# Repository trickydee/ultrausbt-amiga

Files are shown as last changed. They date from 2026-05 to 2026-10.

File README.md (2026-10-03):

# Amiga USB & Bluetooth Adapter

## Overview

This project uses a Raspberry Pi Pico to connect modern USB and Bluetooth devices such as keyboards, mice, trackballs and gamepads to classic Amiga computers — without needing a USB stack on the Amiga itself.

The project was created so I could connect my modern peripherals with my Amiga 2000, the device has a Keyboard and 2 x Atari style Joystick connectors to interface with the Amiga.

The example adapter hardware for the project is focused on the Amiga 2000, although it can be adapted easily for other Amigas.

The adapter is bi-directional:

* **Device Mode** (default): modern USB/Bluetooth HID → Amiga keyboard, mouse, joystick, and CD32 pad signalling
* **Host Mode**: real Amiga keyboard + Port 1 mouse + Port 2 Atari stick → USB HID keyboard/mouse/gamepad on a modern PC

Joystick/CD32 pads are supported toward the Amiga in Device Mode. In Host Mode, Port 2 accepts an Atari-style two-button stick as a USB HID gamepad (Mega Drive pads deferred — see [`doc/host-mode-port2-joystick.md`](./doc/host-mode-port2-joystick.md)).

The device is connected to the Amiga using straight through cables, I am using 2 x 9 Pin DSub to Dsub and 1 x 5 Pin DIN (MIDI) cables.

On a **Pico 2 W** you can mix USB and Bluetooth devices. USB-only builds work on any Pico / Pico 2.

**This project is a fork of [amigahid-pico](https://github.com/borb/amigahid-pico)** by **just nine** (borb). That project is the foundation for Amiga keyboard and mouse signalling on the Pico. This fork builds on that work for the ultrausbt Amiga Adapter board: OLED UI, dual joystick ports, CD32 pad protocol, Bluetooth (Bluepad32), many modern USB controllers, and USB **device** mode (Amiga keyboard/mouse → PC).

Please visit and star the upstream project:  
**https://github.com/borb/amigahid-pico**

Current firmware: **v4.2.0** (`main`) · [Release notes](./RELEASE_NOTES.md) · Architecture: [`doc/architecture.md`](./doc/architecture.md) · License: [EPL-2.0](./LICENSE) · [NOTICE](./NOTICE)

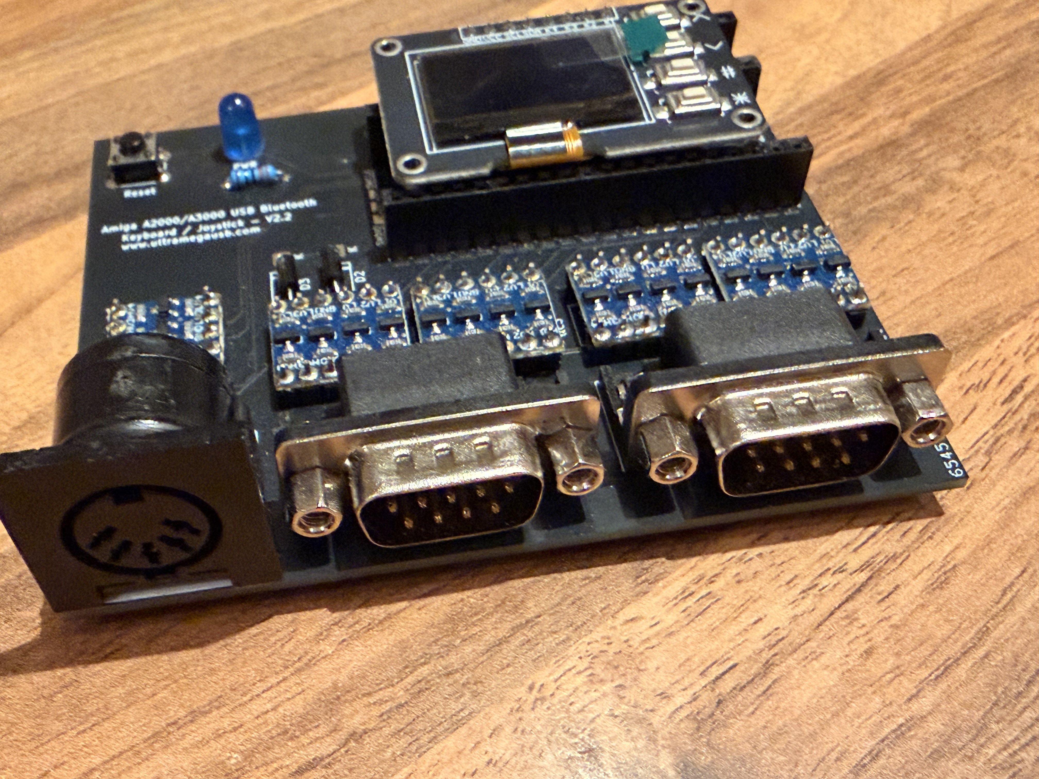
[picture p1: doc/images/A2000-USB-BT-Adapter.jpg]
A2000 USB/BT Adapter


## Contributions

This project is open source and I am happy to receive pull requests and issues to further improve capabilities.

## USB device support

* USB HID Keyboards
* USB HID Mice
* USB HID Gamepads / Joysticks (see below)

## Game controller support

The following USB HID gamepads / joysticks are supported (more to come):

* PlayStation 3 DualShock 3 (and third-party PS3-compatible pads: HORI, Mad Catz, Qanba, Nacon, Logitech F310, etc.)
* PlayStation 4 DualShock 4 (and third-party PS4-compatible pads)
* PlayStation 5 DualSense and DualSense Edge (USB)
* PlayStation Classic (PSC)
* Xbox XInput — Xbox 360 / One / OG (plus HID fallback)
* Nintendo Switch Pro Controller, Joy-Con (L/R/Pair/Grip), SNES Controller (NSO)
* HORI HORIPAD for Nintendo Switch
* Google Stadia Controller

Other USB HID gamepads may work via the generic path (directions + up to three buttons). Gamepads map to **Joystick Port 2** by default; Port 1 can be switched to joystick / Llamatron / CD32 mode from the OLED or keyboard shortcuts.

## Bluetooth support (Pico 2 W)

Bluetooth keyboards, mice, and gamepads are supported on the **Raspberry Pi Pico 2 W** (RP2350) via [Bluepad32](https://github.com/ricardoquesada/bluepad32). You can run a fully wireless Amiga setup, or mix USB and Bluetooth devices.

### Pairing

1. On the OLED splash screen, hold **Middle + Left** (# + Up) to enable pairing (or wait for the short post-boot pairing window).
2. Put your device into Bluetooth pairing mode.
3. Confirm the device on the OLED **Devices** / **Map Devices** screens.

To clear stored pairing keys, open the OLED **Settings** page on the screen carousel (`#` from Map Devices), select **Clear BT pair**, confirm with `#`.

To turn pairing back on after it has timed out or been turned off: **Settings → Pair ON** (or **Middle + Left** / # + Up on Splash).

**Note:** Bluetooth support is intended for Pico 2 W. Prefer Pico 2 W for wireless builds.

# Usage

## USB

Connect devices to the Pico USB port (use a powered USB OTG hub if you need multiple devices). Supported keyboards, mice, and gamepads should enumerate within a few seconds; confirm on the OLED. If you find a modern device that does not work, open an issue.

## Bluetooth

See **Bluetooth support** above. Pairing is controlled from the OLED splash screen. Keyboard shortcuts work the same on USB and Bluetooth keyboards.

## Keyboard shortcuts

The adapter uses a number of Keyboard shortcut key combinations to toggle features.

These combos are handled by the adapter (USB **and** Bluetooth keyboards) and are **not** passed through to the Amiga. **Left Amiga** = Left Command / Left GUI / Left Windows on PC/Mac keyboards.

| Shortcut | Function |
|---|---|
| **Ctrl + Left Amiga + Right Amiga** | Amiga hard reset (classic) |
| **Ctrl + Left Amiga + Backspace** | Amiga hard reset (alternate for keyboards without Right Amiga/GUI) |
| **Shift + Left Amiga + J** | Toggle Port 1 between Amiga mouse and joystick |
| **Shift + Left Amiga + L** | Toggle Llamatron / Robotron style twin-stick mode (Port 2 move + Port 1 aim) |
| **Shift + Left Amiga + C** | Toggle Port 2 CD32 seven-button pad mode |

Port 1 full cycle (Ami Ms → Joy → CD32 → Llama → Atr Ms) is on the OLED **Left** button. Reset is signalled by holding the Amiga keyboard **CLOCK** line low (as a real Amiga keyboard MCU does), with a minimum hold time so it still works when a keyboard drops a combo key from its HID report.

Optional: remap one HID scancode to Amiga **Help** via `KEY_REMAP_HID_TO_HELP` in `src/config.h` (default: Logitech MX `| / ~ #` key). Set to `0` to disable. This is useful for mapping the quit key in WHDload.

### Llamatron dual-stick mode

**Shift + Left Amiga + L** enables Llamatron / twin-stick style routing (one dual-stick gamepad shared across ports: left stick → Port 2 move, right stick → Port 1 aim). Works with **Port 2 CD32** on; mutually exclusive with **Port 1 CD32**. See the OLED Port 1 mode label (**Llama**).

### CD32 seven-button mode

**CD32 pad emulation is complete and working** on both ports:

* **Port 2:** **Shift + Left Amiga + C**, or OLED **Right** (Joy ↔ CD32)
* **Port 1:** OLED **Left** cycle to **CD32** (Ami Ms → Joy → CD32 → Llama → Atr Ms)

Uses the Amiga CD32 serial pad protocol (seven buttons + D-pad). Compatible with Llamatron on Port 2 CD32; exclusive with Port 1 CD32. Protocol detail: [`doc/archive/CD32_BUILD_SPEC.md`](./doc/archive/CD32_BUILD_SPEC.md).

# OLED UI

An SSD1306 OLED and three buttons are supported on the ultrausbt Amiga board (optional for a bare Pico, but recommended). On modules with **Up / Down / #** keys: **Up** = Left, **Down** = Right, **#** = Middle.

The UI is a **screen carousel**: press **#** to advance pages (wraps to Splash).

| Mode | Carousel sequence |
|---|---|
| **Device Mode** (USB/BT → Amiga) | Splash → Devices → Map Devices → Settings → Splash |
| **Host Mode** (Amiga kbd/mouse → PC) | Splash → Settings → Splash (Devices / Map Devices hidden) |

| Control | Action |
|---|---|
| **Left** (Up) | Splash/Devices: cycle Port 1 (Ami Ms → Joy → CD32 → Llama → Atr Ms). Settings: move cursor up |
| **Right** (Down) | Splash/Devices: cycle Port 2 (Joy ↔ CD32). Settings: move cursor down |
| **Middle** (#) | Advance screen carousel; on Settings: confirm selection |
| **Middle + Left** (# + Up) | Toggle Bluetooth pairing (Splash) |
| **Settings → Clear BT pair** | Clear stored Bluetooth pairing keys (`#` then confirm) |
| **Settings → Pair ON / Pair OFF** | Enable or disable Bluetooth pairing (label is the target state) |
| **Settings → Host Mode / Device Mode** | Switch to that role (`#` saves and reboots); label is the target, not current |
| **Settings → Back** | Return to Splash (default selection) |

Splash shows **Device Mode**, both ports in large type (`1:Ami Ms` / `2:Joy`), pairing status bottom-left, and firmware version bottom-right. **Ami Ms** = Amiga mouse, **Atr Ms** = Atari ST mouse pinout on Port 1.

OLED UX conventions (carousel, in-page select, confirms): [`doc/archive/oled-ui-style-guide.md`](./doc/archive/oled-ui-style-guide.md).

# USB Host Mode (Amiga keyboard / mouse / Port 2 stick on a PC)

The adapter can run in reverse: read a real Amiga keyboard (KCLK/KDAT), Port 1 mouse, and an **Atari-style two-button joystick on Port 2**, and present itself to a host PC (or MiSTer) as a composite USB HID keyboard + mouse + gamepad.

* Toggle from the OLED **Settings** carousel page (**Host Mode** / **Device Mode**); the board saves the role and reboots.
* In Host Mode the carousel is Splash ↔ Settings only.
* Port 2: straight DB-9 cable; directions + fire (pin 6) + button 2 (pin 9). No remapper needed for Atari sticks.
* Protocol and diagnostics: [`doc/archive/amiga-usb-device-mode.md`](./doc/archive/amiga-usb-device-mode.md). Research / future Mega Drive: [`doc/host-mode-port2-joystick.md`](./doc/host-mode-port2-joystick.md).

# Hardware

Note: The hardware adapter for this project is unique to this repo; the GPIOs differ from the original amigahid-pico adapters by nine/borb.

The [`kicad/`](./kicad/) directory includes an **Amiga 2000** reference board design and manufacturing gerbers (**Amiga 2000 Adapter v2.4**, `amiga-generic-dsub.*` + [`kicad/gerbers/`](./kicad/gerbers/)). More board designs will follow.

Firmware board maps:

* **Rev 5** — level-shifted Amiga I/O (`HIDPICO_REVISION=5` in root `CMakeLists.txt`)
* **Rev 6** — direct 5V-tolerant I/O on Pico 2 / Pico 2 W; Port 2 fire/B2/B3 on GPIO 16/17/18; OLED buttons on ADC 26/27/28 — see [`doc/gpio_rev6_adc_avoidance.md`](./doc/gpio_rev6_adc_avoidance.md)

Historical upstream PCB notes/errata (amigahid-pico / borb) remain in [`doc/archive/borb-amigahid-hardware.md`](./doc/archive/borb-amigahid-hardware.md) and [`doc/archive/borb-amigahid-errata.md`](./doc/archive/borb-amigahid-errata.md).

# Building the firmware

The firmware can either be downloaded pre built from the Releases section, or you can build yourself with the 'build-all.sh' script. 

```bash
# Default: Pico 2 W → dist/
./build-all.sh

# Incremental rebuild
CLEAN_BUILD_DIRS=0 ./build-all.sh

# Multiple boards
BUILD_BOARDS=pico,pico2_w ./build.sh
BUILD_BOARDS=all ./build-all.sh
```

Flash the matching `.uf2` from `dist/` (hold **BOOTSEL**, copy to the RPI-RP2 drive).

Board revision is set in the root `CMakeLists.txt` (`HIDPICO_REVISION=5` or `6`).

By default the serial console shows boot info and device connect/disconnect messages. For verbose dumps, uncomment `DEBUG_MESSAGES=1` in `CMakeLists.txt`, or set `CONTROLLER_DEBUG` / `KEYBOARD_IN_DEBUG` in `src/config.h`.

# Documentation

Index: [`doc/README.md`](./doc/README.md)

| Doc | Topic |
|-----|---|
| [`RELEASE_NOTES.md`](./RELEASE_NOTES.md) | Firmware changelog |
| [`doc/architecture.md`](./doc/architecture.md) | Architecture + developer/agent quickstart |
| [`doc/future_work.md`](./doc/future_work.md) | Known limitations / roadmap |
| [`doc/gpio_rev6_adc_avoidance.md`](./doc/gpio_rev6_adc_avoidance.md) | Rev 6 pin rationale |
| [`doc/BT_PAIRING_BEST_PRACTICES.md`](./doc/BT_PAIRING_BEST_PRACTICES.md) | Bluetooth pairing |
| [`doc/archive/`](./doc/archive/) | Detailed / historical notes |

# Acknowledgements

**Upstream — please support the original project:**

* **[amigahid-pico](https://github.com/borb/amigahid-pico)** by **just nine** \<[nine@aphlor.org](mailto:nine@aphlor.org)\> — the original Amiga HID-on-Pico work this firmware forks and extends. Without that project this adapter would not exist.

The “ultrausbt” name is tongue-in-cheek and highlights the capabilities made possible by TinyUSB, Bluepad32, and the Pico ecosystem.

This fork also relies on:

* [Raspberry Pi Pico SDK](https://github.com/raspberrypi/pico-sdk) — RP2040 / RP2350 platform
* [TinyUSB](https://github.com/hathach/tinyusb) by Ha Thach — USB host and device stacks
* [Bluepad32](https://github.com/ricardoquesada/bluepad32) by Ricardo Quesada — Bluetooth HID gamepads, keyboards, and mice
* [BTstack](https://github.com/bluekitchen/btstack) (via Pico SDK / Bluepad32) — Bluetooth controller stack
* [pico-ssd1306](https://github.com/daschr/pico-ssd1306) by David Schramm — OLED display driver
* [tusb_xinput](https://github.com/Ryzee119/tusb_xinput) by Ryzee119 — Xbox XInput host path for TinyUSB
* CD32 protocol analysis via [PSCD32 Development Diary](https://www.mrdictionary.net/PSCD32/diary/2019_08_09.htm) (Mathew Carr) and related pad schematics

**Other Projects**
I also have a number of other Retro Computer adapter projects:
[Atari Mega ST/TT IKBD - USB/BT Adapater](https://github.com/trickydee/ultrausbt-atari-st-rpikbd).
[Apple ADB - USB/BT Adapater](https://github.com/trickydee/ultrausbt-apple-adb-adapter).
[PC XT / AT / PS2 - USB/BT Adapater](https://github.com/trickydee/TBC).

**This ultrausbt Amiga fork** is maintained by [trickydee](https://github.com/trickydee) ([ultrausbt-amiga](https://github.com/trickydee/ultrausbt-amiga)). A large portion of the code and documentation was developed with [Cursor](https://cursor.com) and supporting LLMs — this project would not exist in its current form without those tools, on top of the open-source foundations above.

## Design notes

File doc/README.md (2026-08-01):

# ultrausbt-amiga documentation

Public docs for the Amiga USB/Bluetooth adapter firmware (Pico / Pico 2 / Pico 2 W).

## Start here

| Doc | Audience |
|-----|---|
| [`../README.md`](../README.md) | Features, shortcuts, build & flash |
| [`architecture.md`](./architecture.md) | Platform architecture + developer/agent quickstart |
| [`../RELEASE_NOTES.md`](../RELEASE_NOTES.md) | Firmware changelog |
| [`gpio_rev6_adc_avoidance.md`](./gpio_rev6_adc_avoidance.md) | Why Rev 6 moved Port 2 / OLED pins |

## Features

| Doc | Topic |
|-----|---|
| [`BT_PAIRING_BEST_PRACTICES.md`](./BT_PAIRING_BEST_PRACTICES.md) | Bluetooth pairing on Pico 2 W |
| [`host-mode-port2-joystick.md`](./host-mode-port2-joystick.md) | Host Mode Port 2: Atari stick → USB (done); Mega Drive research (on hold) |
| [`future_work.md`](./future_work.md) | Known limitations & roadmap |
| [`submodule-versions.md`](./submodule-versions.md) | Pinned SDK / Bluepad32 / TinyUSB versions |

## Legal

| File | Topic |
|---|---|
| [`../LICENSE`](../LICENSE) | Eclipse Public License 2.0 |
| [`../NOTICE`](../NOTICE) | Copyright & upstream credit |

## Archive

Older investigations, build specs, and detailed troubleshooting live in [`archive/`](./archive/) (not required for day-to-day use):

| Doc | Topic |
|-----|---|
| [`archive/stadia-controller-verification.md`](./archive/stadia-controller-verification.md) | Stadia / Core 1 mouse verification notes |
| [`archive/borb-amigahid-hardware.md`](./archive/borb-amigahid-hardware.md) | Upstream hardware notes (amigahid-pico / borb) |
| [`archive/amiga-code-atari-board-gpio-mappings.md`](./archive/amiga-code-atari-board-gpio-mappings.md) | Rev 5 / Rev 6 GPIO map (detail) |
| [`archive/borb-amigahid-errata.md`](./archive/borb-amigahid-errata.md) | Upstream PCB errata (amigahid-pico / borb) |
| [`archive/device_troubleshooting.md`](./archive/device_troubleshooting.md) | Device / BT troubleshooting detail |
| [`archive/amiga-usb-device-mode.md`](./archive/amiga-usb-device-mode.md) | Amiga keyboard/mouse → PC (protocol detail) |
| [`archive/CD32_BUILD_SPEC.md`](./archive/CD32_BUILD_SPEC.md) | CD32 implementation build spec |

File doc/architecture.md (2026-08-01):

# ultrausbt-amiga Architecture

This document describes the core platform architecture, how USB and Bluetooth integrate with the adapter, how to add USB controllers, how Bluepad32 is wired in, and how signaling is performed toward the Amiga.

## 1) System Overview

`ultrausbt-amiga` runs on RP2040/RP2350-based Pico hardware and supports two runtime USB roles:

- `USB_MODE_HOST` (normal adapter path): USB/Bluetooth input devices are translated into Amiga keyboard/mouse/joystick/CD32 electrical signaling.
- `USB_MODE_DEVICE` (reverse path / UI **Host Mode**): real Amiga keyboard, Port 1 mouse, and Port 2 Atari stick are read and re-exposed as USB HID keyboard + mouse + gamepad to a modern host (PC/Mac/Linux/MiSTer).

The role is persisted in flash and selected at boot.

## 2) Core Components

### Boot + orchestration

- `src/main.c`
  - Performs board and GPIO-safe initialization.
  - Loads persisted USB mode via `usb_mode_init()`.
  - Starts TinyUSB in host or device role via `usb_mode_start_usb()`.
  - In host mode initializes Amiga output subsystems and (optionally) Bluepad32.
  - Runs the main event loop dispatching USB tasks, Amiga services, Bluetooth polling, and OLED UI.

### USB role control and persistence

- `src/usb_mode.c`, `src/usb_mode.h`
  - Stores active role in `usb_mode_t`.
  - Reads persisted config from flash through port config storage.
  - Handles role toggle requests (`usb_mode_request_toggle()`), immediate flash write, verify, and reboot.
- `src/platform/amiga/mouse_config.c`
  - Persists config blob (mouse type, port modes, CD32 mode, USB role).
  - Supports deferred writes during BT critical sections and explicit immediate writes for USB-role toggles.

### USB host ingestion + routing

- `src/usb_hid.c`
  - TinyUSB host HID callbacks:
    - mount/unmount: device classification and registration
    - report receive: protocol/vendor-specific parser routing
  - Routes keyboard reports to Amiga keyboard serializer.
  - Routes mouse reports to:
    - quadrature mouse output, or
    - joystick conversion (when Port 1 is in joystick mode).
  - Routes gamepad data to joystick/CD32 submission paths.
- `src/usb_controllers/*.c`
  - Vendor-specific handlers for PS3/PS4/PS5/Stadia/Switch/Xbox/Hori/PSC.
  - Each module normalizes controller reports and submits canonical direction/button state.

### Bluetooth integration (Bluepad32 + BTstack + CYW43)

- `src/bluepad32_init.c`
  - Brings up async context, CYW43, BTstack run loop, and Bluepad32 core (`uni_init`).
- `src/bluepad32_platform.c`
  - Custom Bluepad32 platform callbacks for discovery/connect/ready/disconnect/data.
  - Tracks multiple BT keyboards/mice/gamepads and exposes accessor functions.
  - Manages pairing window and pairing on/off lifecycle.
  - Contains Core 1 pause/resume coordination for gamepad enumeration edge-cases.
- `src/usb_hid.c` (`process_bluepad32_*`)
  - Converts Bluepad32 keyboard/mouse/gamepad payloads into the same Amiga-facing handlers used by USB host input.

### Amiga signaling outputs / inputs

- Keyboard out: `src/platform/amiga/keyboard_serial_io.c`
- Mouse quadrature out: `src/platform/amiga/quad_mouse.c`
- Joystick Port 1 out: `src/platform/amiga/joystick_port1.c`
- Joystick Port 2 out: `src/platform/amiga/joystick_port2.c`
- Mode manager: `src/platform/amiga/port_mode.c`
- Reverse keyboard in (Amiga -> USB): `src/platform/amiga/keyboard_host_in.c`
- Reverse mouse in (Amiga -> USB): `src/platform/amiga/mouse_host_in.c`
- Reverse Port 2 stick in (Atari -> USB gamepad): `src/platform/amiga/joystick_port2_host_in.c`

### UI + device map

- `src/display/display.c`
  - Splash/device/settings screens, mode switches, pairing control.
- `src/usb_device_map.c`
  - Maintains USB device name slots used by OLED map/devices views.

## 3) End-to-End Data Paths

### Host mode (USB/BT -> Amiga)

1. TinyUSB host enumerates device (`tuh_task()` loop).
2. `usb_hid.c` receives reports and dispatches:
   - keyboard -> `amiga_hid_send()` path
   - mouse -> quadrature or Port1 joystick conversion
   - gamepad -> canonical submit functions (port gamepad/CD32 paths)
3. Bluepad32 device data is polled and fed into the same logical handlers.
4. Amiga GPIO lines are driven active-low with open-drain-safe behavior.

### Device mode (Amiga -> USB HID) — UI name **Host Mode**

1. TinyUSB device stack (`tud_task()`) enumerates as HID keyboard+mouse (IF0) + gamepad (IF1).
2. Amiga keyboard serial receive ISR/task reconstructs keycodes and modifiers.
3. Amiga quadrature mouse polling decodes movement/button state.
4. Port 2 Atari stick polling (`joystick_port2_host_in_task`) builds digital axes/hat/buttons.
5. `usb_hid_device_task()` publishes HID reports to the USB host.

## 4) USB + Bluetooth Integration Model

USB and Bluetooth are not separate adapters; they feed a shared internal input normalization layer:

- USB host devices arrive through TinyUSB host callbacks.
- Bluetooth devices arrive through Bluepad32 platform callbacks and accessors.
- Both are converted into common logical actions (key down/up, relative mouse delta, directional/button bitfields).
- Common Amiga output modules consume those actions and emit electrical signals.

Concurrency notes:

- Core 0 runs USB task loop, Bluepad32 polling, UI, and high-level routing.
- Core 1 runs high-frequency quadrature synthesis loop for smooth mouse output.
- Flash writes and BT discovery are coordinated with Core 1 pause/watchdog logic to avoid lockups.

## 5) How USB Controllers Are Added

### Existing pattern

Controller modules in `src/usb_controllers/` follow a standard shape:

1. `*_is_controller(vid,pid)` or equivalent matcher.
2. `*_mount_cb(dev_addr)` and `*_unmount_cb(dev_addr)` lifecycle hooks.
3. `*_process_report(dev_addr, report, len)` parser/translator.
4. Submit normalized output to shared Amiga-facing calls:
   - `port2_gamepad_submit(...)`, `port1_gamepad_submit(...)`, or
   - direct joystick set_direction/set_button where appropriate.

The dispatcher wiring happens in `src/usb_hid.c`:

- include module header
- add VID/PID detection in mount/unmount/report callbacks
- invoke module callbacks

### Recommended implementation steps

1. Add new files:
   - `src/usb_controllers/<name>_controller.h`
   - `src/usb_controllers/<name>_controller.c`
2. Define VID/PID matcher and report struct/layout parser.
3. Map source controls to adapter-neutral outputs (`dir_bits`, fire/B2/B3, optional CD32 shoulders/start).
4. Register/unregister OLED device name via `usb_map_register_gamepad()`/`usb_map_unregister_gamepad()`.
5. Wire module into `usb_hid.c` mount/unmount/report routing.
6. Validate in both normal joystick and CD32 mode behavior.

## 6) Bluepad32 Integration Details

Bluepad32 is integrated as a custom platform layer:

- Initialization:
  - build async context
  - set CYW43 async context before chip init
  - initialize CYW43 + BTstack run loop
  - set custom `uni_platform` handlers
  - call `uni_init()`
- Runtime:
  - `bluepad32_poll()` pumps BTstack.
  - `my_platform_on_controller_data()` captures latest keyboard/mouse/gamepad payloads.
  - `process_bluepad32_devices()` in `usb_hid.c` translates data into existing USB-style handlers.
- Pairing:
  - controlled by `bluepad32_pairing_start/stop/tick`
  - boot pairing window timeout logic
  - key deletion support for re-pair workflows
- Robustness:
  - Core 1 pause/watchdog/resume mechanisms for problematic BT discovery/reconnect cases.

## 7) How Signaling to the Amiga Is Performed

All primary Amiga-facing outputs are active-low GPIO semantics (line driven low = asserted), with safe initialization to input/high state to avoid back-feeding.

### Keyboard signaling (Amiga keyboard serial protocol)

- Module: `keyboard_serial_io.c`
- Uses `/DAT`, `/CLK`, `/RST` lines.
- On key transitions, HID->Amiga translation produces Amiga scan code events.
- Transmit encodes key up/down into 8-bit framed codes and bit-bangs:
  - set DAT bit
  - pulse CLK
  - timing delays per bit.
- Supports hard reset chord behavior by asserting reset-related lines.

### Mouse signaling (quadrature)

- Module: `quad_mouse.c`
- Core 0 accumulates HID motion deltas into atomic backlog.
- Core 1 consumes backlog, applies queue/direction handling, and emits phased quadrature waveforms on H/HQ and V/VQ.
- Update rates differ for Amiga vs Atari timing profiles.
- Port 1 joystick/CD32 modes gate or pause quadrature output as needed.

### Joystick/CD32 signaling

- Modules: `joystick_port1.c`, `joystick_port2.c`, `cd32_pad.c`, `port*_gamepad.c`
- Direction and button states are translated to active-low GPIO assertions.
- CD32 modes reuse canonical submissions but emit broader button sets where supported.

### Reverse signaling (Amiga -> USB mode)

- Keyboard input:
  - ISR on keyboard clock falling edge samples DAT bits.
  - Reconstructs Amiga frame -> HID key/modifier state.
  - Sends via `usb_hid_device_send_keyboard()`.
- Mouse input:
  - Poll quadrature states, decode Gray-code transitions into deltas.
  - Emit HID mouse reports via `usb_hid_device_send_mouse()`.
- Port 2 Atari stick input:
  - Poll dirs/fire/B2 as inputs with pull-ups (`joystick_port2_host_in.c`).
  - Emit HID gamepad on IF1 via `usb_hid_device_send_gamepad(x, y, hat, buttons)`.
  - Dirs on Axis 0/1 + hat; fire = B0; do **not** use buttons 12–15 (Mode clash on MiSTer).
  - Detail: [`host-mode-port2-joystick.md`](./host-mode-port2-joystick.md).

## 8) Architecture Diagrams

### 8.1 System context (hardware interfaces)

```text
                           +----------------------------------+
                           |          RP2040 / RP2350         |
                           |                                  |
                           |  Core 0                          |
 USB Host Port <---------->|  - TinyUSB host/device task      |
 (or USB Device to PC)     |  - Input routing / mode logic    |
                           |  - OLED UI / config persistence  |
                           |  - Bluepad32 polling             |
                           |                                  |
 Bluetooth (CYW43) <------>|  Bluepad32 + BTstack platform    |
                           |                                  |
                           |  Core 1                          |
                           |  - Quadrature mouse waveform gen |
                           +----------------+-----------------+
                                            |
                                            | Active-low GPIO signals
                                            v
      +---------------------+----------------------+----------------------+
      |                     |                      |                      |
  Amiga Keyboard        Amiga Port 1          Amiga Port 2          /KBRST
  /DAT /CLK /RST        Mouse/Joystick/CD32   Joystick/CD32         reset control
  bit-banged serial     quadrature + buttons  directions + buttons
```

### 8.2 Software block diagram (host mode: USB/BT → Amiga)

Shows module layers and the shared normalization path. Arrows are logical data flow.

```text
+==========================================================================+
|                              main.c                                      |
|  boot → usb_mode_init / start_usb → init Amiga outs (+ BT) → main loop   |
+==========================================================================+
          |                              |                         |
          v                              v                         v
+---------------------+    +---------------------------+   +----------------+
| TinyUSB Host        |    | Bluepad32 stack           |   | display.c      |
| tuh_task()          |    | bluepad32_init.c          |   | OLED screens / |
|                     |    | bluepad32_platform.c      |   | buttons / pair |
| usb_hid.c           |    |   slots: kb / mouse / pad |   +--------+-------+
|  mount / umount /   |    |   pairing + accessors     |            |
|  report callbacks   |    +-------------+-------------+            |
+----------+----------+                  |                          |
           |                             |                          |
           |  vendor pads                |  process_bluepad32_*     |
           v                             v                          |
+---------------------+    +---------------------------+            |
| usb_controllers/*   |    | Shared handlers in        |            |
| PS3/4/5 Stadia      |--->| usb_hid.c                 |<-----------+
| Switch Xbox Hori…   |    |  handle_event_keyboard    |  (counts /
+---------------------+    |  handle_event_mouse       |   map UI)
                           |  process_bluepad32_gamepad|
                           +-------------+-------------+
                                         |
                    normalized events    |
         (HID keycodes, mouse dx/dy,     |
          dir_bits + face/shoulder/start)|
                                         v
              +--------------------------+--------------------------+
              |              Amiga output layer                     |
              |                                                     |
              |  keyboard_serial_io.c   amiga_hid_send / bit-bang   |
              |  quad_mouse.c           Core0 feed → Core1 waves    |
              |  joystick_port1.c       Port1 dirs / buttons        |
              |  joystick_port2.c       Port2 dirs / buttons        |
              |  port1/2_gamepad.c      classic vs CD32 submit      |
              |  cd32_pad.c             CD32 shift protocol         |
              |  port_mode.c            mouse/joy/CD32/Llama state  |
              +--------------------------+--------------------------+
                                         |
                                         v
                                    Amiga GPIO
```

### 8.3 Software block diagram (device mode: Amiga → PC)

```text
+==========================================================================+
|                              main.c                                      |
|  usb_mode = DEVICE → kbd/mouse/joy2 host_in → tud_task loop              |
+==========================================================================+
     |                        |                         |              |
     v                        v                         v              v
+----------------+  +------------------+  +------------------------+ +-----------+
| keyboard_      |  | mouse_host_in.c  |  | joystick_port2_       | | display.c |
| host_in.c      |  | poll quad+btns   |  | host_in.c             | | Splash↔   |
| KCLK → HID kbd |  | → HID mouse      |  | Atari dirs/fire/B2    | | Settings  |
+-------+--------+  +--------+---------+  | → HID gamepad         | +-----------+
        |                    |            +-----------+------------+
        |                    |                        |
        |  usb_hid_device_send_*                      |
        v                    v                        v
        +--------------------+------------------------+
                             |
                             v
                  +---------------------------+
                  | usb_hid_device.c           |
                  | IF0: kbd + mouse          |
                  | IF1: gamepad (macOS/Chrome|
                  |      need separate IF)    |
                  +-------------+-------------+
                                |
                                v
                           USB to PC / MiSTer
```

Cross-cutting (both modes):

```text
+------------------+     +--------------------+     +------------------+
| usb_mode.c       |---->| mouse_config.c     |<----| port_mode.c      |
| role select /    |     | flash: mouse type, |     | apply Port1/2    |
| reboot toggle    |     | ports, USB role    |     | persisted modes  |
+------------------+     +--------------------+     +------------------+
```

## 9) Key Design Characteristics

- Single codebase supports both adapter direction modes through runtime USB role selection.
- USB and Bluetooth share normalization paths to reduce duplicate logic.
- Timing-sensitive mouse quadrature is isolated on Core 1.
- Flash persistence is coordinated with BT/Core1 constraints for runtime stability.
- Port-mode abstraction allows runtime behavior changes (mouse, joystick, Atari mapping, CD32, Llamatron).

## 10) Developer / Agent Quickstart

Use this section when onboarding a human developer or an AI agent into the codebase.

### Orientation (5 minutes)

| Question | Answer |
|---|---|
| Firmware version | `SOFTWARE_VERSION_*` in `src/config.h` (also mirrored in `README.md`, `RELEASE_NOTES.md`) |
| Board revision | `HIDPICO_REVISION` in root `CMakeLists.txt` (`5` or `6`) |
| Default USB role | Host = USB/BT → Amiga; Device = Amiga → PC HID |
| Main loop | `src/main.c` |
| USB report dispatch | `src/usb_hid.c` |
| BT platform | `src/bluepad32_platform.c` + `src/bluepad32_init.c` |
| Amiga outputs | `src/platform/amiga/` |
| OLED UI | `src/display/display.c` |
| Docs index | `doc/README.md` |

**Do not reinvent:** USB and BT inputs both normalize into the same Amiga-facing APIs (`amiga_hid_send`, `amiga_quad_mouse_*`, `port2_gamepad_submit`, etc.). Prefer extending an existing controller module pattern over inventing a parallel path.

### Build & flash

```bash
# Default Pico 2 W → dist/
./build-all.sh

# Incremental
CLEAN_BUILD_DIRS=0 ./build-all.sh
```

Flash the matching `.uf2` from `dist/` (BOOTSEL → RPI-RP2). Serial console shows boot banner and plug/unplug by default.

Debug toggles:

- `DEBUG_MESSAGES=1` via CMake compile definitions (DIAG / ahprintf)
- `CONTROLLER_DEBUG` / `KEYBOARD_IN_DEBUG` in `src/config.h`

### Agent “edit map” — where to change what

| Goal | Primary files |
|---|---|
| Add USB gamepad | `src/usb_controllers/<name>_controller.{c,h}`, `src/CMakeLists.txt`, `src/usb_hid.c` |
| Fix mouse feel / timing | `src/platform/amiga/quad_mouse.c` |
| Keyboard HID→Amiga map | `src/platform/amiga/keyboard.h` + `keyboard_serial_io.c` |
| Port modes (mouse/joy/CD32/Llama) | `src/platform/amiga/port_mode.c` |
| USB host↔device role | `src/usb_mode.c`, `mouse_config.c`, OLED Settings in `display.c` |
| Host Mode Port 2 stick → PC | `joystick_port2_host_in.c`, `usb_hid_device.c` (`CFG_TUD_HID` = 2) |
| BT pairing / device slots | `src/bluepad32_platform.c` |
| OLED screens / buttons | `src/display/display.c` |
| GPIO pin map | `src/config.h` (`HIDPICO_REVISION`) |
| Version bump | `src/config.h`, then `README.md`, `RELEASE_NOTES.md`, `doc/future_work.md` |

### Checklist: add a USB controller

Copy the shape of `stadia_controller` or `ps4_controller` — they are the clearest templates.

1. **Create module**
   - `src/usb_controllers/<name>_controller.h`
   - `src/usb_controllers/<name>_controller.c`
2. **Implement the contract**
   - `bool <name>_is_controller(uint16_t vid, uint16_t pid);`
   - `void <name>_mount_cb(uint8_t dev_addr);`
   - `void <name>_unmount_cb(uint8_t dev_addr);`
   - `void <name>_process_report(uint8_t dev_addr, const uint8_t *report, uint16_t len);`
3. **Normalize and submit**
   - Directions: `dir_bits` with bit0=up, bit1=down, bit2=left, bit3=right
   - Buttons: map to `port2_gamepad_submit(dir_bits, face_a, face_b, face_x, face_y, l, r, start)`
   - Prefer `port2_gamepad_submit` over raw GPIO — it handles classic vs CD32 Port 2
4. **OLED name**
   - Mount: `usb_map_register_gamepad(dev_addr, "ShortName");`
   - Unmount: `usb_map_unregister_gamepad(dev_addr);` + `port2_gamepad_clear();`
5. **Wire into the build**
   - Add `.c` to `src/CMakeLists.txt` under the existing `usb_controllers/` list
6. **Wire into the dispatcher** (`src/usb_hid.c`)
   - `#include "usb_controllers/<name>_controller.h"`
   - In `tuh_hid_mount_cb` / `tuh_hid_umount_cb` / `tuh_hid_report_received_cb` (and the desktop-gamepad branch in `process_report` if needed): detect VID/PID → call module
7. **Build** and flash
8. **Hardware validation** (below)

### Checklist: hardware validation (USB gamepad)

On a live Amiga (or Amiga-compatible port tester):

- [ ] Device appears on OLED **Devices** / **Map Devices** with the expected short name
- [ ] Port 2 directions: up/down/left/right + diagonals
- [ ] Fire / B2 / B3 (classic 3-button map)
- [ ] Unplug → stick recenters / buttons release (`port2_gamepad_clear` path)
- [ ] Toggle Port 2 **CD32** (Shift+Left Amiga+C or OLED Map Devices) → shoulders/start/extra face buttons behave
- [ ] Keyboard + mouse still work while pad is connected (no Core 1 stall / frozen mouse)
- [ ] Serial: mount/unmount messages; with `CONTROLLER_DEBUG=1`, confirm report length/layout once

Optional second-pad / Port 1 checks if the pad is meant to support multi-device:

- [ ] Second gamepad maps correctly when Port 1 is Joy/CD32
- [ ] Llamatron mode (if BT/USB path supports it) left stick → Port 2, right stick → Port 1

### Checklist: Bluetooth change safety

BT work often interacts with Core 1 mouse timing and flash bonding:

- [ ] After pairing / reconnect, mouse still moves (watch for Core 1 pause orphans)
- [ ] Pairing on/off from OLED Settings works; Clear BT pair then re-pair if bonds go stale
- [ ] Prefer `busy_wait_*` inside BT callbacks (not `sleep_ms` / `__wfe`) — see `bluepad32_platform.c`
- [ ] Config saves during BT pause are deferred (`port_config_flush_pending`); USB role toggle must use `port_config_save_immediate`

### Checklist: USB device mode (Amiga → PC / Host Mode UI)

- [ ] OLED Settings → switch to Host Mode UI path (persists + reboots)
- [ ] Real Amiga keyboard types into the PC
- [ ] Port 1 mouse moves cursor; buttons map L/R/M
- [ ] Caps Lock toggle aligns (synthetic pulse path)
- [ ] Port 2 Atari stick → HID gamepad (Axis 0/1 or hat + B0 fire); re-define on MiSTer after firmware changes
- [ ] Switch back to Device Mode (Amiga adapter) and verify host path still works
- [ ] Note: macOS **System Settings → Game Controllers** often ignores generic HID pads; use browser Gamepad API / `ioreg` instead

### Common pitfalls (agents especially)

1. **Skipping `src/CMakeLists.txt`** — new `.c` files are not auto-globbed.
2. **Only wiring mount, not report** — pad shows on OLED but never moves the stick.
3. **Driving joystick GPIOs directly** instead of `port*_gamepad_submit` — breaks CD32 mode.
4. **Touching Core 1 mouse loop casually** — timing regressions show up as lag, reverse, or stalls after BT pairing.
5. **Deferring USB-mode flash writes then rebooting** — role appears “stuck”; use immediate save + verify.
6. **Including Bluepad32 `uni.h` from `usb_hid.c`** — HID type conflicts with TinyUSB; keep BT types isolated behind `bluepad32_platform` accessors and local mirror structs.
7. **Version bump without docs** — update `config.h` + `README.md` + `RELEASE_NOTES.md` together.

### Suggested first tasks for a new agent session

1. Read this file + `README.md` + current `RELEASE_NOTES.md` top entry.
2. Confirm board revision and USB role from serial boot banner.
3. For a bug: identify host vs device mode, then USB vs BT source, then which Amiga output (kbd / mouse Core1 / port1 / port2 / CD32).
4. Make the smallest change in the layer that owns the bug; reuse existing submit/normalize APIs.
5. Build, flash, run the matching validation checklist above.

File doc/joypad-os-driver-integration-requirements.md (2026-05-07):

# Joypad OS Driver Integration Requirements

**Date**: 2025-01-XX  
**Branch**: `joystickos-investigation`

## Answer: Each Driver Requires Integration

**Short answer**: Each driver requires manual integration, and they all depend on Joypad OS's core architecture. You cannot just "enable all drivers" - you must either:

1. **Adopt Joypad OS's full architecture** (router, input_event, player management, feedback)
2. **Port each driver individually** to work with AmigaHID-Pico's architecture (significant work per driver)

## How Joypad OS's Driver System Works

### Driver Registration (Manual)

Each driver must be manually included and registered in `hid_registry.c`:

```c
// 1. Include the driver header
#include "devices/vendors/sony/sony_ds4.h"

// 2. Register it in the registry
void register_devices() {
    device_interfaces[CONTROLLER_DUALSHOCK4] = &sony_ds4_interface;
    // ... repeat for each driver
}
```

**You can selectively include/exclude drivers** - you don't need all of them.

### Driver Interface (Standard)

Each driver implements a `DeviceInterface` struct:

```c
typedef struct {
    const char* name;
    
    // Device identification
    bool (*is_device)(uint16_t vid, uint16_t pid);
    bool (*check_descriptor)(uint8_t dev_addr, uint8_t instance, 
                             uint8_t const* desc_report, uint16_t desc_len);
    
    // Input processing
    void (*process)(uint8_t dev_addr, uint8_t instance, 
                    const uint8_t *report, uint16_t len);
    
    // Output/feedback task (rumble, LEDs)
    void (*task)(uint8_t dev_addr, uint8_t instance, 
                 device_output_config_t* config);
    
    // Lifecycle
    bool (*init)(uint8_t dev_addr, uint8_t instance);
    void (*unmount)(uint8_t dev_addr, uint8_t instance);
    
    // Device capabilities
    uint16_t (*get_capabilities)(void);
} DeviceInterface;
```

## Critical Dependencies

### All Drivers Depend On:

1. **Router System** (`core/router/router.h`)
   - Drivers call `router_submit_input(&event)` to submit input
   - This is Joypad OS's input→output routing system
   - **AmigaHID-Pico doesn't have this** - we directly control GPIO

2. **Input Event Structure** (`core/input_event.h`)
   - Drivers create `input_event_t` structures
   - Standardized format for all input types
   - **AmigaHID-Pico uses ad-hoc structures**

3. **Player Management** (`core/services/players/manager.h`)
   - Tracks which device is assigned to which player
   - **AmigaHID-Pico has fixed mapping** (gamepad 0 → port 2, gamepad 1 → port 1)

4. **Feedback System** (`core/services/players/feedback.h`)
   - Rumble, LED, adaptive trigger management
   - **AmigaHID-Pico doesn't use rumble/LEDs** (Amiga doesn't support)

5. **Button Definitions** (`core/buttons.h`)
   - W3C Gamepad API button order
   - **AmigaHID-Pico uses different button mapping**

### Example Driver Dependencies

Looking at `sony_ds4.c`:

```c
#include "sony_ds4.h"
#include "core/buttons.h"              // Button definitions
#include "core/router/router.h"        // Router system
#include "core/input_event.h"          // Input event structure
#include "core/services/players/manager.h"  // Player management
#include "core/services/players/feedback.h" // Rumble/LED feedback
```

The driver processes input and calls:
```c
input_event_t event = { /* ... */ };
router_submit_input(&event);  // Submit to router system
```

## Integration Options

### Option 1: Full Architecture Adoption (Recommended if adopting)

**Pros:**
- All drivers work immediately
- Clean, modular architecture
- Easy to add new drivers
- Router system enables advanced features (input merging, broadcasting)

**Cons:**
- Major architectural change
- Requires porting AmigaHID-Pico's GPIO control to output interface
- Significant refactoring effort
- May be overkill for AmigaHID-Pico's simpler use case

**Effort**: High (weeks of work)

### Option 2: Port Individual Drivers (Selective)

**Pros:**
- Can pick and choose which drivers to support
- Minimal architectural changes
- Focus on high-value drivers (DS3/DS4/DualSense, Switch Pro)

**Cons:**
- Each driver requires porting work
- Must adapt from `router_submit_input()` to direct GPIO control
- Must adapt from `input_event_t` to AmigaHID-Pico's structures
- Must remove dependencies on player management, feedback system
- Duplicate work for each driver

**Effort**: Medium per driver (days of work each)

### Option 3: Hybrid Approach (Pragmatic)

**Pros:**
- Adopt `input_event_t` structure (low effort, high value)
- Port only high-value drivers (DS3/DS4/DualSense, Switch Pro)
- Keep AmigaHID-Pico's direct GPIO control
- Minimal architectural changes

**Cons:**
- Still requires porting work per driver
- Can't use drivers "as-is"

**Effort**: Medium (days to weeks, depending on how many drivers)

## Recommended Approach

### Phase 1: Adopt Input Event Structure (Low Risk, High Value)

1. **Adopt `input_event_t` structure**:
   - Replace ad-hoc gamepad structures
   - Normalize analog values (0-255, centered at 128)
   - Standard button bitmap

2. **Create adapter functions**:
   - Convert `input_event_t` → Amiga GPIO control
   - Keep existing GPIO control code

**Effort**: Low-Medium (days)

### Phase 2: Port High-Value Drivers (Selective)

Port only the most valuable drivers:
1. **DualShock 3/4/DualSense** - Better button mapping, motion, touchpad
2. **Switch Pro** - Capture/home buttons, motion
3. **Generic HID gamepad** - Already works, but could improve parsing

For each driver:
1. Copy driver code
2. Replace `router_submit_input()` with direct GPIO control
3. Remove dependencies on player management, feedback system
4. Adapt to AmigaHID-Pico's button mapping

**Effort**: Medium per driver (2-3 days each)

### Phase 3: Consider Full Architecture (If Needed)

Only if you need advanced features:
- Multiple gamepads → single port (input merging)
- One gamepad → multiple ports (broadcasting)
- Input transformations (mouse→analog, spinner accumulation)

**Effort**: High (weeks)

## What You Get "For Free"

**Nothing runs automatically** - you must:

1. ✅ **Include driver headers** (easy)
2. ✅ **Register drivers** (easy)
3. ❌ **Port to your architecture** (required for each driver)
4. ❌ **Remove dependencies** (required for each driver)

## Code Example: Porting a Driver

### Original (Joypad OS):
```c
void input_sony_ds4(uint8_t dev_addr, uint8_t instance, 
                    uint8_t const* report, uint16_t len) {
    // Parse DS4 report
    sony_ds4_report_t* ds4 = (sony_ds4_report_t*)report;
    
    // Create input event
    input_event_t event = {
        .buttons = /* map buttons */,
        .analog[ANALOG_LX] = ds4->x,
        .analog[ANALOG_LY] = ds4->y,
        // ...
    };
    
    // Submit to router
    router_submit_input(&event);
}
```

### Ported (AmigaHID-Pico):
```c
void input_sony_ds4(uint8_t dev_addr, uint8_t instance, 
                    uint8_t const* report, uint16_t len) {
    // Parse DS4 report (same)
    sony_ds4_report_t* ds4 = (sony_ds4_report_t*)report;
    
    // Convert to directions/buttons
    bool up = (ds4->dpad == 0 || ds4->dpad == 7 || ds4->dpad == 1);
    bool down = (ds4->dpad == 4 || ds4->dpad == 3 || ds4->dpad == 5);
    // ... map all directions and buttons
    
    // Direct GPIO control (instead of router)
    if (dev_addr == first_gamepad_dev_addr) {
        amiga_joystick_port2_set_direction(AJ2_UP, up);
        amiga_joystick_port2_set_direction(AJ2_DOWN, down);
        // ...
        amiga_joystick_port2_set_button(AJ2_FIRE, ds4->cross);
        // ...
    }
}
```

## Conclusion

**Each driver requires integration work**. You cannot just "enable all drivers" - they all depend on Joypad OS's core architecture (router, input_event, player management, feedback).

**Recommended approach**:
1. Adopt `input_event_t` structure (low effort, high value)
2. Port only high-value drivers (DS3/DS4/DualSense, Switch Pro)
3. Keep AmigaHID-Pico's direct GPIO control (simpler, fits use case)

**Estimated effort**:
- Adopt `input_event_t`: 2-3 days
- Port DS3/DS4/DualSense: 3-5 days
- Port Switch Pro: 2-3 days
- **Total for high-value drivers**: ~1-2 weeks

This gives you the benefits of better device compatibility without the overhead of the full router architecture.

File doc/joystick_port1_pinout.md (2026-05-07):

# Joystick Port 1: DB-9 Pin to GPIO Mapping

## DB-9 Connector Pinout to GPIO Mapping (Revision 4)

Based on the KiCad schematic netlist mapping:

| DB-9 Pin | Signal (Mouse Mode) | Signal (Joystick Mode) | GPIO Pin | GPIO Signal | Description | Active State |
|---|---|---|---|---|---|---|
| 1 | V | UP | 10 | `QM1_AMIGA_V` | Vertical / Up direction | LOW (0) |
| 2 | H | DN | 9 | `QM1_AMIGA_H` | Horizontal / Down direction | LOW (0) |
| 3 | VQ | LF | 8 | `QM1_AMIGA_VQ` | Vertical Quadrature / Left direction | LOW (0) |
| 4 | HQ | RT | 7 | `QM1_AMIGA_HQ` | Horizontal Quadrature / Right direction | LOW (0) |
| 5 | b3 | b3 | 13 | `QM1_AMIGA_B3` | Button 3 | LOW (0) |
| 6 | b1 | b1 | 11 | `QM1_AMIGA_B1` | Button 1 (Fire) | LOW (0) |
| 7 | +5V | +5V | - | - | Power (not connected to GPIO) | N/A |
| 8 | GND | GND | - | - | Ground (not connected to GPIO) | N/A |
| 9 | b2 | b2 | 12 | `QM1_AMIGA_B2` | Button 2 | LOW (0) |

## Notes

### Direction Signals (Joystick Mode)
- **DB-9 Pin 1 (UP) - GPIO 10 (`QM1_AMIGA_V`)**: Vertical signal, used for up direction
- **DB-9 Pin 2 (DN) - GPIO 9 (`QM1_AMIGA_H`)**: Horizontal signal, used for down direction
- **DB-9 Pin 3 (LF) - GPIO 8 (`QM1_AMIGA_VQ`)**: Vertical quadrature signal, used for left direction
- **DB-9 Pin 4 (RT) - GPIO 7 (`QM1_AMIGA_HQ`)**: Horizontal quadrature signal, used for right direction

**Note:** In joystick mode, the direction signals use simple digital levels (active low).

### Quadrature Signals (Mouse Mode Only)
- **Horizontal Quadrature (HQ) - GPIO 7**: Used for mouse quadrature encoding, **not used in joystick mode**
- **Vertical Quadrature (VQ) - GPIO 8**: Used for mouse quadrature encoding, **not used in joystick mode**

### Button Signals
- All buttons are **active low** (LOW = pressed, HIGH = not pressed)
- **DB-9 Pin 5** (b3) = GPIO 13 (`QM1_AMIGA_B3`) = Button 3
- **DB-9 Pin 6** (b1) = GPIO 11 (`QM1_AMIGA_B1`) = Button 1 (Fire)
- **DB-9 Pin 9** (b2) = GPIO 12 (`QM1_AMIGA_B2`) = Button 2

## Important Notes

1. **Shared GPIO Pins**: Joystick Port 1 uses the same GPIO pins as the mouse interface (GPIO 7-13). They share the same physical connector on the Amiga.

2. **Active Low Signals**: All signals are active low:
   - Direction pins: LOW = direction active, HIGH = direction inactive or opposite direction
   - Button pins: LOW = button pressed, HIGH = button not pressed

3. **Joystick vs Mouse Mode**:
   - **Mouse mode**: Uses quadrature encoding (GPIO 7, 8, 9, 10 with quadrature sequences)
   - **Joystick mode**: Uses simple digital signals (GPIO 9, 10 for directions, GPIO 11-13 for buttons)
   - Quadrature signals (GPIO 7, 8) are kept inactive in joystick mode

4. **Direction Logic**:
   - For joystick mode, the H and V pins use simple digital levels:
     - H pin LOW = Left
     - H pin HIGH = Right (or no horizontal)
     - V pin LOW = Up
     - V pin HIGH = Down (or no vertical)

## Code Reference

- GPIO definitions: `src/config.h` (QM1_AMIGA_* macros)
- Joystick implementation: `src/platform/amiga/joystick_port1.c`
- Mouse implementation: `src/platform/amiga/quad_mouse.c`

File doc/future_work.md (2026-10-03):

# Future work & known limitations

**Last updated:** August 2026  
**Firmware:** v4.2.0 (`main`)  
**Purpose:** Open bugs, roadmap, and pointers to deeper archive notes — not a build checklist.

Public doc index: [`README.md`](./README.md). Architecture / agent quickstart: [`architecture.md`](./architecture.md). Historical task lists: [`archive/todo.md`](./archive/todo.md).

---

## Current status (v4.2.0)

Shipped and working on `main`:

| Area | Status |
|---|---|
| USB/BT → Amiga (Device Mode) | Complete |
| Amiga kbd/mouse → PC (Host Mode) | Complete (keyboard + Port 1 mouse + Port 2 Atari 2-btn gamepad) |
| Dual joystick ports + OLED UI | Complete |
| **CD32 seven-button on Port 1 + Port 2** | **Complete and working** |
| Llamatron twin-stick | Complete (works with Port 2 CD32) |
| Settings carousel / USB role toggle | Complete (v4.1.0) |
| Atari/Amiga mouse feel tuning | Complete (v4.0.5–4.0.11) |
| Host Mode Port 2 Atari stick → USB | Complete (v4.2.0; Mac + MiSTer validated) |

---

## Known issues

### Bluetooth gamepad slot routing on disconnect

Pads are assigned by **connection order** (`bt_gamepads[0]` → Port 2, `[1]` → Port 1). Powering off the first-paired pad can leave the survivor unrouted until re-pair. Prefer compacting slots on disconnect, or stable bind-by-address / “bind to port” UI (see UI roadmap).

This is a general dual-BT-pad routing issue — not a CD32 protocol bug.

### UART / serial log corruption

Observed causes / contributors:

1. **GPIO 1 (UART RX) wired while unused for host RX** — On Rev 6, GPIO **0/1** are reserved as `DEBUG_UART_TX` / `DEBUG_UART_RX`. If GPIO **1** is connected to something else (or tied into a shared net) while nothing is driving a clean UART RX line, serial output can corrupt or garble even though TX (GPIO 0) looks fine. Prefer leaving GPIO 1 **unconnected** unless a real debug UART host is attached; do not share it with Amiga I/O or other signals.
2. **Heavy IRQ / multi-context logging** — Under CD32 IRQ + Bluepad32 load, lines can also garble (`printf` / `logi` from multiple contexts). Release builds already gate most spam (`DEBUG_MESSAGES` / `CONTROLLER_DEBUG` off).

Longer-term software mitigations: serialize UART (ring buffer from main loop) and rate-limit Bluepad32 “Unsupported page” mouse logs (`0xff43`). When diagnosing garbled serial, first check whether GPIO 1 is connected without a proper UART peer.

### USB device mode (Amiga → PC) polish

Host Mode keyboard + Port 1 mouse + Port 2 Atari 2-button stick work as USB HID. Remaining polish:

- Mouse axis sign / button assignment if mirrored on some mice
- Mouse quadrature is polled from the main loop — IRQ/PIO if fast motion drops
- **Mega Drive pad input** — on hold (needs pin 5↔7 remapper); see [`host-mode-port2-joystick.md`](./host-mode-port2-joystick.md)
- **CD32 as USB HID gamepad to the PC** — not implemented
- Detail / diagnostics: [`archive/amiga-usb-device-mode.md`](./archive/amiga-usb-device-mode.md)

---

## Roadmap

### Bluetooth / Core 1

Much of the Atari v22.1.0 pairing work is already on Amiga (Core 1 loop-counter consume, pause/watchdog). Remaining polish:

- Flash-layout audit: `mouse_config` sector vs BTstack TLV (`PICO_FLASH_BANK_TOTAL_SIZE`)
- `bluepad32_platform.c` settle/ready delays toward Atari (`BT_GAMEPAD_*_MS`)
- Re-run KB + mouse + Stadia/Xbox pair matrix after any SDK / Bluepad32 bump
- Compact BT gamepad slots on disconnect (see known issue above)

See [`BT_PAIRING_BEST_PRACTICES.md`](./BT_PAIRING_BEST_PRACTICES.md) and [`archive/BT_PAIRING_HANDOFF.md`](./archive/BT_PAIRING_HANDOFF.md) / [`archive/stadia-controller-verification.md`](./archive/stadia-controller-verification.md).

### UI

| Item | Notes |
|---|---|
| Cycle gamepad bindings on Map Devices | Atari UI unification Phase 2; helps dual-pad reconnect routing |
| Portable OLED spec | Local: `local/ULTRAUSBT_OLED_UI_SPEC.md` (gitignored) |

### Hardware / firmware

| Item | Notes |
|---|---|
| Rev 6 shipping | Port 2 fire/B2/B3 on GPIO **16/17/18**; OLED buttons on ADC **26/27/28**; UART on 0/1 — [`gpio_rev6_adc_avoidance.md`](./gpio_rev6_adc_avoidance.md) |
| USB gamepad → Port 1 | First USB pad still drives Port 2 by default; Port 1 CD32 is typically a second BT pad (or dual-pad setup) |
| Host Mode Mega Drive / CD32 pad **input** | On hold / not started — [`host-mode-port2-joystick.md`](./host-mode-port2-joystick.md) |
| Submodule / SDK bump | Re-test BT + mouse after pico-sdk / bluepad32 updates ([`submodule-versions.md`](./submodule-versions.md)) |

---

## Resolved (reference)

| Item | Note |
|---|---|
| **CD32 Port 1 + Port 2 seven-button protocol** | Complete — OLED + shortcuts; ghost-button fix (CLOCK-fall shift) |
| OLED Settings carousel + Host/Device Mode | v4.1.0 |
| Host Mode Port 2 Atari stick → USB HID gamepad | v4.2.0 (dedicated HID IF1; Mac + MiSTer) |
| Atari/Amiga quadrature mouse feel | v4.0.5–4.0.11 |
| OLED Up/Down/# → Left/Right/Middle remap | v4.0.12 |
| USB device mode (Amiga kbd/mouse → PC) | v3.2.0+; Caps Lock macOS hold in v3.2.1 |
| Core 1 mouse dead after Stadia bond | Fixed v2.2.18 — do not gate consume on `absolute_time` |
| Map Devices UI + `build-all.sh` | v2.1.1 |
| Dual CD32 Port 1 + Port 2 wiring/protocol | v2.2.x onward |
| Release hygiene (UART quiet + LICENSE/NOTICE) | v4.0.0 |

---

## Documentation map

| Document | Role |
|---|---|
| [`README.md`](./README.md) (this folder) | Public doc index |
| [`../README.md`](../README.md) | Product overview, shortcuts, build |
| [`architecture.md`](./architecture.md) | Software architecture + developer/agent quickstart |
| [`BT_PAIRING_BEST_PRACTICES.md`](./BT_PAIRING_BEST_PRACTICES.md) | BT pairing practices |
| [`host-mode-port2-joystick.md`](./host-mode-port2-joystick.md) | Host Mode Port 2 Atari (done) + MD research |
| [`gpio_rev6_adc_avoidance.md`](./gpio_rev6_adc_avoidance.md) | Rev 6 pin rationale |
| [`submodule-versions.md`](./submodule-versions.md) | Pinned SDK / Bluepad32 / TinyUSB |
| [`archive/`](./archive/) | Build specs, troubleshooting, upstream borb notes, WIP |

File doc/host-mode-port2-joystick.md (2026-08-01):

# Host Mode Port 2 controllers → USB (PC / MiSTer)

**Status:** Phase 1 (Atari 2-button) **shipped in v4.2.0** — validated on Mac and MiSTer  
**Date:** August 2026  
**Goal:** While the adapter is in **Host Mode** (Amiga/Atari I/O → USB), read DB-9 controllers on **Port 2** and present them as a standard USB HID gamepad for PC and [MiSTer FPGA](https://github.com/MiSTer-devel/Wiki_MiSTer/wiki/Input-devices).

**Scope:**

1. **Atari-style digital joysticks** — **done** (dirs + fire + button 2)
2. **Sega Mega Drive / Genesis** — **on hold** (needs physical remapper; research in §3.2)

Related: [`future_work.md`](./future_work.md), [`architecture.md`](./architecture.md), [`archive/amiga-usb-device-mode.md`](./archive/amiga-usb-device-mode.md).

---

## 1) What “Host Mode” means

UI name **Host Mode** = firmware `USB_MODE_DEVICE` (adapter is a USB **device** to the PC).

| Implemented | Deferred |
|---|---|
| Amiga keyboard → USB HID keyboard | Mega Drive 3-/6-btn (remapper + Select protocol) |
| Port 1 quadrature mouse → USB HID mouse | Port 1 as digital joystick → USB |
| **Port 2 Atari 2-btn stick → USB HID gamepad** | CD32 pad **read** |
| HID IF0: report IDs 1=kbd, 2=mouse; **HID IF1: gamepad** | |

Entry points:

- `src/main.c` — device-mode branch: `keyboard_host_in_*`, `mouse_host_in_*`, `joystick_port2_host_in_*`, `usb_hid_device_task()`
- `src/usb_hid_device.c` — TinyUSB descriptors + report drain (kbd + mouse + gamepad)
- `src/platform/amiga/joystick_port2_host_in.c` — Atari Port 2 input (Host Mode)

---

## 2) Target user scenarios

1. **PC / Mac / Linux** — Competition Pro / Atari CX40 / similar into Port 2; OS sees a HID gamepad.
2. **MiSTer FPGA** — same USB HID gamepad; assign as P1/P2 in the Menu core OSD.
3. MiSTer accepts any standard USB HID gamepad; no XInput required.

**macOS note:** System Settings → Game Controllers usually ignores generic HID pads. Use [hardwaretester.com/gamepad](https://hardwaretester.com/gamepad) or `ioreg -p IOUSB -w0 | grep -i Amiga`. After firmware mapping changes, **re-define** the joystick in MiSTer’s Menu.

---

## 3) Port 2 electrical / pin maps

### 3.1 Amiga / Atari digital joystick (native Port 2 pinout)

| DB-9 pin | Signal | Active | Typical stick |
|---|---|---|---|
| 1 | Up | Low to GND | Yes |
| 2 | Down | Low to GND | Yes |
| 3 | Left | Low to GND | Yes |
| 4 | Right | Low to GND | Yes |
| 5 | Button 3 / PotX / CD32 Latch | Low (Amiga 3-btn) | Often unused on 1-btn Atari sticks |
| 6 | Fire 1 | Low to GND | Yes |
| 7 | +5V | Supply | Stick usually passive switches |
| 8 | GND | Common | Yes |
| 9 | Fire 2 / PotY / CD32 Data | Low (Amiga 2-btn) | Some 2-btn sticks |

Firmware Port 2 map (`config.h`):

| Signal | Rev 5 GPIO | Rev 6 GPIO | Define |
|---|---|---|---|
| Up | 19 | 19 | `QM2_AMIGA_V` |
| Down | 20 | 20 | `QM2_AMIGA_H` |
| Left | 21 | 21 | `QM2_AMIGA_VQ` |
| Right | 22 | 22 | `QM2_AMIGA_HQ` |
| Fire | 26 | 16 | `QM2_AMIGA_B1` |
| Button 2 | 27 | 17 | `QM2_AMIGA_B2` |
| Button 3 | 28 | 18 | `QM2_AMIGA_B3` |

### How reading works (classic digital stick)

1. Configure direction/button lines as **GPIO_IN** with **pull-up**.
2. Pressed = `gpio_get(pin) == 0` (active low).
3. Poll in the Host Mode main loop (~8 ms).
4. Straight DB-9 cable into Port 2 — no remapper for Atari/Amiga sticks.

### 3.2 Sega Mega Drive / Genesis (ON HOLD)

**Deferred.** MD pads need a **physical pin 5↔7 remapper** because board pin 7 is hardwired +5V while MD Select must be host-driven. Full protocol notes remain below for a later phase.

<details>
<summary>MD research notes (deferred)</summary>

#### Why a straight cable will not work

Mega Drive DE-9 pinout **differs** from Amiga Port 2 on the critical control pins ([iComp DE-9 table](https://wiki.icomp.de/wiki/DB9-Joystick), Sega docs):

| DB-9 pin | Amiga Port 2 (this board) | Mega Drive pad |
|---|---|---|
| 1–4 | Up / Down / Left / Right | Up / Down / Left / Right (same idea) |
| 5 | Button 3 / PotX | **+5V** |
| 6 | Fire | **TL** (A when Sel low, B when Sel high) |
| 7 | **+5V (fixed)** | **TH / Select (host must drive)** |
| 8 | GND | GND |
| 9 | Button 2 | **TR** (Start when Sel low, C when Sel high) |

#### Required Host Mode MD adapter cable

| MD pad pin | MD signal | Wire to Amiga Port 2 pin | Board GPIO / rail | Host Mode role |
|---|---|---|---|---|
| 1–4 | dirs | 1–4 | Port 2 dir GPIOs | Input |
| 5 | +5V | **7** | +5V rail | Power to pad |
| 6 | TL (A/B) | 6 | `QM2_AMIGA_B1` | Input |
| 7 | Select | **5** | `QM2_AMIGA_B3` | **Output (Select)** |
| 8 | GND | 8 | GND | Ground |
| 9 | TR (Start/C) | 9 | `QM2_AMIGA_B2` | Input |

3-button / 6-button protocols: Select HIGH/LOW samples; 6-btn needs extra fast pulses for X/Y/Z/Mode. References in §10.

</details>

---

## 4) USB HID presentation (as shipped)

### Two HID interfaces (required for macOS / Chrome)

A single composite report-ID device (kbd+mouse+gamepad on one interface) enumerates on Mac, but the **Gamepad API ignores** the gamepad collection when Keyboard is the primary usage. Shipped layout:

```text
HID interface 0 — Keyboard (report ID 1) + Mouse (report ID 2)
HID interface 1 — Gamepad only (no report ID)   ← Port 2 stick
```

`CFG_TUD_HID = 2` in `tusb_config.h`. Product string: **Amiga HID Bridge** (VID `0x2E8A`, PID `0xAB1A`).

TinyUSB gamepad layout: 6× int8 axes, 1× hat, 32 button bits via `tud_hid_n_gamepad_report(1, ...)`.

### Mapping — Atari (Phase 1, frozen)

| Physical | HID field |
|---|---|
| Up / Down / Left / Right | Axis X/Y (±127) + `hat` |
| Fire (pin 6) | Button bit 0 (`GAMEPAD_BUTTON_A` / B0) |
| Button 2 (pin 9) | Button bit 1 (`GAMEPAD_BUTTON_B`) |
| Button 3 (pin 5) | unused (2-btn profile) |
| Unused axes | 0 (centered) |

**Do not** mirror dirs onto buttons 12–15: bit 12 is **Mode**, which MiSTer often uses as OSD/menu — holding a direction then looks like Menu+D-pad (autofire period / OSD).

On MiSTer / many UIs, B0 is labelled **Button 1** (1-based).

### Mapping suggestion — Mega Drive (when resumed)

| MD button | HID suggestion | TinyUSB bit (typical) |
|---|---|---|
| A | South / A | `GAMEPAD_BUTTON_A` |
| B | East / B | `GAMEPAD_BUTTON_B` |
| C | West / X *or* R1 | Freeze one layout and document; MiSTer remaps |
| Start | Start | `GAMEPAD_BUTTON_START` |
| X | North / Y | `GAMEPAD_BUTTON_Y` |
| Y | L1 | `GAMEPAD_BUTTON_TL` |
| Z | R1 | `GAMEPAD_BUTTON_TR` |
| Mode | Select | `GAMEPAD_BUTTON_SELECT` |
| D-pad | Hat (+ X/Y) | `hat` / axes |

### Poll interval

HID endpoint interval 10 ms; Port 2 poll ~8 ms. Periodic reports (not change-only) keep browsers listing the pad.

---

## 5) Software architecture (implemented)

```text
Host Mode main loop
  tud_task()
  usb_hid_device_task()
  keyboard_host_in_task()
  mouse_host_in_task()
  joystick_port2_host_in_task()
        |
        | Atari: inputs + pull-ups; build x/y + hat + buttons
        v
  usb_hid_device_send_gamepad(x, y, hat, buttons)
        |
        v
  usb_hid_device.c  IF1 → tud_hid_n_gamepad_report(...)
```

| Piece | Role |
|---|---|
| `joystick_port2_host_in.c/.h` | Atari digital read (**done**) |
| `megadrive_port2_host_in` *(future)* | Select protocol; 3-/6-btn decode |
| `usb_hid_device.c/.h` | IF0 kbd/mouse + IF1 gamepad (**done**) |
| `main.c` | Host Mode init + task (**done**) |

Do **not** reuse `joystick_port2.c` / `cd32_pad.c` Amiga **output** drivers in Host Mode.

### Conflict rules in Host Mode

- Atari mode: Port 2 direction/button GPIOs stay **inputs**.
- MD mode (future): `QM2_AMIGA_B3` becomes **Select output** via remapper; never treat board pin 7 as Select.
- Do not run Amiga-facing Port 2 / CD32 output drivers.
- Port 1 remains mouse-in unless a later dual-pad feature is added.

---

## 6) Phased delivery

### Phase 1 — Atari 2-button — **DONE** (v4.2.0)

- `joystick_port2_host_in.c` reads dirs + fire + button 2
- USB HID gamepad on **its own interface** (IF1); kbd/mouse on IF0
- Straight DB-9 cable; validated on Mac (browser Gamepad API) and MiSTer (Minimig)

### Phase 1b / 2 — Mega Drive — **ON HOLD**

- Physical pin 5↔7 remapper + Select protocol (3-btn then 6-btn)

### Phase 3 — Optional CD32 pad **input**

- Different protocol (Latch/Clock/Data as Amiga). Separate from MD Select.

### Phase 4 — Optional Port 1 Host Mode joystick / second pad

- Second gamepad HID interface for two DB-9 devices.

---

## 7) MiSTer-specific notes

From MiSTer’s [Input devices](https://github.com/MiSTer-devel/Wiki_MiSTer/wiki/Input-devices) wiki:

- Any USB HID device is recognized.
- Press a button after a core starts to assign P1, then P2, etc.
- Define the controller once in the **Main** menu joystick mapping.
- Plain HID Gamepad is fine (no XInput required).
- After firmware changes that alter button bits, **re-define all joysticks**.

**Atari stick test:** Menu → map axes/hat + Button 1 (fire) → arcade/Amiga core.

**MD pad test (future):** Menu → map D-pad + A/B/C/Start (+ X/Y/Z/Mode for 6-btn) → Genesis core.

---

## 8) Lessons learned / risks for MD

| Item | Note |
|---|---|
| Composite kbd+mouse+gamepad on one IF | macOS/Chrome Gamepad API blind — use separate IF |
| Buttons 12–15 as “d-pad” | Bit 12 = Mode → MiSTer OSD/autofire clash |
| Rev 5 level shifter vs Select output | Bench-test; Rev 6 preferred for MD |
| Straight MD cable | Will not work; needs remapper |
| `CFG_TUD_HID_EP_BUFSIZE` | Must fit gamepad report (+ report ID on IF0) |

Open for MD phase: remapper + Select-on-B3 with real 3-/6-btn pads; OLED Atari/MD profile; frozen MD button map.

---

## 9) Implementation checklist (Atari — done)

1. ~~Hardware smoke test: Atari stick on Port 2 as inputs~~
2. ~~Raise `CFG_TUD_HID_EP_BUFSIZE` if needed~~
3. ~~Separate HID IF for gamepad~~
4. ~~`joystick_port2_host_in` → gamepad report~~
5. ~~Validate Mac + MiSTer; document Mode/button pitfalls~~

Remaining: MD remapper + Select protocol when resumed.

---

## 10) References

- Existing Host Mode: `src/usb_hid_device.c`, `mouse_host_in.c`, `keyboard_host_in.c`, `joystick_port2_host_in.c`
- Port 2 Amiga output (do not reuse as Host Mode driver): `joystick_port2.c`
- TinyUSB: `TUD_HID_REPORT_DESC_GAMEPAD` / `tud_hid_n_gamepad_report`
- Architecture: [`architecture.md`](./architecture.md) § device-mode diagram
- MD protocol: [msarnoff gen2usb](http://www.msarnoff.org/gen2usb/), [Interface Protocol of SEGA MegaDrive 6-Button Controller](https://applause.elfmimi.jp/md6bpad-e.html), [AllPinouts SMS/MD](https://allpinouts.org/pinouts/connectors/videogame/segamaster-system-sms-and-megadrive-joystick/)

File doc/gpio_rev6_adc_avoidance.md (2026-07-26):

# GPIO Rev 6 — Avoid ADC Pins (Direct 5V / No Level Shifters)

# Board revision (pin map in `src/config.h`)

| Revision | Hardware | Port 2 fire/B2/B3 | OLED buttons L/M/R | Level shifters |
|---|---|---|---|---|
| **5** (default build) | Current shipping PCB | GPIO **26 / 27 / 28** | GPIO **18 / 17 / 16** | Yes (`ENABLE_LEVEL_SHIFTER=1`) |
| **6** | Pico 2 direct-5V PCB | GPIO **16 / 17 / 18** | GPIO **26 / 27 / 28** (ADC) | No (`ENABLE_LEVEL_SHIFTER=0`) |

Firmware support for both maps is complete. Build Rev 6 with:

```cmake
add_compile_definitions(HIDPICO_REVISION=6)
```

Rev 6 swaps the Port 2 joystick lines onto the freed 5V-tolerant header GPIOs (16–18) and moves the OLED UI buttons onto the ADC pins (26–28), which only ever see 3.3V tactile switches. **GPIO 0/1 are reserved for the debug UART** (`DEBUG_UART_TX`/`DEBUG_UART_RX`) and carry no Amiga lines.

Do **not** flash Rev 6 firmware onto a Rev 5 board (wrong pins). Full PCB notes below.

**Branch:** developed on `feature/gpio-no-ttl-keyboard-in` (adopting the `feature/gpio-avoid-adc` Rev 6 layout); maps live in `config.h` for all builds.

## Problem (Rev 5)

On RP2350, only **GPIO 0–25** are 5V-tolerant. Rev 5 used **GPIO 26–28** (ADC0–ADC2) for Port 2 fire and buttons 2/3. Those pins are **not** safe for direct Amiga 5V without level shifters.

| DB-9 pin | Signal | Rev 5 GPIO | ADC? | RP2350 5V OK? |
|---|---|---|---|---|
| 6 | Fire | **26** | ADC0 | No |
| 9 | Button 2 | **27** | ADC1 | No |
| 5 | Button 3 | **28** | ADC2 | No |

CD32 mode on Port 2 uses the same three lines (JOYMODE / CLOCK / DATA).

## Locked Rev 6 mapping

All Port 2 button/fire lines move to **5V-tolerant** header GPIOs (16–18, freed by relocating the OLED buttons). Directions (19–22) and Port 1 (unchanged) were already safe. The OLED UI buttons move onto the ADC pins (26–28) — they only ever carry 3.3V tactile switches, never Amiga 5V.

| DB-9 pin | Signal | Rev 5 GPIO | **Rev 6 GPIO** | Firmware define |
|---|---|---|---|---|
| 6 | Fire | 26 | **16** | `QM2_AMIGA_B1` / `JOY0_ATARI_FIRE` |
| 9 | Button 2 | 27 | **17** | `QM2_AMIGA_B2` (CD32 DATA) |
| 5 | Button 3 | 28 | **18** | `QM2_AMIGA_B3` (CD32 JOYMODE) |

Port 1 buttons remain on GPIO **2** and **3** (already non-ADC).

### OLED UI buttons (moved to ADC pins)

| Button | Rev 5 GPIO | **Rev 6 GPIO** | Firmware define |
|---|---|---|---|
| Left | 18 | **26** | `GPIO_BUTTON_LEFT` (Up) |
| Middle | 16 | **28** | `GPIO_BUTTON_MIDDLE` (#) |
| Right | 17 | **27** | `GPIO_BUTTON_RIGHT` (Down) |

ADC pins are fine here: they are inputs with pull-ups tied to 3.3V tactile switches, never exposed to Amiga 5V.

### Debug UART

GPIO **0** (`DEBUG_UART_TX`) and **1** (`DEBUG_UART_RX`) are reserved for the stdio debug UART on Rev 6 and carry no Amiga signals.

### CD32 (Port 2)

| CD32 role | DB-9 pin | Rev 6 GPIO |
|---|---|---|
| JOYMODE | 5 | **18** (`QM2_AMIGA_B3`) |
| CLOCK | 6 | **16** (`QM2_AMIGA_B1`) |
| DATA | 9 | **17** (`QM2_AMIGA_B2`) |

Directions stay on GPIO 19–22 (unchanged).

## Software defaults

| Setting | Rev 5 | Rev 6 |
|---|---|---|
| `HIDPICO_REVISION` | **5** (CMakeLists default) | **6** (`-DHIDPICO_REVISION=6`) |
| `ENABLE_LEVEL_SHIFTER` | 1 (default) | **0** (default) |
| `HIDPICO_REV_ATARI_BOARD` | defined | defined |

Build Rev 6 firmware (new PCB only):

```bash
# In CMakeLists.txt:
add_compile_definitions(HIDPICO_REVISION=6)
```

Or keep Rev 5 as the default and pass an override if your build scripts support it.

## Free GPIO after Rev 6

| GPIO | Status |
|---|---|
| 7 | Free |
| 15 | Free |
| 24 | Free |
| 26–28 | OLED UI buttons (ADC, 3.3V tactile switches) — **do not use for 5V Amiga lines** |
| 29 | ADC3 — avoid for 5V |

## PCB requirements

1. Reroute **Port 2 DB-9 pin 6** (fire) from Pico GP26 → **GP16**
2. Reroute **Port 2 DB-9 pin 9** (B2) from Pico GP27 → **GP17**
3. Reroute **Port 2 DB-9 pin 5** (B3) from Pico GP28 → **GP18**
4. Move the **OLED UI buttons** from GP16/17/18 → **GP26/27/28** (ADC pins; 3.3V tactile switches only)
5. Keep **GP0/GP1** for the debug UART (no Amiga lines)
6. Remove TXB0108 (or equivalent) level shifters on the Port 2 fire/button lines if present
7. **IOVDD must be powered** whenever Amiga 5V is on the joyport (RP2350 requirement)

Rev 5 boards **must not** flash Rev 6 firmware without the PCB changes — fire/buttons will drive the wrong pins.

## RP2040 (original Pico / Pico W)

RP2040 has **no** 5V-tolerant GPIOs. Rev 6 direct-wiring target is **Pico 2 / Pico 2 W** only. RP2040 builds should stay on Rev 5 with level shifters.

## References

- `src/config.h` — `HIDPICO_REVISION == 6` block
- `doc/archive/amiga-code-atari-board-gpio-mappings.md` — Rev 5 baseline
- `doc/archive/CD32_BUILD_SPEC.md` — CD32 pin roles (archived build spec)
- `doc/archive/gpio_allocation_plan.md` — Option 2 (GPIO 0/1 for Port 2 B2/B3)
- Raspberry Pi RP2350 A4: GPIO 0–25 5V-tolerant; 26–29 ADC only

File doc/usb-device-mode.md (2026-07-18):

# USB Device Mode — use an Amiga keyboard/mouse on a PC

This mode reverses the adapter: instead of reading USB/Bluetooth devices and driving
the Amiga, it **reads a real Amiga keyboard (and Port 1 mouse) and presents the adapter
to a host PC as a USB HID keyboard + mouse**. It lets you use an Amiga 2000 (or other
Amiga) keyboard on a modern computer.

It is modelled on the "ADB host mode" feature of the sibling
`ultramegausb-apple-adb` firmware.

## Modes

| Mode | USB role | Data flow | Use |
|---|---|---|-----|
| **Host** (default) | USB host | USB/BT devices → Amiga | Normal adapter operation |
| **Device** (this feature) | USB device | Amiga keyboard/mouse → PC | Use an Amiga keyboard on a PC |

The RP2040/RP2350 has a single USB PHY, so only one role is active at a time. The mode
is stored in flash and selected at boot.

## Switching modes

Hold the **Middle + Right OLED buttons together for 2 seconds**. The screen shows the
mode you are about to switch to (`PC KBD` or `AMIGA`); after the hold, the setting is
saved to flash and the adapter **reboots into the new mode**.

> A reboot is used (rather than live USB re-init) so the host PC always gets a clean
> USB enumeration and neither I/O subsystem is left half-initialised. The UX is still a
> single OLED gesture. Live re-init could be added later if desired.

## Wiring (reading the keyboard)

Device mode reuses the existing keyboard GPIOs, but as **inputs**:

| Signal | GPIO | Direction in device mode |
|---|---|---|
| `KBD_AMIGA_CLK` | 6 | Input (keyboard is the clock master); IRQ on falling edge |
| `KBD_AMIGA_DAT` | 5 | Input; briefly driven low (~85 µs) as the handshake ACK |

The Port 1 mouse (quadrature + buttons) is read on the usual Port 1 GPIOs
(`QM1_AMIGA_H/HQ/V/VQ` and fire/B2/B3).

> **Electrical note:** `KDAT` must be **bidirectional** — the keyboard drives it while
> transmitting data, and the adapter must drive it low for the handshake/ACK. `KCLK` is
> read-only (keyboard is always the clock master). On the ultramegausb Atari board
> (Rev 5) both directions work as wired; the RP2350 is 5V-tolerant on these pins. If a
> board used a fixed-direction (output-only toward the Amiga) buffer on `KDAT`, the
> handshake could not reach the keyboard and it would sit in its resync loop forever
> (see below).

## Protocol (receive side)

The Amiga keyboard is the clock master. For each bit it places the (active-low,
inverted) data on `KDAT`, then pulses `KCLK` low. The firmware:

1. Samples `KDAT` on each `KCLK` **falling** edge, MSB first, 8 bits per frame
   (a `1` bit = `KDAT` driven low).
2. Un-rotates the byte: the keyboard sends `rotate_left(keycode | (up << 7))`, so
   `keycode | (up<<7) = rotate_right(raw)`. Keycodes `0x00–0x67` are real keys; higher
   values are telemetry (init/term power, lost sync, reset warning) and are ignored.
3. Translates the Amiga keycode to a USB HID usage using a reverse map built by
   inverting the existing `mapHidToAmiga[]` table; the modifier block (`0x60–0x67`) is
   mapped to HID modifier bits; caps lock is emitted as a press/release pulse to keep
   the host's locking state aligned.
4. Assembles a 6-key rollover + modifier report and hands it to the USB device layer.

### Handshake and resync (critical)

After **every** frame the keyboard waits (up to ~143 ms) for the computer to pull
`KDAT` low for ≥85 µs as an acknowledge. If it does not get that ACK it decides it is
"out of sync" and enters a **resync loop**: it clocks out a **single bit**, waits again
for the handshake, and repeats. On the wire this looks like a steady **~7 `KCLK`
edges/second** (1000 ms ÷ 143 ms ≈ 7) that never stops — and no key ever registers.

The firmware handles this on two paths:

- **Per-frame ACK (ISR):** the moment the 8th bit of a frame arrives, the KCLK ISR
  immediately drives the `KDAT` handshake. Doing it in the ISR (not the main loop)
  keeps it well inside the keyboard's timeout even while USB / OLED work is running.
- **Resync recovery (task):** during resync only a *single* bit is clocked, so a full
  frame never assembles and the per-frame ACK never fires. `keyboard_host_in_task()`
  detects a partial frame that has stalled mid-byte (bits clocked, then quiet for
  >3 ms — the resync signature) and issues the handshake anyway. This walks the
  keyboard back into sync; it then emits `0xF9` ("last keycode bad / lost sync") and
  resumes normal transmission. Healthy frames clock all 8 bits in well under 3 ms, so
  this path never triggers during normal typing.

Without the resync recovery a keyboard that ever slips out of sync (e.g. missed the
very first power-up ACK) can never be recovered, even though reads look fine.

## Implementation

| File | Role |
|---|---|
| `src/usb_mode.c` / `.h` | HOST/DEVICE selection, flash persistence, reboot-to-switch, `tusb_init` role |
| `src/usb_hid_device.c` / `.h` | TinyUSB *device* stack: composite keyboard+mouse HID descriptor, `tud_*` callbacks, report drainer |
| `src/platform/amiga/keyboard_host_in.c` / `.h` | KCLK IRQ capture, decode, ISR handshake + resync recovery, reverse keycode map |
| `src/platform/amiga/mouse_host_in.c` / `.h` | Port 1 quadrature + button read → relative USB mouse reports |
| `src/tusb_config.h` | Enables `CFG_TUD_*` alongside `CFG_TUH_*` |
| `src/config.h` | `ENABLE_USB_DEVICE_MODE`, `USB_DEVICE_VID/PID`, `KEYBOARD_IN_DEBUG` |

The mode is persisted in the existing `port_config` flash sector
(`usb_device_mode` byte).

## Build flags

| Macro | Default | Meaning |
|---|---|---|
| `ENABLE_USB_DEVICE_MODE` | 1 | Compile the device-mode feature in. Set 0 to build host-only. |
| `USB_DEVICE_VID` / `USB_DEVICE_PID` | `0x2E8A` / `0xAB1A` | HID identity presented to the PC |
| `KEYBOARD_IN_DEBUG` | 0 | Log received frames, decoded keycodes, a 1 Hz KCLK edge/line heartbeat, named telemetry codes, and resync handshakes on UART. Useful for diagnosing handshake/wiring issues. |

### Diagnosing with `KEYBOARD_IN_DEBUG`

Default is **off (`0`)** in `src/config.h`. Set it to `1`, rebuild, and watch UART
(115200) when debugging device-mode keyboard receive. With the flag on, the
once-per-second heartbeat is the fastest way to read the state of the link:

```
[kbd-in] KCLK edges=136 (+7/s) CLK=1 DAT=1
```

- **`+0/s` at idle** — healthy; the keyboard is silent when no key is pressed.
- **steady `+7/s` at idle** — the keyboard is stuck in resync (not being ACKed). If you
  *also* see `resync handshake` lines the firmware is driving the ACK but the keyboard
  can't see it → suspect the `KDAT` drive path (wiring / fixed-direction buffer).
- **edges climb only while typing**, with `raw=`/`amiga=` values that match the keys →
  working normally.

Also logged when enabled: per-frame `raw=` / `amiga=` decode, named telemetry codes
(`0xFD` initiate / `0xFE` terminate power-up, etc.), and periodic resync-handshake
notices.

## Status / testing notes

- **Verified working on real hardware** (Amiga 2000 keyboard → ultramegausb Rev 5 board
  → macOS host). The resync recovery above was the fix that made typing reliable.
- If mouse axes are mirrored, flip the sign in `mouse_host_in_task()`.
- Mouse quadrature is currently polled from the main loop; if fast motion is dropped,
  move the decode to a GPIO IRQ or PIO state machine.
- Joystick-to-PC (gamepad HID) is not implemented; it would add a third
  `TUD_HID_REPORT_DESC_GAMEPAD` interface + `tud_hid_gamepad_report()`.

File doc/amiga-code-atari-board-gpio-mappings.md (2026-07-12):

# Amiga Code GPIO Mappings for Atari Board (Revision 5 / 6)

This document details GPIO pin mappings for the Amiga firmware on Atari-board hardware.

- **Revision 5** (`HIDPICO_REVISION=5`): level shifters; Port 2 fire/B2/B3 on GPIO 26/27/28 (ADC).
- **Revision 6** (`HIDPICO_REVISION=6`): direct 5V on Pico 2; Port 2 fire/B2/B3 on GPIO **16/17/18**, OLED UI buttons on ADC **26/27/28**, GPIO **0/1** reserved for debug UART. See [`gpio_rev6_adc_avoidance.md`](./gpio_rev6_adc_avoidance.md).

**IMPORTANT:** All pin designations are GPIO PIN NUMBERS, NOT PHYSICAL PIN NUMBERS.

## GPIO Usage Summary

### Keyboard Interface (GPIO 4-6)
All keyboard GPIOs are configured as **OUTPUT** (active low).

| GPIO | Function | Signal Name | Direction | Notes |
|---|---|---|---|---|
| 4 | Keyboard Reset | `KBD_AMIGA_RST` | OUTPUT | Active low |
| 5 | Keyboard Data | `KBD_AMIGA_DAT` | OUTPUT | Active low, serial data |
| 6 | Keyboard Clock | `KBD_AMIGA_CLK` | OUTPUT | Active low, serial clock |

**Status:** ✅ No conflicts

---

### I2C Display Interface (GPIO 8-9)
I2C pins use special function mode (not standard GPIO_IN/GPIO_OUT).

| GPIO | Function | Signal Name | Direction | Notes |
|---|---|---|---|---|
| 8 | I2C SDA | `I2C_PIN_SDA` / `SSD1306_SDA` | I2C Function | Pull-up enabled |
| 9 | I2C SCL | `I2C_PIN_SCL` / `SSD1306_SCL` | I2C Function | Pull-up enabled |

**Status:** ✅ No conflicts (shared I2C bus for display)

---

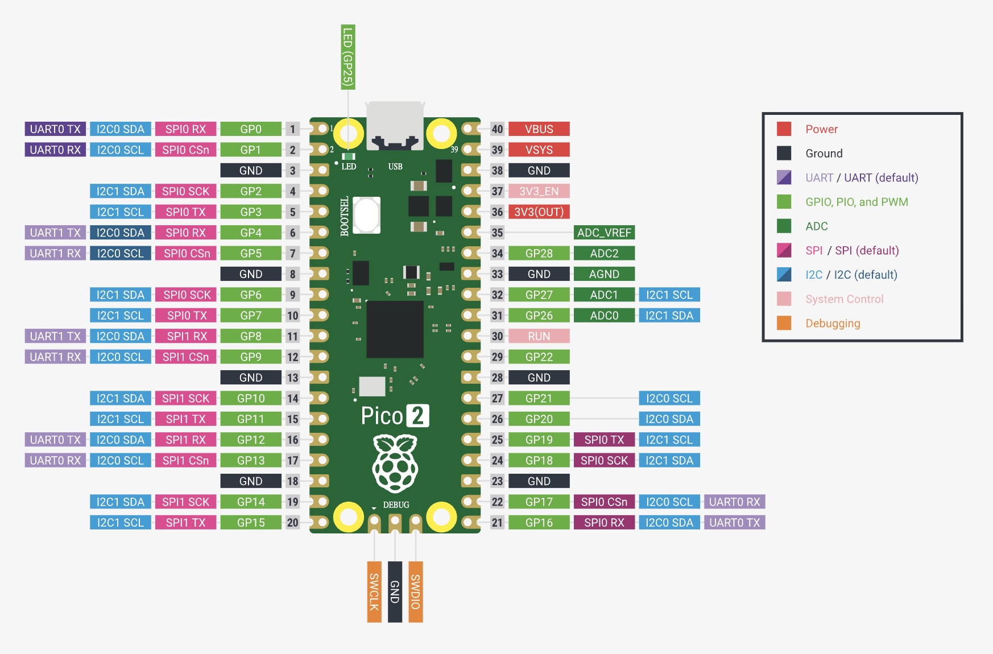
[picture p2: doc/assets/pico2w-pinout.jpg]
pico2w-pinout


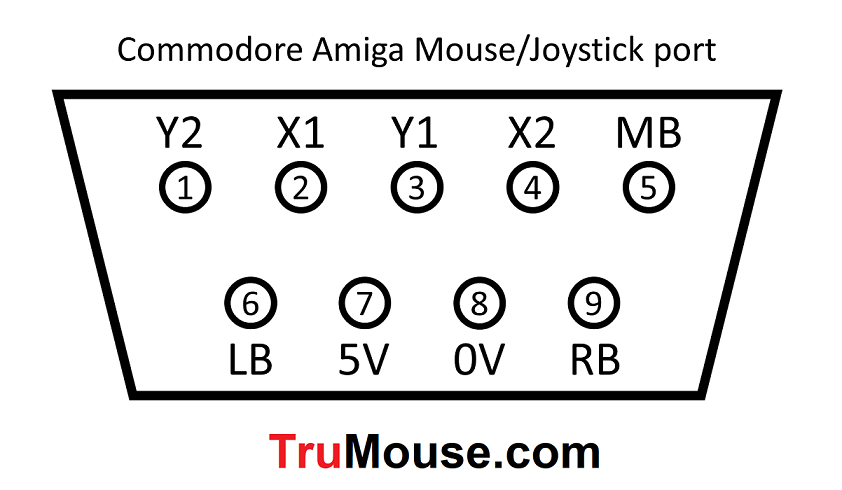
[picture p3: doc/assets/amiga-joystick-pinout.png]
amiga-joystick-pinout
### Joystick Port 1 / Mouse Interface (GPIO 10-14, 2-3)

Port 1 shares GPIOs with the mouse interface. All signals are **OUTPUT** (active low).

| GPIO | DB-9 Pin | Cable Color | Function | Signal Name | Direction | Notes |
|---|---|---|---|---|---|---|
| 10 | 1 | Blue | Port 1 UP / Mouse V | `QM1_AMIGA_V` | OUTPUT | Active low |
| 11 | 2 | Yellow | Port 1 DOWN / Mouse H | `QM1_AMIGA_H` | OUTPUT | Active low |
| 12 | 3 | Red | Port 1 LEFT / Mouse VQ | `QM1_AMIGA_VQ` | OUTPUT | Active low |
| 13 | 4 | Orange | Port 1 RIGHT / Mouse HQ | `QM1_AMIGA_HQ` | OUTPUT | Active low |
| 3 | 5 | Purple | Port 1 Button 3 | `QM1_AMIGA_B3` | OUTPUT | Active low, remapped from GPIO 13 |
| 14 | 6 | Green | Port 1 FIRE / Mouse B1 | `QM1_AMIGA_B1` | OUTPUT | Active low |
| - | 7 | - | +5V | - | - | Power supply |
| - | 8 | White | GND | - | - | Ground |
| 2 | 9 | Grey | Port 1 Button 2 | `QM1_AMIGA_B2` | OUTPUT | Active low, remapped from GPIO 12 |

**Status:** ✅ No conflicts (buttons remapped to GPIO 2 and 3)

---

### Display UI Buttons (GPIO 16-18)
All display buttons are configured as **INPUT** with pull-up resistors.

| GPIO | Function | Signal Name | Direction | Notes |
|---|---|---|---|---|
| 16 | Right Button | `GPIO_BUTTON_RIGHT` | INPUT | Pull-up, active low |
| 17 | Middle Button | `GPIO_BUTTON_MIDDLE` | INPUT | Pull-up, active low |
| 18 | Left Button | `GPIO_BUTTON_LEFT` | INPUT | Pull-up, active low |

**Status:** ✅ No conflicts

---

### Joystick Port 2 (GPIO 19-22, 26-28)
All Port 2 signals are configured as **OUTPUT** (active low).

| GPIO | DB-9 Pin | Cable Color | Function | Signal Name | Direction | Notes |
|---|---|---|---|---|---|---|
| 19 | 1 | Blue | Port 2 UP | `QM2_AMIGA_V` | OUTPUT | Active low |
| 20 | 2 | Yellow | Port 2 DOWN | `QM2_AMIGA_H` | OUTPUT | Active low |
| 21 | 3 | Red | Port 2 LEFT | `QM2_AMIGA_VQ` | OUTPUT | Active low |
| 22 | 4 | Orange | Port 2 RIGHT | `QM2_AMIGA_HQ` | OUTPUT | Active low |
| 28 | 5 | Purple | Port 2 Button 3 | `QM2_AMIGA_B3` | OUTPUT | Active low, remapped from GPIO 18 |
| 26 | 6 | Green | Port 2 FIRE | `QM2_AMIGA_B1` | OUTPUT | Active low |
| - | 7 | - | +5V | - | - | Power supply |
| - | 8 | White | GND | - | - | Ground |
| 27 | 9 | Grey | Port 2 Button 2 | `QM2_AMIGA_B2` | OUTPUT | Active low, GPIO 27 (ADC1) |

**Status:** ✅ No conflicts (buttons remapped to GPIO 27 and 28)

---

## Complete GPIO Usage Matrix

| GPIO | DB-9 Pin | Cable Color | Function | Signal Name | Direction | Status |
|---|---|---|---|---|---|---|
| 0 | - | - | Unused | - | - | ✅ Free |
| 1 | - | - | Unused | - | - | ✅ Free |
| 2 | P1:9 | Grey | Port 1 Button 2 | `QM1_AMIGA_B2` | OUTPUT | ✅ OK |
| 3 | P1:5 | Purple | Port 1 Button 3 | `QM1_AMIGA_B3` | OUTPUT | ✅ OK |
| 4 | - | - | Keyboard RST | `KBD_AMIGA_RST` | OUTPUT | ✅ OK |
| 5 | - | - | Keyboard DAT | `KBD_AMIGA_DAT` | OUTPUT | ✅ OK |
| 6 | - | - | Keyboard CLK | `KBD_AMIGA_CLK` | OUTPUT | ✅ OK |
| 7 | - | - | Unused | - | - | ✅ Free |
| 8 | - | - | I2C SDA | `I2C_PIN_SDA` / `SSD1306_SDA` | I2C Function | ✅ OK |
| 9 | - | - | I2C SCL | `I2C_PIN_SCL` / `SSD1306_SCL` | I2C Function | ✅ OK |
| 10 | P1:1 | Blue | Port 1 UP | `QM1_AMIGA_V` | OUTPUT | ✅ OK |
| 11 | P1:2 | Yellow | Port 1 DOWN | `QM1_AMIGA_H` | OUTPUT | ✅ OK |
| 12 | P1:3 | Red | Port 1 LEFT | `QM1_AMIGA_VQ` | OUTPUT | ✅ OK |
| 13 | P1:4 | Orange | Port 1 RIGHT | `QM1_AMIGA_HQ` | OUTPUT | ✅ OK |
| 14 | P1:6 | Green | Port 1 FIRE | `QM1_AMIGA_B1` | OUTPUT | ✅ OK |
| 15 | - | - | Unused | - | - | ✅ Free |
| 16 | - | - | Display Right Button | `GPIO_BUTTON_RIGHT` | INPUT | ✅ OK |
| 17 | - | - | Display Middle Button | `GPIO_BUTTON_MIDDLE` | INPUT | ✅ OK |
| 18 | - | - | Display Left Button | `GPIO_BUTTON_LEFT` | INPUT | ✅ OK |
| 19 | P2:1 | Blue | Port 2 UP | `QM2_AMIGA_V` | OUTPUT | ✅ OK |
| 20 | P2:2 | Yellow | Port 2 DOWN | `QM2_AMIGA_H` | OUTPUT | ✅ OK |
| 21 | P2:3 | Red | Port 2 LEFT | `QM2_AMIGA_VQ` | OUTPUT | ✅ OK |
| 22 | P2:4 | Orange | Port 2 RIGHT | `QM2_AMIGA_HQ` | OUTPUT | ✅ OK |
| 23 | - | - | Unused | - | - | ✅ Free |
| 24 | - | - | Unused | - | - | ✅ Free |
| 25 | - | - | Onboard LED | `PICO_DEFAULT_LED_PIN` | OUTPUT | ✅ OK |
| 26 | P2:6 | Green | Port 2 FIRE | `QM2_AMIGA_B1` | OUTPUT | ✅ OK |
| 27 | P2:9 | Grey | Port 2 Button 2 | `QM2_AMIGA_B2` | OUTPUT | ✅ OK |
| 28 | P2:5 | Purple | Port 2 Button 3 | `QM2_AMIGA_B3` | OUTPUT | ✅ OK |
| 29 | - | - | Unused | - | - | ✅ Free (ADC3) |

**Summary:** ✅ **All GPIO conflicts resolved** - No conflicts detected

---

## Button Remapping Summary

The following buttons have been remapped in hardware to resolve GPIO conflicts:

### Port 1 Buttons
- **Button 2** (`QM1_AMIGA_B2`): **GPIO 12 → GPIO 2** ✅
  - **Reason:** GPIO 12 conflicted with LEFT direction (`QM1_AMIGA_VQ`)
  - **Status:** Remapped and working

- **Button 3** (`QM1_AMIGA_B3`): **GPIO 13 → GPIO 3** ✅
  - **Reason:** GPIO 13 conflicted with RIGHT direction (`QM1_AMIGA_HQ`)
  - **Status:** Remapped and working

### Port 2 Buttons
- **Button 2** (`QM2_AMIGA_B2`): **GPIO 27** (ADC1) ✅
  - Note: Was temporarily moved to GPIO 7 during debugging but reverted back to GPIO 27
  - **Reason:** GPIO 19 conflicted with UP direction (`QM2_AMIGA_V`)
  - **Status:** Remapped and working

- **Button 3** (`QM2_AMIGA_B3`): **GPIO 18 → GPIO 28** ✅
  - **Reason:** GPIO 18 conflicted with Display Left Button (`GPIO_BUTTON_LEFT`) - INPUT vs OUTPUT conflict
  - **Status:** Remapped and working

---

## Software Changes

### Removed Workarounds
The following software workarounds have been **removed** as they are no longer needed:

1. **Port 1 Button 2/3 Conditional Logic** (removed from `joystick_port1.c`)
   - Previously: Buttons only worked in mouse mode
   - Now: Buttons work in both mouse and joystick modes

2. **Port 2 Button 3 Disabled** (removed from `joystick_port2.c` and `usb_hid.c`)
   - Previously: Button 3 was commented out/disabled
   - Now: Button 3 is fully functional

### Code Updates
- `src/config.h`: Updated GPIO definitions for all remapped buttons
- `src/platform/amiga/joystick_port1.c`: Removed conditional button logic
- `src/platform/amiga/joystick_port2.c`: Re-enabled Button 3 handling
- `src/usb_hid.c`: Re-enabled Button 3 mapping for USB and Bluetooth gamepads

---

## Atari Board Compatibility Notes

This GPIO mapping is designed for the Atari board hardware, which uses:
- **I2C Display:** GPIO 8/9 on `i2c0` (matches Atari)
- **Joystick Port 1:** GPIO 10-14 (matches Atari JOY1)
- **Joystick Port 2:** GPIO 19-22, 26 (matches Atari JOY0)
- **Display Buttons:** GPIO 16-18 (matches Atari)
- **Additional Buttons:** GPIO 2, 3, 27, 28 (Amiga-specific, no Atari conflicts)

The firmware is designed to be compatible with both Amiga and Atari firmware on the same hardware board.

---

## Free GPIOs Available

The following GPIOs are currently unused and available for future expansion:

| GPIO | Status | Notes |
|---|---|---|
| 0 | Free | Available |
| 1 | Free | Available |
| 7 | Free | Available |
| 15 | Free | Available |
| 23 | Free | Available |
| 24 | Free | Available |
| 29 | Free | Available (ADC3) |

---

## Version History

- **v1.0.5**: Remapped all joystick buttons to resolve GPIO conflicts
  - Port 1 Button 2: GPIO 12 → GPIO 2
  - Port 1 Button 3: GPIO 13 → GPIO 3
  - Port 2 Button 2: GPIO 27 (ADC1) - Note: Was temporarily moved to GPIO 7 during debugging but reverted
  - Port 2 Button 3: GPIO 18 → GPIO 28
- **v1.0.4**: Fixed GPIO 18 conflict (Port 2 Button 3 vs Display Left Button) by disabling Button 3
- **v1.0.3**: Fixed Port 1 LEFT/RIGHT movement issues (GPIO direction conflicts)
- **Initial**: Identified GPIO conflicts during Atari board port

---

## References

- `src/config.h`: GPIO pin definitions
- `src/platform/amiga/joystick_port1.c`: Port 1 implementation
- `src/platform/amiga/joystick_port2.c`: Port 2 implementation
- `src/display/display.c`: Display button GPIO configuration
- `doc/gpio-fixes-todo.md`: Previous conflict documentation

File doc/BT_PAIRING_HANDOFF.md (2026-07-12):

# Bluetooth pairing hangs — handoff notes (Pico / Bluepad32 / dual-core)

**Audience:** LLM or developer working on another **ultramegausb** Pico 2 W HID adapter that sees **random Bluetooth pairing hangs** while keyboards/mice work until a gamepad pairs.

**Standalone family best practices (share this with Atari / Apple / future adapters):**  
[`doc/BT_PAIRING_BEST_PRACTICES.md`](./BT_PAIRING_BEST_PRACTICES.md)

**Applies to:** Any sibling project with the same architecture — e.g. **Atari ST IKBD**, **Amiga** keyboard/joystick USB/BT bridge, **Apple ADB** mouse/keyboard adapter — not one host protocol only.

**Reference implementation (fixes shipped):** `ultramegausb-atari-st-rpikbd` — **v22.1.0** (`RELEASE_NOTES.md` §22.1.0).

**This repo:** `ultramegausb-amiga` — see **[Amiga project status](#amiga-project-status-this-repo)** below for what is already done vs what still needs porting from Atari v22.1.0.

**Start here for implementation work:** [`doc/future_work.md`](./future_work.md) § Bluetooth pairing alignment (Atari v22.1.0).

---

## Ultramegausb family — what is usually the same

| Layer | Typical across adapters | Varies per product |
|---|---|---|
| **MCU / radio** | Raspberry Pi Pico 2 W, CYW43 BLE | Pico W (tighter RAM) |
| **Core 0** | TinyUSB host, Bluepad32, OLED UI, main loop | Input routing, shortcuts |
| **Core 1** | Tight timing loop from **XIP flash** | Atari: HD6301 emulator; **Amiga: quadrature mouse + GPIO bit-bang**; ADB: ADB bus timing |
| **BT stack** | pico-sdk BTstack + Bluepad32 platform callbacks | Device-type storage layout |
| **Flash** | BTstack TLV pairing keys + user **NVSettings** | Sector addresses per board |
| **Symptoms** | KB/mouse OK until BLE gamepad pairs; intermittent hang | Which gamepads trigger long pair |

If your adapter uses **dual-core + Core 1 in XIP + Bluepad32 on Core 0**, treat this document as directly applicable even when Core 1 is not an HD6301.

---

## Symptom pattern (what users reported)

- BLE **keyboard + mouse** work reliably.
- Pairing a **BLE HID gamepad** (Google Stadia, Xbox Wireless — CoD **0x0508**, HID-over-GATT) while KB/mouse are connected can:
  - **Hang the whole adapter** (OLED/UI frozen too → Core 0 blocked, not just Core 1).
  - Stop keyboard/mouse reaching the **host** (Atari serial, Amiga clock/data lines, ADB bus) even though the UI still updates.
- **Intermittent / “random”** — classic race with flash and multicore timing.
- **PS5 DualSense (BLE)** often unaffected; problem clustered on **longer pairing paths** (Xbox/Stadia bonding + TLV flash writes).
- Bug **vanished or moved** when verbose `printf` / `logi` was added (Heisenbug).

### Amiga-specific symptoms to watch

After pairing a BLE gamepad with BT keyboard + mouse already connected, verify on real hardware:

| Check | Pass criteria |
|---|---|
| **Keyboard serial** | Amiga still receives key events (clock/data on Port 0) |
| **Quadrature mouse** | Port 1 mouse motion and buttons still work |
| **Joystick ports** | Port 1 (shared with mouse) and Port 2 still respond |
| **OLED** | UI not frozen; Map Devices shows gamepad name after pair |
| **Reboot** | Bonded devices reconnect without hang |
| **Clear keys** | Left+Right 5 s on splash (or equivalent) → fresh pair works |

---

## Architecture that makes this possible

| Piece | Role |
|---|---|
| **Core 0** | TinyUSB, Bluepad32/BTstack, OLED, main loop (`src/main.c`) |
| **Core 1** | Timing-critical work from **XIP flash** — on Amiga: `amiga_quad_mouse_motion()` in `src/platform/amiga/quad_mouse.c` |
| **BTstack TLV** | Pairing keys / persistence written via **`flash_safe_execute()`** |
| **CYW43** | WiFi/BT chip; flash access must coordinate with **both cores** |

If Core 1 keeps executing from flash while Core 0/BTstack erases/writes flash, you get **stalls, corruption, or permanent freeze**. `flash_safe_execute()` tries to pause the other core — but only if that core cooperates.

**Amiga note:** Core 1 is a **quadrature mouse emulator** (not an HD6301), launched via `multicore_launch_core1(amiga_quad_mouse_motion)` from `quad_mouse.c`. It still runs from XIP and toggles Amiga GPIO for mouse/joystick Port 1. The same flash race applies.

---

## Root causes we confirmed (Atari v22.1.0)

### 1. Core 1 not enrolled in flash-safe multicore

**Fix:** Call `flash_safe_execute_core_init()` at the **start of Core 1** before any XIP work.

**Atari reference:** `src/main.cpp` → `core1_entry()`.  
**Amiga today:** ✅ Done — first call inside `amiga_quad_mouse_motion()` in `quad_mouse.c`.

### 2. Core 1 still in XIP during pairing flash writes

**Fix:** **Pause Core 1** before BTstack writes pairing data, resume only after enumeration completes.

- Pause on **gamepad discovery** (CoD `0x0508` or name match `Stadia` / `Xbox`), not on every BLE device.
- **BLE keyboards/mice** use a shorter path — do **not** pause Core 1 for them.
- Core 1 pause loop must **`__wfe()`** (not busy-spin forever) so multicore lockout / `flash_safe_execute` can preempt.

**Atari reference:** `main.cpp` + `bluepad32_platform.c` → `my_platform_on_device_discovered()`.  
**Amiga today:** ⚠️ Partial — pause on discovery exists (`amiga_quad_mouse_pause_core1()`), but pause loop uses `busy_wait_us(5000)` spin, **not `__wfe()`**. Core 1 also runs `sleep_us(50)` each loop iteration when not paused.

### 3. Single bool pause flag → refcount bugs

**Fix:** **Refcounted** `g_core1_pause_depth` — pause once on discovery; **do not pause again** in `on_device_connected`; resume once in `on_device_ready` (or on disconnect if pairing aborted).

**Amiga today:** ❌ Still a single `volatile bool g_core1_paused`. **Double-pause on connect** for Xbox/Stadia still present in `bluepad32_platform.c` → `my_platform_on_device_connected()`. Disconnect always calls `resume_core1()` with no depth check.

### 4. `sleep_ms()` / `__wfe()` inside Bluepad32 callbacks froze Core 0

**Fix:** In BT platform callbacks use **`busy_wait_us()` only** via `bt_callback_busy_wait_ms()`.

**Amiga today:** ❌ `sleep_ms(2000)` in `on_init_complete`; `sleep_ms(50)` / `sleep_ms(10)` in `on_device_ready` for gamepads. No `bt_callback_busy_wait_ms()` helper yet.

### 5. Resume too early (race masked by debug logging)

**Fix:** Explicit delays in `config.h`:
- `BT_GAMEPAD_DISCOVERY_SETTLE_MS` = **30**
- `BT_GAMEPAD_CORE1_RESUME_DELAY_MS` = **100**

Plus `core1_wait_for_pause_active()` after pausing.

**Amiga today:** ❌ No config constants. Ad-hoc 50 ms / 10 ms `sleep_ms` in `on_device_ready`. No settle delay after discovery pause. No `core1_wait_for_pause_active()`.

### 6. NVSettings / custom flash overlapping BTstack TLV bank

**Fix:** User flash sector must sit **below** the BTstack pairing TLV region; board-aware layout.

**Atari reference:** `NVSettings.cpp` — sector computed as `bt_bank - FLASH_SECTOR_SIZE`.  
**Amiga today:** ⚠️ **Needs audit** — `mouse_config.c` stores at `PICO_FLASH_SIZE_BYTES - FLASH_SECTOR_SIZE` (last 4 KiB). BTstack `pico_flash_bank` also uses the **end of flash** (typically last 8 KiB). These may **overlap** — same class of bug Atari fixed. Validate against `PICO_FLASH_BANK_TOTAL_SIZE` for each board before next BT hardening pass.

### 7. Main-loop timing experiments broke pairing

Cherry-picking faster USB/HID polling caused Stadia/Xbox pairing hangs. Do not speed up Core 0 without retesting **KB + mouse + gamepad** pairing.

**Amiga today:** Main loop has no fixed 10 ms HID block (runs `tuh_task()` + `amiga_service()` as fast as possible). Document baseline before tuning. `bluepad32_poll()` called every iteration when BT enabled.

### 8. BTstack version pin

Stay on **pico-sdk–pinned BTstack** (v1.6.2 era) unless you port `hids_host` + Bluepad32 HID client changes.

**Amiga today:** Same submodule pin as siblings — see `doc/submodule-versions.md`.

### 9. Core 1 work gated on `absolute_time` after BT flash (Amiga, July 2026)

**Symptom:** After Stadia (or similar long BLE bond) pairs, Core 1 heartbeat still climbs, Core 0 still feeds mouse deltas, but **host motion dies**. Amiga DIAG: `motion_feeds↑`, `consumed=0`, `quad_gpio=0`, `flag=1`.

**Cause:** Quadrature consume/GPIO updates were inside `if (absolute_time_diff_us(...) >= period)`. After bond/`flash_safe_execute` lockout that gate stopped opening while the loop kept spinning.

**Fix:** Drive Core 1 periods with a **loop counter**; consume pending motion immediately; prefer `busy_wait_us` over `sleep_us` on Core 1. Shipped Amiga **v2.2.18**. Full write-up: [`stadia-controller-verification.md`](./stadia-controller-verification.md).

**Sibling note:** Atari Core 1 already avoids `absolute_time` for its heartbeat (“Use loop counter instead of absolute_time to avoid Bluetooth blocking” in `main.cpp`). Apple ADB should audit any Core 1 path that gates **output generation** on `get_absolute_time()` across BT flash. Pause/refcount alone does not cover this failure mode.

---

## What did *not* cause the hang (ruled out)

- Map Devices OLED / `usb_device_map` / device name strings (Amiga v2.1.1+).
- Stadia vs Xbox being “classic BR/EDR only” on Pico 2 W — captures showed **BLE HID gamepads**.
- Deferring OLED updates during Xbox/Stadia enumerate (Amiga lesson) — reduces interference but is **not** the root multicore flash race.
- **Rev 6 GPIO pin remap** — orthogonal to the Amiga `consumed=0` mouse-dead mode (failed the same on forced Rev 5).

---

## Checklist for this project (Amiga)

### Boot / multicore

- [x] `flash_safe_execute_core_init()` on Core 1 entry (`quad_mouse.c`)
- [x] Core 1 motion period **not** gated solely on `absolute_time` (v2.2.18 loop counter + immediate `motion_flag` consume)
- [ ] Pause branch policy: prefer `__wfe()` *or* documented busy-wait that cannot miss SEV after flash lockout (Amiga currently uses `busy_wait_us` in pause — intentional after WFE misses)
- [ ] Confirm wireless build XIP vs `copy_to_ram` in `CMakeLists.txt` (if applicable)

### Bluetooth platform callbacks (`src/bluepad32_platform.c`)

- [ ] Replace remaining `sleep_ms` in callbacks with `bt_callback_busy_wait_ms()` / `busy_wait_us`
- [x] Refcounted / anti-stack pause API + force-release / watchdog (bisect line; fold cleanly to main)
- [x] Heartbeat stall detection + SEV / relaunch (recovers brief park during Stadia bond)
- [ ] Align discovery settle / ready delays with Atari `BT_GAMEPAD_*_MS` where still ad-hoc
- [ ] Disconnect resume only when pause depth warrants it (review force-release vs Atari)

### Flash layout

- [ ] Audit `mouse_config.c` offset vs BTstack TLV bank (see §6 above)
- [ ] Align layout with Atari `NVSettings.cpp` pattern if overlap confirmed

### Clock / RF

- [ ] Amiga runs **200 MHz** (`src/CMakeLists.txt` `SYS_CLK_MHZ=200`) — Atari BT builds use **225 MHz**. Soak-test pairing at 200 MHz; consider 225 MHz trial if CYW43 stalls appear.

### Core 0 main loop (`src/main.c`)

- [ ] Document current loop timing before changes
- [ ] Retest pairing after any `tuh_task` / HID frequency change

### Diagnostics

- [x] `motion_feeds` / `consumed` / `quad_gpio` / `period` DIAG (prove consume path)
- [ ] Gate `[DIAG]` logs behind compile flag for release — they change timing

---

## Amiga file map (where to edit)

| File | Current role | Target (Atari v22.1.0 + Amiga lessons) |
|---|---|---|
| `src/platform/amiga/quad_mouse.c` | Core 1 loop, pause API, motion consume | Keep loop-counter period (v2.2.18); finish pause API polish |
| `src/bluepad32_platform.c` | BT callbacks, discovery pause | busy_wait only; settle/ready constants |
| `src/config.h` | GPIO, version, features | `BT_GAMEPAD_*_MS` where still missing |
| `src/platform/amiga/mouse_config.c` | Mouse type flash persistence | Re-validate sector vs BTstack TLV |
| `src/main.c` | Core 0 main loop | Heartbeat watchdog tick |
| `src/CMakeLists.txt` | 200 MHz overclock | Document; optional 225 MHz BT trial |

**Diff against Atari (canonical):**

```
ultramegausb-atari-st-rpikbd/src/main.cpp          → Core 1 pause/refcount/diagnostics
ultramegausb-atari-st-rpikbd/src/bluepad32_platform.c → callback timing + discovery/ready/disconnect
ultramegausb-atari-st-rpikbd/include/config.h      → BT_GAMEPAD_*_MS constants
ultramegausb-atari-st-rpikbd/src/NVSettings.cpp    → flash sector layout pattern
```

**Amiga Stadia/mouse consume lesson (port knowledge, not pin maps):**
[`doc/stadia-controller-verification.md`](./stadia-controller-verification.md)

---

## Amiga project status (this repo)

| Item | Status | Notes |
|---|---|---|
| `flash_safe_execute_core_init()` on Core 1 | ✅ | `quad_mouse.c` |
| Gamepad discovery pause | ⚠️ | Evolving; anti-stack + optional skip paths on bisect |
| Refcounted / force-release pause | ✅/⚠️ | Present on bisect line; land cleanly on main |
| Core 1 motion not `absolute_time`-gated | ✅ | **v2.2.18** — fixes Stadia→mouse `consumed=0` |
| Heartbeat stall SEV / relaunch | ✅ | Brief park during Stadia bond still possible |
| `busy_wait_us` only in BT callbacks | ⚠️ | Partial |
| Config delay constants | ⚠️ | Partial |
| Flash sector vs BTstack TLV | ⚠️ | `mouse_config.c` — audit required |
| Map Devices / UI during pair | ✅ | Ruled out as hang cause; defer OLED on Stadia/Xbox |
| Historical “Stadia fix” (pause-only) | ⚠️ | Necessary but **not** sufficient; see v2.2.18 |

**Conclusion:** Amiga now has the **consume-path** fix for post-Stadia dead mouse motion (v2.2.18) plus earlier flash-safe / pause work. Remaining work is polishing pause/callback timing and flash layout toward full Atari v22.1.0 alignment — not re-deriving the GPIO pin table as the mouse bug.

---

## Suggested porting order (this repo)

1. Read [`doc/future_work.md`](./future_work.md) § Bluetooth pairing alignment.
2. Land v2.2.18-class Core 1 consume fix on `main` if still on a bisect/feature branch.
3. **Audit flash map** — `mouse_config.c` vs BTstack TLV (`PICO_FLASH_BANK_TOTAL_SIZE`).
4. Finish **pause/callback polish** toward Atari (`BT_GAMEPAD_*_MS`, busy_wait-only callbacks).
5. Hardware matrix on **Pico 2 W**: BT KB + BT mouse connected → pair Stadia or Xbox → keyboard/mouse/joystick still work (`consumed` tracks feeds).
6. Only then tune main-loop timing or clock speed.
7. Propagate §9 knowledge to Atari/Apple docs if their Core 1 still gates host output on `absolute_time`.

---

## `__wfe()` — why Core 1 pause uses it

**Wait For Event** — ARM instruction that sleeps the CPU until an interrupt or `__sev()` wakes it.

Pico SDK `flash_safe_execute()` sends a **multicore lockout** FIFO IRQ to Core 1. The lockout handler internally uses `__wfe()` while flash erase/program runs on Core 0.

If Core 1’s **application pause loop** busy-spins instead of `__wfe()`:

- Core 1 keeps executing pause-loop code from XIP
- IRQ latency and flash bus contention can remain higher
- Lockout may not quiesce Core 1 as reliably during BTstack TLV writes

**Rule of thumb for this family:**

| Context | Use |
|---|-----|
| Core 1 while `paused` | `__wfe()` (Atari default) — **or** short `busy_wait_us` if WFE has been observed to miss SEV after flash lockout (Amiga lesson) |
| Core 1 host-output period | **Loop counter**, not `get_absolute_time()` after BT flash (Amiga v2.2.18 / Atari heartbeat comment) |
| Core 0 inside BT callbacks (delays) | `busy_wait_us()` only |
| Core 0 inside BT callbacks (waiting for Core 1 paused) | `busy_wait_us()` poll (`core1_wait_for_pause_active`) |

Do **not** use `__wfe()` on Core 0 inside BT callbacks — it may never wake if no event is sent.

---

## References

### Atari repo (canonical fixes)

| Document | Content |
|---|---|
| `docs/BT_PAIRING_HANDOFF.md` | Generic family handoff (upstream of this file) |
| `RELEASE_NOTES.md` §22.1.0 | User-facing fix summary |
| `docs/FUTURE_WORK.md` | Regression lessons, BTstack pin |
| `docs/UI_UNIFICATION.md` | Shared OLED UI (Amiga design source) |

### This repo

| Document | Content |
|---|---|
| [`doc/future_work.md`](./future_work.md) | **Start here** — pairing alignment task list |
| [`doc/stadia-controller-verification.md`](./stadia-controller-verification.md) | Stadia USB formats + BLE/`consumed=0` mouse fix |
| [`doc/device_troubleshooting.md`](./device_troubleshooting.md) | User-facing BT/device issues |
| [`doc/todo.md`](./todo.md) | General project TODO |
| [`doc/submodule-versions.md`](./submodule-versions.md) | pico-sdk / bluepad32 pins |

---

## One-paragraph summary for paste into another LLM session

> **Context:** ultramegausb-amiga (Pico 2 W, Bluepad32, dual-core). Core 1 = quadrature mouse from XIP (`quad_mouse.c`). **Problems:** (1) BLE gamepad pairing hangs — multicore flash race during BTstack TLV; (2) after Stadia bond, mouse motion dead while Core 1 heartbeat alive — `motion_feeds↑` / `consumed=0` because consume was gated on `absolute_time` (fixed v2.2.18 with loop-counter period). **GPIO Rev 6 remap was not the mouse-dead cause.** **Port knowledge to siblings:** do not gate Core 1 host-output on `absolute_time` across BT flash; Atari already uses loop counters for Core 1 heartbeat; Apple ADB has pause/refcount — audit any absolute_time-gated output. **Read:** `doc/BT_PAIRING_HANDOFF.md` §9, `doc/stadia-controller-verification.md`, `doc/future_work.md`.

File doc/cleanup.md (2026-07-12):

# Code cleanup and optimization candidates

Advisory review of the original borb/amigahid-pico codebase versus ultramegausb additions. **No changes implemented** — use this as a checklist when hardening release builds or reducing maintenance burden.

**Branch context:** `feature/cd32` (firmware v2.2.10 at time of review).

---

## Executive summary

The **borb core** (keyboard serial bit-bang, `amiga_service()`, TinyUSB callbacks) is still the spine and should stay. A fair amount around it is either **legacy from the original tree**, **debug left on after bring-up**, or **parallel implementations** added during the ultramegausb expansion.

The biggest wins are:

1. **Gate or remove unconditional `printf` / `ahprintf`**
2. **Retire dead debug infrastructure**
3. **Trim stub/dead files**
4. **Consolidate controller → port routing** (maintenance + CD32 correctness, not just size)

`doc/performance_optimizations.md` is **partially outdated** — several items (BT early return, keyboard→display path) are already fixed or commented out.

---

## 1. Modifier / toggle key debug spam (high priority)

### Problem

Holding modifier keys (Shift, Left Amiga / GUI) floods UART on **every keyboard report**, not only when a toggle fires. Example from a BT keyboard session:

```
[TOGGLE-BT] Shift:0 LAmiga:1 J:0 Combo:0 Modifier:0x08 Keys:
[TOGGLE-BT] Shift:0 LAmiga:1 J:0 Combo:0 Modifier:0x08 Keys:
... (repeats while Left Amiga held)
[TOGGLE-BT] Shift:1 LAmiga:0 J:0 Combo:0 Modifier:0x02 Keys:
... (repeats while Shift held)
[TOGGLE-BT] Shift:1 LAmiga:1 J:1 Combo:1 Modifier:0x0a Keys: 0x0d
[CONFIG] Saving: mouse=Amiga port1=1 port2_cd32=1
[TOGGLE-BT] *** Port 1 mode: JOY ***
[TOGGLE-BT] Blocking J key from being sent to Amiga
```

This is noisy during normal use, competes with USB/BT timing on the serial link, and makes real errors harder to spot.

### Source locations

| Tag | File | Lines (approx.) | Behaviour |
|-----|---|---|---|
| `[TOGGLE-BT]` modifier trace | `src/usb_hid.c` | ~907–917 | Prints whenever **any** of Shift, LAmiga, J is pressed, or combo is active — **every BT keyboard report** while modifiers held |
| `[TOGGLE-BT] *** Port 1 mode` | `src/usb_hid.c` | ~922 | On successful Port 1 mouse/joy toggle (acceptable as one-shot; keep or gate) |
| `[TOGGLE-BT] Blocking J key` | `src/usb_hid.c` | ~959 | Every report while J blocked during combo |
| `[LLAMATRON-BT]` / `[CD32-BT]` | `src/usb_hid.c` | ~927–968 | Same pattern for L and C chords |
| `[TOGGLE]` (USB path) | `src/usb_hid.c` | ~643–746 | **Identical** modifier spam for USB keyboards (`[TOGGLE]` prefix) |
| `[CONFIG] Saving:` | `src/platform/amiga/mouse_config.c` | ~102 | Unconditional `printf` on every flash save (triggered by each mode toggle) |

All `[TOGGLE*]` / `[LLAMATRON*]` / `[CD32*]` lines use **`ahprintf`**, which is enabled whenever root `CMakeLists.txt` sets `DEBUG_MESSAGES=1` (currently always on).

### Recommendation

- **Remove** the per-report modifier trace blocks (USB ~685–695, BT ~907–917) from release builds entirely.
- **Keep one-shot** messages on actual toggle (`*** Port 1 mode`, CD32 on/off) only behind a debug flag, or drop them if OLED already reflects mode.
- **Remove** “Blocking J/L key” per-report lines; log once on combo edge if still needed for bring-up.
- Gate `[CONFIG] Saving:` behind `DEBUG_MESSAGES` or a dedicated `CONFIG_DEBUG` — flash save on every toggle is expected behaviour, not something users need in serial output.
- Consider a single compile flag, e.g. `KEYBOARD_TOGGLE_DEBUG`, shared by USB and BT paths (mirrors existing `KEYBOARD_HID_DEBUG` pattern in `config.h`).

---

## 2. Safe to remove or simplify (low risk)

### Dead / hollow code from borb era

| Item | Location | Notes |
|---|---|---|
| **`keyboard.pio`** | `src/platform/amiga/keyboard.pio` + CMake `pico_generate_pio_header` | Stub only (`amiga_send_pio_init` does nothing). `keyboard_serial_io.c` includes `keyboard.pio.h` but never uses PIO. Remove PIO build + include. |
| **`hid_app_task()`** | `usb_hid.c` (empty stub); `extern` in `main.c` but **never called** | Leftover from original `main` loop; main uses `tuh_task()` only. |
| **`dbgcons_*` counter machinery** | `debug_cons.c` / `debug_cons.h` | Counters increment on plug/unplug but **nothing reads them**; `dbgcons_print_counters()` is empty; `dbgcons_amiga_key` / `dbgcons_amiga_mod` are no-ops. Only `dbgcons_init()` VT100 clear + `dbgcons_plug/unplug` from `usb_hid.c` still run. **Candidate to delete entire module** and drop plug/unplug calls. |
| **`cd32_service()`** | `cd32_pad.c` | Empty function; still called every main-loop iteration. Remove call + symbol, or repurpose if deferred JOYMODE work returns. |
| **`*_connected_count()`** | PS3/4/5, Xbox, Stadia, Switch, PSC, HORI headers + `.c` | Exported but **never called** anywhere in the tree. |
| **`joystick_port2_get_*()`** | `joystick_port2.c` | Marked “for debugging”; no callers found. |
| **`main.c` `extern hid_app_task`** | Dead reference | Remove with `hid_app_task`. |

### Stale documentation (misleading, not runtime cost)

- `doc/oled_display_analysis.md` — still describes **µgui**; display is **ssd1306** now.
- `doc/performance_optimizations.md` — §1 (keystroke→display) largely fixed; §2 (BT every loop) **already implemented** via `process_bluepad32_devices()`.
- `doc/debug_logging_removed.md` — title says “removed” but body documents **added** logging; confusing.
- Root README still has old “pin mappings not in source” note while Rev 5 is in `config.h`.

---

## 3. Debug / logging — high value cleanup

### Two logging systems, inconsistent gating

| Path | Gating | Issue |
|---|---|---|
| **`ahprintf` / `DEBUG_MESSAGES`** | Root `CMakeLists.txt`: **`DEBUG_MESSAGES=1` always on** | All `ahprintf` in `usb_hid.c` (CD32 toggles, modifier spam, etc.) goes to UART in “release” builds. |
| **`printf` in vendor drivers** | **Always on** — not behind `DEBUG_MESSAGES` | PS3/PS4 especially noisy. |
| **`logi` in Bluepad32 platform** | Bluepad32 compile config | Very chatty on connect/discover; `[DIAG]` paths still present; contributes to UART corruption under CD32+BT (`doc/future_work.md`). |
| **`printf` in `main.c`** | Always on | Startup banner + `[GPIO]` — fine for dev; optional compile flag for production. |
| **`printf` in `mouse_config.c`, `port_mode.c`, `cd32_pad.c`** | Always on | Config save/load and mode changes on every toggle. |
| **`KEYBOARD_HID_DEBUG`** | **Off** in `config.h` ✓ | Good pattern — extend to toggle/modifier debug and vendor drivers. |

### Worst offenders (gate or remove)

1. **`ps4_controller.c`** — mount banner (~15 lines), first-report hex dump, **every 100th report** `printf` in the hot path.
2. **`ps3_controller.c`** — similar mount banner + init `printf` spam.
3. **`bluepad32_platform.c`** — discovery/ready/disconnect `logi` on every device; `sleep_ms` in callbacks (separate from logging, but pairs with debug-era code).
4. **`display_show_controller_detected()`** — **`sleep_ms(3000)`** blocks Core 0 on every USB controller mount (all vendor drivers call it). Bad for BT pairing timing; consider non-blocking splash or skip when BT busy.
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

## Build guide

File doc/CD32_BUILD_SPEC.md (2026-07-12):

# CD32 controller support — build specification

**Branch:** `feature/cd32`  
**Status:** Implemented (v2.2.2) — dual Port 1 + Port 2 CD32; **known instability** (see §9 risks + `doc/future_work.md`)  
**Hardware target:** Rev 5 (`HIDPICO_REVISION == 5`) — Pico 2 W + ultramegausb board  
**Prior research:** [`doc/cd32_pad_implementation_plan.md`](./cd32_pad_implementation_plan.md) (2024 draft — superseded; kept for protocol background)  
**Protocol reference:** [PSCD32 Development Diary, 9 Aug 2019](https://www.mrdictionary.net/PSCD32/diary/2019_08_09.htm) (Mathew Carr) — analysis of Gerd Kautzmann’s CD32 pad schematic; **authoritative DB-9 pin roles** below.

---

## 1. Goal

Enable **Amiga CD32 gamepad protocol** emulation so USB and Bluetooth gamepads expose the **seven face/trigger/start buttons** (plus D-pad) that CD32 software expects — not only the three buttons of a standard Amiga joystick.

**User-visible outcome:**

- Toggle a port into **CD32 mode** when playing CD32-enhanced Amiga titles.
- Map modern gamepad inputs → CD32 **Blue / Red / Yellow / Green / R / L / Start**.
- Keep existing **mouse**, **standard joystick**, and **Llamatron** modes unchanged when CD32 is off.

**Non-goals (v1):**

- Emulating a real CD32 console (audio, CD, etc.).
- Auto-detecting CD32 vs standard joystick from the Amiga side (optional later).
- Per-game mapping profiles or remapping UI.
- CD32 on Rev 2/4 boards (Rev 5 only for v1).

---

## 2. Protocol summary (from PSCD32 diary + pad schematic)

The CD32 pad is **not** “Clock/Latch/Data on direction pins 2–4”. That model (seen in some adapter projects) does **not** match the real Commodore CD32 controller hardware.

### How the real CD32 pad works

The Amiga joyport has **three bidirectional lines** (pins 5, 6, 9 — POT0X, FIRE0, POT0Y) that Paula/Akiko can drive or read. The CD32 pad uses a **74LS165** shift register plus **74LS125** tri-state buffers. Two modes, selected by **JOYMODE** on **pin 5**:

| JOYMODE (pin 5) | Mode | Behaviour |
|---|---|---|
| **High** | Dumb 2-button joystick | **Red** grounds pin 6 (Fire1); **Blue** grounds pin 9 (Fire2). Like SMS / 2-button joy. |
| **Low** | 7-button shift mode | On **falling edge** of JOYMODE, latch Blue/Red/Yellow/Green/FF/Rew/Pause into shift register. **Blue** appears on pin 9 (DATA). Each **rising edge** on pin 6 (CLOCK) shifts next bit. |

**Shift order** (on pin 9 DATAOUT, active low when pressed):  
**Blue → Red → Yellow → Green → FF (right shoulder) → Rew (left shoulder) → Pause → 1 → 0 → 0 → …**

**D-pad** pins 1–4 (Up/Down/Left/Right) are **always** simple switches to ground — unchanged in both modes.

**Pin 6 (FIRE0 / CLOCKIN)** is **bidirectional**: output (Red fire) when JOYMODE high; **input** (clock) when JOYMODE low. Firmware must **release/tri-state** pin 6 in shift mode to avoid bus contention with the Amiga.

**Bus contention:** Games can flip JOYMODE at any time. The pad (our firmware) must never fight the Amiga driving the same line — use open-drain / high-Z where appropriate (PSCD32 uses current-limiting resistors on adapter hardware).

### Authoritative DB-9 pin table (PSCD32 / Gerd Kautzmann)

| DB-9 pin | Amiga signal | CD32 pad role | Direction (pad view) |
|---|---|---|---|
| 1 | UP | Up | Pad → Amiga (switch) |
| 2 | DOWN | Down | Pad → Amiga (switch) |
| 3 | LEFT | Left | Pad → Amiga (switch) |
| 4 | RIGHT | Right | Pad → Amiga (switch) |
| 5 | POT0X | **JOYMODE / FRAME** | Amiga → Pad |
| 6 | FIRE0 | **FIRE1OUT / CLOCKIN** | Bidirectional |
| 7 | +5V | +5V | Power |
| 8 | GND | GND | Ground |
| 9 | POT0Y | **FIRE2OUT / DATAOUT** | Pad → Amiga (serial data) |

### Rev 5 GPIO mapping (Port 2 — v1 target)

| DB-9 | CD32 role | Port 2 GPIO | Firmware role in CD32 mode |
|---|---|---|---|
| 1 | Up | 19 `QM2_AMIGA_V` | Output (switch to GND) |
| 2 | Down | 20 `QM2_AMIGA_H` | Output (switch to GND) |
| 3 | Left | 21 `QM2_AMIGA_VQ` | Output (switch to GND) |
| 4 | Right | 22 `QM2_AMIGA_HQ` | Output (switch to GND) |
| 5 | JOYMODE | 28 `QM2_AMIGA_B3` | **Input** — watch HIGH/LOW + falling edge |
| 6 | CLOCKIN | 26 `QM2_AMIGA_B1` | **Input** (shift mode) or open-drain out (dumb mode / Red) |
| 9 | DATAOUT | 27 `QM2_AMIGA_B2` | **Output** — serial button bits |

### Rev 6 GPIO mapping (Port 2 — direct 5V, no level shifters)

Same DB-9 roles; fire/B2/B3 moved off ADC pins. See [`doc/gpio_rev6_adc_avoidance.md`](./gpio_rev6_adc_avoidance.md).

| DB-9 | CD32 role | Port 2 GPIO | Firmware role in CD32 mode |
|---|---|---|---|
| 5 | JOYMODE | **18** `QM2_AMIGA_B3` | **Input** |
| 6 | CLOCKIN | **16** `QM2_AMIGA_B1` | **Input** / open-drain out |
| 9 | DATAOUT | **17** `QM2_AMIGA_B2` | **Output** |

Port 1 equivalent: pins 5/6/9 → GPIO **3** (B3), **14** (Fire), **2** (B2); directions → GPIO 10–13.

> **Correction history:** Early drafts assumed Clock/Latch/Data on pins 2–4 (direction lines). The PSCD32 diary shows serial signalling on **pins 5, 6, 9** — which on Rev 5 are exactly our **B3 / Fire / B2** GPIOs, not the quadrature/direction pins.

### Recommended v1 target: **Port 2**

| Factor | Port 1 | Port 2 |
|---|---|---|
| USB gamepad routing today | ❌ All USB pads → Port 2 only | ✅ Primary gamepad port |
| BT gamepad #1 | Port 2 | ✅ |
| Mouse quadrature (Core 1) | ⚠️ Shares GPIO 10–13 | ✅ No conflict |
| Port 1 mode complexity | MOUSE / JOY / LLAMA | N/A |
| CD32 games (typical) | Some titles use Port 1 | Many use Port 2 / either port |

**Decision:** Implement **CD32 on Port 2 first**. Port 1 CD32 is **Phase 2** (requires pausing Core 1 quadrature and extending Port 1 mode machine).

### Mode selection: user toggle (not auto-detect)

Same recommendation as the 2024 plan:

- **User-selectable** CD32 mode via OLED + button (consistent with Port 1 MOUSE/JOY/LLAMA cycle).
- **Persist** preference in flash (extend `mouse_config` or new `port_config` sector — audit vs BTstack TLV per [`doc/BT_PAIRING_HANDOFF.md`](./BT_PAIRING_HANDOFF.md)).
- **No auto-detect** in v1 (JOYMODE can toggle anytime; optional monitor later).

### ISR design (updated for real protocol)

| Event | Action |
|---|---|
| JOYMODE (pin 5) **falling edge** | Latch gamepad state into shift register; present **Blue** on DATA (pin 9); reset bit index |
| CLOCK (pin 6) **rising edge** (JOYMODE low) | Advance shift; drive next bit on DATA (v2.1.2 timing, always-on IRQ) |
| JOYMODE **high** | Dumb mode: optionally drive Red on pin 6, Blue on pin 9 as switches; no clock ISR |

No separate “Latch pin” — latch is **JOYMODE falling edge**.

---

## 3. Current firmware baseline

### What exists today

| Capability | Status |
|---|---|
| Standard joystick (3 buttons + 4-way) | ✅ Port 1 & 2 |
| USB gamepads → Port 2 | ✅ Generic HID + vendor drivers (`usb_controllers/`, `xbox_controller.c`) |
| BT gamepad #1 → Port 2 | ✅ `process_bluepad32_gamepad()` |
| BT gamepad #2 → Port 1 (joy mode) or mouse buttons | ✅ |
| Llamatron (1× BT pad, 2 ports) | ✅ BT only |
| CD32 serial protocol | ❌ |
| 7-button gamepad mapping | ❌ (only Fire + B2 + B3) |

### Default gamepad → joystick mapping (to replace in CD32 mode)

| Gamepad (Bluepad32) | Standard Port 2 |
|---|---|
| `BUTTON_A` | Fire |
| `BUTTON_B` | Button 2 |
| `BUTTON_X` / `BUTTON_Y` | Button 3 |
| `throttle` / `brake` | *(ignored)* |
| `misc_buttons` (Start/Select) | *(ignored)* |
| Left stick / D-pad | Directions |

Vendor USB drivers (PS4, Xbox, Switch, etc.) follow the same **3-button** ceiling via `amiga_joystick_port2_set_button()`.

---

## 4. CD32 gamepad mapping (target)

Single default layout for v1 (Xbox-style / Bluepad32 names):

| CD32 button | Shift index | Gamepad source (default) |
|---|---|---|
| Blue | 0 | `BUTTON_B` |
| Red | 1 | `BUTTON_A` |
| Yellow | 2 | `BUTTON_Y` |
| Green | 3 | `BUTTON_X` |
| R-trigger | 4 | `brake` > threshold **or** `BUTTON_TR` if available |
| L-trigger | 5 | `throttle` > threshold **or** `BUTTON_TL` |
| Start | 6 | `misc_buttons` Start / Pause — PSCD32 calls this **Pause** |
| *(pad)* | 7 | always `1` |
| *(pad)* | 8 | always `0` |

**D-pad / left stick:** Drive GPIO **19–22** (pins 1–4) as parallel switches in both modes — always independent of the shift register.

**Dumb mode (JOYMODE high):** Some titles only read Red/Blue as Fire1/Fire2 on pins 6/9 before entering shift mode. Optionally mirror **Red** → pin 6, **Blue** → pin 9 when JOYMODE is high (verify in Phase 0).

### Input sources when CD32 mode active (Port 2)

| Source | v1 behaviour |
|---|---|
| USB gamepad (first connected) | ✅ Map through CD32 layer |
| BT gamepad #1 | ✅ Map through CD32 layer |
| BT gamepad #2 | Standard Port 1 only (unchanged) |
| Llamatron | **Disabled** while either port CD32 active (mutually exclusive) |

---

## 5. Software architecture

### New module: `cd32_pad.c` / `cd32_pad.h`

Responsibilities:

1. **GPIO mode setup** — directions OUT; pin 5 IN (JOYMODE); pin 6 IN or open-drain OUT; pin 9 OUT (DATA).
2. **GPIO IRQ handlers** — JOYMODE ↓ (latch + first bit); CLOCK ↑ on pin 6 when JOYMODE low (shift). Reference: PSCD32 diary + [KTRL_CD32](https://github.com/MickGyver/KTRL-CD32) (verify KTRL’s wire labels vs DB-9 pin numbers).
3. **Shift register state** — 9 bits, active-low button storage updated from gamepad mapper.
4. **API** for gamepad layer:

```c
void cd32_pad_init(uint8_t port);           // port 2 first
void cd32_pad_enable(bool on);
bool cd32_pad_is_enabled(void);
void cd32_pad_set_buttons(const cd32_buttons_t* b);  // logical CD32 buttons
void cd32_pad_set_dpad_up(bool pressed);    // parallel pin 1
```

```c
typedef struct {
    bool blue, red, yellow, green;
    bool r_trigger, l_trigger, start;
    bool fire;   // parallel pin 6
} cd32_buttons_t;
```

### Integration points

| File | Change |
|---|---|
| `src/platform/amiga/cd32_pad.c` | **New** — protocol + ISRs |
| `src/platform/amiga/cd32_pad.h` | **New** |
| `src/platform/amiga/joystick_port2.c` | When CD32 off: existing path. When on: delegate directions/fire to `cd32_pad` |
| `src/usb_hid.c` | `cd32_map_from_gamepad()`; branch in `handle_event_gamepad`, `process_bluepad32_gamepad` |
| `src/usb_controllers/*.c` | Each `*_update_amiga_joystick()` → call shared CD32 mapper when enabled |
| `src/config.h` | `CD32_*` GPIO aliases (port 2); `ENABLE_CD32` |
| `src/display/display.c` | Splash/Devices: show `CD32` mode; extend left-button cycle or add Port 2 mode |
| `src/platform/amiga/mouse_config.c` or new `port_config.c` | Persist CD32 enable flag |
| `src/CMakeLists.txt` | Add `cd32_pad.c` |

### Core 0 vs Core 1

| Core | Workload |
|---|---|
| **Core 0** | CD32 ISRs, gamepad mapping, USB/BT poll |
| **Core 1** | Quadrature mouse on Port 1 GPIO 10–13 only |

**Port 2 CD32 does not require Core 1 changes** for v1.

**Port 1 CD32 (Phase 2):** Must **pause Core 1** (`g_core1_paused` / `amiga_quad_mouse_pause_core1`) while CD32 ISRs own GPIO 10–13.

### Timing

- Latch/Clock pulses: ~10–20 µs (Amiga-driven).
- ISRs must be short: load next bit onto DATA, no `printf`, no flash access.
- Mark ISR paths `__not_in_flash_func` if placed in RAM.
- Consider `gpio_set_irq_callback` with both pins sharing one handler (KTRL pattern).

---

## 6. UI / UX

### Mode indication

Extend **Devices** screen footer (Port 2 line) or splash title when CD32 active:

```
Port2:  CD32
```

### Toggle mechanism (proposal)

**Option A (recommended):** Extend **left button** on Splash/Devices to cycle Port 2:

```
STD → CD32 → STD
```

Keep Port 1 cycle separate: `MOUSE → JOY → LLAMA → MOUSE`.

**Option B (implemented):** Keyboard chord: **Shift + Left Amiga + C** — USB and Bluetooth keyboards (Left GUI = Left Command / Left Windows).

### Map Devices screen

When CD32 active, Map Devices row **J2** could show `CD32` suffix — optional v1.1.

---

## 7. Implementation phases

### Phase 0 — Validation (2–4 h)

- [x] Read PSCD32 diary § “The CD32 stuff” + Gerd Kautzmann schematic mirror.
- [x] Read KTRL_CD32 — **map Arduino pin labels to DB-9 pins 5/6/9**, not direction pins.
- [x] Confirm Rev 5 PCB: pin 5 = GPIO 28, pin 6 = GPIO 26, pin 9 = GPIO 27 on Port 2.
- [ ] Logic analyser on Amiga: capture JOYMODE + CLOCK + DATA during a CD32 game boot (optional).
- [x] Test titles: amiga-test-kit CD32 pad test; *Rainbow Islands* (in-game).

### Phase 1 — Port 2 CD32 core (8–12 h)

- [x] Add `cd32_pad.c/h` with state machine + ISRs (Port 2 GPIOs).
- [x] `cd32_port2_set_enabled()` — directions on GPIO 19–22; JOYMODE GPIO 28 IN; CLOCK GPIO 26 IN/OD; DATA GPIO 27 always OUTPUT.
- [x] `port2_gamepad_submit()` unified mapper from gamepad struct.
- [x] Wire `usb_hid.c` + PS4/Xbox/Stadia + BT `process_bluepad32_gamepad()` through CD32 path.
- [x] **Protocol fixes (v2.1.2):** release CLOCK before JOYMODE latch (avoid bus contention); DATA driven as OUTPUT HIGH/LOW in ISR (KTRL-CD32 style, not INPUT tri-state per bit).

### Phase 2 — Full gamepad routing + UI (4–6 h)

- [x] Route PS4, Xbox, Stadia, generic HID, and BT gamepad #0 through `port2_gamepad_submit()`.
- [x] OLED Devices footer: `Port2: CD32` / `Port2: STD`.
- [x] Toggle: **Shift + Left Amiga + C** (USB + BT keyboards).
- [x] Flash persistence for CD32 flag and Port 1 mode (`port_config` in flash).
- [x] Disable Llamatron when CD32 on (and vice versa).
- [ ] Remaining USB drivers (PS3, PS5, Switch, PSC, HORI) — still on legacy 3-button path when CD32 off; need `port2_gamepad_submit()` when CD32 on.

### Phase 3 — Hardware soak (4–8 h)

- [x] amiga-test-kit CD32 pad detection + per-button mapping (BT Stadia, BT PS5).
- [x] In-game: *Rainbow Islands*.
- [ ] Full matrix in §8.
- [ ] Regression: standard joystick mode, mouse, keyboard, BT pairing unchanged.

### Phase 4 — Port 1 CD32

- [x] `cd32_pad.c` — **independent per-port shift state** (Port 1 + Port 2 can run CD32 simultaneously).
- [x] Core 1 paused when Port 1 CD32 active; mouse buttons blocked on serial GPIOs.
- [x] BT gamepad #2 → `port1_gamepad_submit()` when Port 1 CD32; BT gamepad #1 → Port 2 when Port 2 CD32 (dual-pad setup).
- [x] OLED left button: **MOUSE → JOY → LLAMA → CD32 → MOUSE** (splash + Devices screen).
- [ ] USB gamepad routing to Port 1 CD32 (USB pads still Port 2 only).

---

## 8. Test matrix

| # | Setup | Action | Pass |
|---|---|---|---|
| 1 | CD32 off, USB pad | Play standard 1-button game | Fire + directions OK |
| 2 | CD32 on, USB pad | CD32 title | All 7 buttons + D-pad |
| 3 | CD32 on, BT pad #1 | Same | **Pass** (Stadia, PS5) |
| 4 | CD32 on | Toggle off mid-game | Returns to 3-button joy |
| 5 | CD32 on | Reboot | Mode restored from flash — **Pass** (Port 1 mode + Port 2 CD32) |
| 6 | CD32 on + Llamatron attempt | Toggle Llamatron | Llamatron blocked or CD32 disabled with message — **Pass** |
| 7 | CD32 on | USB keyboard + mouse still work | No regression |
| 8 | CD32 on | Pair new BT gamepad | Pairing OK (after BT v22.1.0 port if needed) |
| 9 | Standard joy Port 1 | Mouse + Port 1 unchanged while Port 2 CD32 | No cross-talk |
| 10 | Port 1 CD32 + Port 2 CD32 | Two BT pads (#1 → P2, #2 → P1) | Both shift registers independent; mouse unavailable on P1 |

---

## 9. Risks

| Risk | Mitigation |
|---|---|
| ISR timing too slow | RAM functions; minimal ISR work; test on real Amiga early |
| Wrong pin assignment (pins 2–4 vs 5/6/9) | Follow PSCD32 / pad schematic; Phase 0 LA capture |
| Bus contention on pin 6 | Open-drain + release when JOYMODE low; never drive CLOCK while Amiga clocks |
| D-pad vs serial | Pins 1–4 always parallel — no conflict |
| Flash persist overlaps BT TLV | Use Atari `NVSettings` sector math before adding flags |
| USB driver duplication | Single `cd32_apply_gamepad(port, buttons, axes)` called from all drivers |
| Games expecting Port 1 CD32 | Document Port 2 default; Phase 4 for Port 1 |
| Shift-register timing (v2.2.2) | Ghost adjacent buttons; fix DATA/CLOCK edge timing — see `doc/future_work.md` |
| BT slot routing on disconnect | First-free-slot assignment; survivor pad unrouted — see `doc/future_work.md` |
| UART log corruption (v2.2.2) | Concurrent printf/logi under CD32+BT load; Bluepad32 mouse 0xff43 spam — see `doc/future_work.md` |

---

## 10. Versioning & docs

- Bump `SOFTWARE_VERSION_MINOR` when CD32 ships (e.g. v2.2.0).
- Update README feature list.
- Archive note at top of `cd32_pad_implementation_plan.md` pointing here.

---

## 11. References

| Resource | URL |
|---|-----|
| **PSCD32 diary (protocol deep-dive)** | https://www.mrdictionary.net/PSCD32/diary/2019_08_09.htm |
| Gerd Kautzmann CD32 pad schematic | http://gerdkautzmann.de/cd32gamepad/cd32gamepad.html |
| KTRL_CD32 (firmware reference) | https://github.com/MickGyver/KTRL-CD32 |
| 9pin2supergun | https://github.com/turmoni/9pin2supergun |
| Amiga Hardware Manual — controller | https://amigadev.elowar.com/read/ADCD_2.1/Hardware_Manual_guide/node017E.html |
| Prior internal plan | [`doc/cd32_pad_implementation_plan.md`](./cd32_pad_implementation_plan.md) |
| joypad-os button layouts (future) | [`doc/joypad-os-investigation.md`](./joypad-os-investigation.md) |
| Rev 5 GPIO | [`src/config.h`](../src/config.h) |

---

## 12. Quick start for implementers

1. Check out `feature/cd32`.
2. Read this spec + KTRL_CD32 `loop()` / ISR sections.
3. Implement **Phase 0** pin verification on bench.
4. Implement **Phase 1** `cd32_pad.c` for **Port 2 only**.
5. Branch `usb_hid.c` gamepad path through `cd32_pad_set_buttons()`.
6. Run test matrix §8 before merging.

**Start task list:** [`doc/future_work.md`](./future_work.md) § CD32 controller support.

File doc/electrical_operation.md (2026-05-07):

# Electrical Operation of the Amiga Joystick Adapter

This document explains how the amigahid-pico adapter interfaces with the Amiga joystick port at an electrical level.

## 1. Amiga Joystick Port Electrical Characteristics

The Amiga joystick port uses **active-low logic** with pull-up resistors:

- **Voltage levels**: 5V logic (Amiga) vs 3.3V logic (RP2040)
- **Signal logic**: **Active low** (LOW = pressed/active, HIGH = released/inactive)
- **Pull-up resistors**: The Amiga has internal pull-up resistors (typically ~10kΩ) that pull signals HIGH when nothing is connected
- **Input impedance**: The Amiga reads these as digital inputs

## 2. How the RP2040 Interfaces Electrically

The adapter uses a clever technique to drive 5V signals from 3.3V GPIO:

```
When INACTIVE (button/direction released):
  - RP2040 GPIO configured as INPUT (high impedance)
  - Amiga's internal pull-up resistor pulls the line HIGH (5V)
  - Amiga sees: HIGH = inactive/released ✓

When ACTIVE (button/direction pressed):
  - RP2040 GPIO configured as OUTPUT
  - RP2040 drives the line LOW (0V / GND)
  - Amiga sees: LOW = active/pressed ✓
```

## 3. Electrical Implementation Details

From `gpio_util.c`:

```c
void amiga_gpio_set_active_low(uint32_t gpio, bool active)
{
    if (active) {
        // ACTIVE: Drive LOW (0V) by setting as OUTPUT and writing 0
        gpio_put(gpio, 0);           // Drive to 0V
        gpio_set_dir(gpio, GPIO_OUT); // Enable output driver
    } else {
        // INACTIVE: Let Amiga pull-up do the work
        gpio_set_dir(gpio, GPIO_IN);  // High impedance (tristate)
        // Amiga's pull-up resistor pulls line to 5V
    }
}
```

## 4. Electrical Circuit Diagram (Simplified)

```
Amiga Joystick Port          RP2040 GPIO Pin
     (5V logic)              (3.3V logic)
         |                         |
    [10kΩ]                    [GPIO]
    Pull-up                      |
         |                       |
    ┌────┴────┐              ┌───┴───┐
    │  Amiga  │              │ RP2040│
    │  Input  │◄─────────────┤ GPIO  │
    │  Pin    │              │       │
    └─────────┘              └───────┘
         |                         |
        GND                       GND
```

## 5. Voltage Level Compatibility

- **RP2040 GPIO**: 3.3V tolerant, can sink current to GND
- **Amiga input**: 5V TTL logic, reads LOW as < 0.8V, HIGH as > 2.0V
- **Compatibility**: When RP2040 drives LOW (0V), Amiga reads it as LOW. When RP2040 is high-Z, Amiga's pull-up pulls to 5V, which the RP2040 can tolerate (it's 5V-tolerant as input).

## 6. Example: Pressing UP Direction

**Electrical sequence:**

1. **Initial state (UP not pressed):**
   - RP2040: GPIO 19 (UP) = INPUT (high-Z)
   - Amiga: Line pulled HIGH (5V) by pull-up
   - Amiga reads: HIGH = UP not pressed

2. **User presses UP:**
   - Software: `amiga_joystick_port2_set_direction(AJ2_UP, true)`
   - RP2040: GPIO 19 = OUTPUT, drives LOW (0V)
   - Amiga: Line pulled LOW (0V)
   - Amiga reads: LOW = UP pressed

3. **User releases UP:**
   - Software: `amiga_joystick_port2_set_direction(AJ2_UP, false)`
   - RP2040: GPIO 19 = INPUT (high-Z)
   - Amiga: Line pulled HIGH (5V) by pull-up
   - Amiga reads: HIGH = UP not pressed

## 7. Current Flow

**When active (driving LOW):**
- Current flows: Amiga 5V → Pull-up resistor (10kΩ) → RP2040 GPIO (sinking to GND)
- Current: ~0.5mA per pin (5V / 10kΩ)
- RP2040 GPIO can sink up to ~12mA, so this is safe

## 8. Why This Works

1. **No level shifter needed**: The RP2040 doesn't need to drive HIGH; it only drives LOW or floats
2. **Pull-up does the work**: The Amiga's pull-up provides the HIGH state
3. **Low power**: Only draws current when active (driving LOW)
4. **Fast switching**: GPIO can switch between input/output quickly

## 9. Safety Considerations

- **No 5V on RP2040**: The RP2040 never drives 5V; it only sinks to GND or floats
- **Input protection**: RP2040 GPIOs are 5V-tolerant as inputs, so the 5V pull-up is safe
- **Current limiting**: The 10kΩ pull-up limits current to safe levels

---

## Risks to the Amiga

### Low Risk Scenarios

1. **Normal Operation**
   - **Risk Level**: Very Low
   - **Description**: During normal operation, the adapter only sinks current to GND when active, which is exactly what a physical joystick would do
   - **Mitigation**: The design mimics standard joystick behavior

2. **GPIO Configuration Errors**
   - **Risk Level**: Low
   - **Description**: If a GPIO is accidentally configured as OUTPUT and driven HIGH (3.3V), the Amiga would see this as a valid HIGH signal (3.3V > 2.0V threshold)
   - **Mitigation**: The code never drives HIGH; it only drives LOW or floats

3. **Software Bugs**
   - **Risk Level**: Low
   - **Description**: A bug could cause multiple directions to be active simultaneously (e.g., UP and DOWN at the same time)
   - **Impact**: This would be equivalent to a faulty joystick - the Amiga would read conflicting inputs, but no electrical damage would occur
   - **Mitigation**: The code tracks state and prevents conflicts

### Potential Risks (Theoretical)

1. **Short Circuit Protection**
   - **Risk Level**: Very Low (theoretical)
   - **Description**: If the RP2040 GPIO output driver fails short to GND permanently, it would continuously sink current
   - **Impact**: Would draw ~0.5mA continuously (negligible)
   - **Mitigation**: RP2040 GPIOs have built-in protection diodes and current limiting

2. **Overcurrent Protection**
   - **Risk Level**: Very Low
   - **Description**: The 10kΩ pull-up resistor limits current to ~0.5mA per pin, well below the RP2040's 12mA sink capability
   - **Mitigation**: Built-in current limiting in RP2040 GPIO drivers

3. **Voltage Spikes**
   - **Risk Level**: Very Low
   - **Description**: The Amiga's 5V supply could have voltage spikes during power-on or power-off
   - **Impact**: RP2040 GPIOs are 5V-tolerant as inputs (can handle up to 3.3V + 0.3V = 3.6V, but datasheet shows they can tolerate 5V as inputs)
   - **Mitigation**: When configured as INPUT, the GPIO is high-impedance and protected

4. **Ground Potential Differences**
   - **Risk Level**: Very Low
   - **Description**: If the Amiga and RP2040 have different ground potentials, current could flow through signal lines
   - **Impact**: Minimal - both devices share the same ground through the connector
   - **Mitigation**: Proper grounding through the connector

### Real-World Safety Assessment

**Overall Risk to Amiga: VERY LOW**

**Reasons:**
1. **Current limiting**: The 10kΩ pull-up resistors limit current to ~0.5mA per pin, which is negligible
2. **Standard behavior**: The adapter behaves exactly like a physical joystick (sinks to GND when active)
3. **No high voltage**: The adapter never drives voltages higher than 3.3V
4. **Input protection**: RP2040 GPIOs have built-in protection
5. **Isolation**: When inactive, the GPIO is high-impedance, providing electrical isolation

**Comparison to Physical Joystick:**
- A physical joystick shorts the signal line to GND when pressed (same as adapter)
- A physical joystick leaves the line floating when released (same as adapter when GPIO is INPUT)
- The adapter behaves identically to a physical joystick from the Amiga's perspective

### Recommendations

1. **Power sequencing**: Ensure the Amiga is powered on before the adapter (or vice versa) - no specific order required, but avoid hot-plugging during operation
2. **Ground connection**: Ensure proper ground connection between Amiga and adapter
3. **Firmware updates**: Keep firmware updated to avoid software bugs that could cause unexpected behavior
4. **Testing**: Test with a non-critical Amiga first if concerned

### Conclusion

The electrical design is **very safe for the Amiga**. The adapter:
- Never drives high voltages
- Limits current through pull-up resistors
- Behaves identically to a physical joystick
- Uses standard digital I/O techniques

The risk of damage to the Amiga is **extremely low** and comparable to using a standard physical joystick.

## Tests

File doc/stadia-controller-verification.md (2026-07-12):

# Stadia Controller – Verification Notes

## Summary

Covers two separate topics:

1. **USB HID report formats** — Amiga vs Atari IKBD parsing (unchanged).
2. **BLE pairing + Amiga quadrature mouse** — July 2026 findings (v2.2.13–v2.2.18). This is the important operational knowledge for Stadia on Pico 2 W.

Related: [`device_troubleshooting.md`](./device_troubleshooting.md) (Stadia section), [`BT_PAIRING_HANDOFF.md`](./BT_PAIRING_HANDOFF.md).

---

## BLE pairing + mouse motion (July 2026)

### Symptom

After a Google Stadia controller pairs (or re-bonds) over BLE, **mouse buttons still work** but **cursor motion dies**. Stadia directions/buttons on Port 2 remain OK. Order often looks like: Stadia first → mouse connects → no movement; or mouse worked alone until Stadia paired.

Core 0 keeps receiving HID motion. The Amiga never sees quadrature edges.

### What DIAG proved (v2.2.16–v2.2.17)

Periodic `[DIAG] Core1 …` lines (Core 0 watchdog) showed:

| Field | Broken | Healthy (v2.2.18+) |
|---|---|---|
| `hb` | Climbing | Climbing |
| `paused` / `bt_depth` | `0` | `0` |
| `port1` | `MOUSE` | `MOUSE` |
| `motion_feeds` | Rising with movement | Rising |
| `consumed` | **Stuck at 0** | Tracks `motion_feeds` |
| `quad_gpio` | **Stuck at 0** | Rising |
| `flag` | Stuck `1` | Clears to `0` between moves |
| `period` | (added in v2.2.18) | Climbing even at idle |

So Core 1 was **alive** and Core 0 was **feeding** motion, but Core 1 never entered the path that clears `motion_flag` and drives Port 1 quadrature GPIOs.

### Root cause (Amiga-specific)

Motion consume + quad GPIO updates were gated on:

```c
if (absolute_time_diff_us(last_update, current_time) >= update_period_us) {
    // consume motion_flag, update quadrature GPIOs
}
```

After Stadia bond/flash activity (`flash_safe_execute` lockout on Core 1), that **time gate stopped opening** while the loop itself kept running (`busy_wait_us` / heartbeat). Result: `feeds↑`, `consumed=0`, dead cursor.

**Not** the primary cause:

- Rev 6 GPIO pin remap (Port 2 fire/B2/B3) — does not sit on the mouse quadrature path; Rev 5 forced builds still failed the same way.
- Missing `__dmb()` alone — barriers are good hygiene for the Core0↔Core1 handoff, but DIAG showed the timed update block never ran.
- “Stadia report format” — BT path uses Bluepad32; USB report layout is unrelated.

Stadia is a strong **trigger** because its BLE bond/re-encrypt path does more TLV flash work than a typical mouse pair. Mouse-only sessions often never hit the failure.

### Fix (v2.2.18)

In `src/platform/amiga/quad_mouse.c` (`amiga_quad_mouse_motion`):

1. Drive the update period with a **loop counter** (~170 µs via `busy_wait_us(50)` × N), not `get_absolute_time()`.
2. **Consume `motion_flag` immediately** when set (still tick accumulators on the period).
3. Keep `__dmb()` around the `x` / `y` / `motion_flag` handoff.
4. Prefer `busy_wait_us` over `sleep_us` on Core 1 after BT flash activity.

Healthy check: `consumed` ≈ `motion_feeds`, `quad_gpio` rising, `period` climbing, `flag=0` at idle.

### Residual behaviour

During Stadia setup you may still see:

```text
[BT] Core 1 heartbeat stalled … — SEV wake
[BT] Core 1 still stalled — relaunching amiga_quad_mouse_motion
```

Flash lockout can briefly park Core 1; the heartbeat watchdog relaunches it. After v2.2.18, mouse motion recovers. Cleaning that stall is separate from the `consumed=0` bug.

### Correlation with the GPIO branch

The failure was found while bringing up Rev 6 GPIO maps, which made it easy to blame the pin table. The GPIO commit only retargeted `#if HIDPICO_REVISION == 5` → `HIDPICO_REV_ATARI_BOARD` in `quad_mouse.c`. The latent bug was the **absolute_time-gated consume path** under Stadia/flash stress (already fragile after earlier BLE hardening). See also discussion in session notes: pin remap ≠ timer gate failure.

### Quick regression matrix

| Step | Expect |
|---|---|
| Banner `v2.2.18+ (PCB rev 5)` | Correct build |
| Pair Stadia → move sticks/buttons | Port 2 OK |
| Pair BT mouse → move | Cursor moves; DIAG `consumed` rises |
| Pair KB after | Keys OK; mouse still moves |
| Reboot with bonds | Reconnect; mouse still moves |

---

## USB report formats (Amiga vs Atari)

The Amiga Stadia USB implementation was checked against the Atari IKBD build (`ultramegausb-atari-st-rpikbd`). The Amiga code supports **both** report formats used or documented there.

### Atari build behaviour

1. **`stadia_controller.c` (C)**  
   - Uses a 9-byte payload: bytes 0–1 = buttons (16-bit), 2 = d-pad, 3–6 = sticks (Lx, Ly, Rx, Ry), 7–8 = triggers.  
   - **`stadia_process_report()` is never called** anywhere in the Atari tree. This layout is effectively unused for live input.

2. **`HidInput.cpp` (C++)**  
   - Stadia is read in `get_usb_joystick()` from the raw HID buffer using the **stadia-vigem** layout (from the stadia-vigem project).  
   - This is the format actually used for Stadia on Atari.

### Format 1: stadia-vigem (matches Atari `HidInput.cpp`)

- **Report ID:** `0x03` (first byte).
- **Length:** ≥ 11 bytes (1 byte ID + 10 payload).
- **Layout:**
  - Byte 0: `0x03` (header)
  - Byte 1: D-Pad hat (0–7; 8/15 = centre)
  - Byte 2: System buttons (Options, Menu, Stadia, etc.)
  - Byte 3: Face/shoulder (bit 6=A, 5=B, 4=X, 3=Y, 2=LB, 1=RB, 0=LS)
  - Bytes 4–5: Left stick X, Y (0–255, 128 centre)
  - Bytes 6–7: Right stick X, Y
  - Bytes 8–9: Left trigger, Right trigger

### Format 2: 9-byte payload (optional report ID)

- **Report ID:** Optional; if present, first byte is 1–15 (e.g. `0x01`).
- **Length:** ≥ 10 bytes with ID, or ≥ 9 without.
- **Payload (after optional ID):**
  - Bytes 0–1: Buttons (16-bit)
  - Byte 2: D-Pad (0–8; 15 = neutral)
  - Bytes 3–6: Left X, Left Y, Right X, Right Y
  - Bytes 7–8: Left trigger, Right trigger

### Implementation details

- **VID/PID:** `0x18D1` / `0x9400` (same as Atari; Atari uses `STADIA_CONTROLLER` = `0x9400`).
- **Direction:** Same bit layout as Atari: UP=0x01, DOWN=0x02, LEFT=0x04, RIGHT=0x08; d-pad takes priority over left stick.
- **Fire:** A/B/X/Y, R1, R2, or right trigger > 128 (Amiga also uses trigger; Atari uses face + triggers).
- **Deadzone:** 20 (same as Atari).
- **Unmount:** Amiga resets Joystick Port 2; Atari does not have an equivalent unmount handler in the Stadia C code.

### Files compared

| Item | Atari | Amiga |
|---|---|---|
| VID/PID | 0x18D1, 0x9400 | Same |
| Report parsing | vigem in `HidInput.cpp` only  | vigem (0x03) + 9-byte with optional ID |
| `stadia_process_report` | Present but never called | Called from `usb_hid.c`; supports both formats |
| Output | Atari joystick axes/buttons | Amiga Joystick Port 2 (direction + 3 buttons) |
| OLED on mount | Raw hex dump in C; vigem in C++ | `display_show_controller_detected()` |

### USB conclusion

The Amiga USB implementation is aligned with the Atari build by supporting the **stadia-vigem** report format (report ID `0x03`) plus the 9-byte layout, with the same VID/PID, direction encoding, and deadzone.

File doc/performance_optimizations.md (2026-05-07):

# Performance Optimization Recommendations

This document outlines performance issues identified in the codebase and recommended optimizations to improve overall system performance and reduce unnecessary processing.

## Summary of Issues

The main performance bottlenecks are:
1. **Excessive display updates** - Display refreshes triggered on every keystroke
2. **Unnecessary Bluetooth processing** - Bluetooth functions called even when no devices are connected
3. **Always-on mouse-to-joystick conversion** - Joystick conversion runs on every mouse event
4. **No display update throttling** - Immediate display updates without debouncing

---

## 1. Display Update Optimizations

### Issue: Display Updates on Every Keystroke

**Location:** `src/platform/amiga/keyboard_serial_io.c` (lines 116, 127)

**Problem:**
- `dbgcons_amiga_key()` is called on **every** key press and release
- Each call triggers `disp_write()` → `disp_ssd_update()` → full I2C display refresh
- This can happen 100+ times per second during active typing
- I2C display updates are relatively slow (milliseconds) and block processing

**Current Code:**
```c
void amiga_hid_send(uint8_t hidcode, bool up)
{
    // ...
    dbgcons_amiga_key(hidcode, mapHidToAmiga[hidcode], up ? "u" : "d");  // ← Triggers display update
    amiga_send(mapHidToAmiga[hidcode], up);
}
```

**Impact:** High - This is the biggest performance bottleneck during keyboard use.

**Recommendations:**

#### Option A: Throttle Display Updates (Recommended)
- Add a timestamp-based throttling mechanism to limit display updates
- Update display at most once every 50-100ms
- Batch multiple key events into a single display update

#### Option B: Make Display Updates Conditional
- Add a compile-time or runtime flag to disable keyboard display updates
- Keep display updates for device plug/unplug events (less frequent)
- Optionally update display only on modifier key changes or special keys

#### Option C: Lazy Display Updates
- Mark display as "dirty" instead of immediately updating
- Update display in a low-priority background task or when main loop is idle
- Use a flag to indicate display needs refresh

**Implementation Priority:** HIGH - This will have the biggest performance impact.

---

## 2. Bluetooth Processing Optimizations

### Issue: Unnecessary Bluetooth Processing in Main Loop

**Location:** `src/main.c` (lines 76-79)

**Problem:**
- `process_bluepad32_keyboard()` and `process_bluepad32_mouse()` are called **every** iteration of the main loop
- Even when no Bluetooth devices are connected, these functions still execute
- `bluepad32_get_keyboard_count()` and `bluepad32_get_mouse_count()` iterate through arrays on every call

**Current Code:**
```c
while (1) {
    tuh_task();
    amiga_service();
    
#if ENABLE_BLUEPAD32
    bluepad32_poll();
    process_bluepad32_keyboard();  // ← Called every iteration
    process_bluepad32_mouse();     // ← Called every iteration
#endif
}
```

**Impact:** Medium - Wastes CPU cycles when no Bluetooth devices are connected.

**Recommendations:**

#### Option A: Early Return on No Devices (Recommended)
- Check device count before processing
- Skip processing functions if no devices are connected
- Cache device count state to avoid repeated array iterations

**Example:**
```c
#if ENABLE_BLUEPAD32
    bluepad32_poll();
    
    if (bluepad32_get_keyboard_count() > 0) {
        process_bluepad32_keyboard();
    }
    if (bluepad32_get_mouse_count() > 0) {
        process_bluepad32_mouse();
    }
#endif
```

#### Option B: Optimize Count Functions
- Cache device counts and update only on connect/disconnect events
- Return cached value instead of iterating arrays every time

**Implementation Priority:** MEDIUM - Good performance improvement with minimal code changes.

---

## 3. Mouse-to-Joystick Conversion

### Issue: Always-Active Joystick Conversion

**Location:** `src/usb_hid.c` (line 267)

**Problem:**
- `amiga_joystick_port1_set_from_mouse()` is called on **every** mouse event
- This conversion may not always be needed (only when joystick emulation is desired)
- Adds processing overhead to every mouse movement

**Current Code:**
```c
static void handle_event_mouse(...)
{
    // ... mouse button processing ...
    if (report->x || report->y)
        amiga_quad_mouse_set_motion(report->x, report->y);
    
    // Also send mouse input to joystick port 1  ← Always executed
    amiga_joystick_port1_set_from_mouse(report->x, report->y, report->buttons);
}
```

**Impact:** Low-Medium - Processing overhead on every mouse event.

**Recommendations:**

#### Option A: Make Joystick Conversion Optional (Recommended)
- Add a compile-time flag or runtime configuration to enable/disable joystick conversion
- Allow users to disable if joystick emulation is not needed
- Keep default behavior but allow optimization

#### Option B: Optimize Joystick Conversion Logic
- Only process joystick conversion if mouse movement exceeds a threshold
- Skip conversion if no actual mouse movement occurred (only button changes)

**Implementation Priority:** LOW - Useful optimization but less critical than display updates.

---

## 4. Display Update on Plug/Unplug Events

### Issue: Display Updates on Device Events

**Location:** `src/util/debug_cons.c` (lines 82, 102)

**Problem:**
- `dbgcons_print_counters()` is called on every device plug/unplug
- Each call triggers a full display refresh
- Less frequent than keyboard events, but still could be optimized

**Impact:** Low - Device plug/unplug events are infrequent.

**Recommendations:**

#### Option A: Batch Display Updates
- Mark display as dirty and update once per main loop iteration
- Defer display updates until after all processing is complete

#### Option B: Throttle Device Event Display Updates
- Similar to keyboard event throttling, limit updates to once per second

**Implementation Priority:** LOW - Device events are infrequent, optimization impact is minimal.

---

## 5. Additional Optimizations

### A. Main Loop Optimization

**Current:** Tight loop with no delays - CPU runs at 100% even when idle.

**Recommendation:**
- Consider adding a small delay (1-10ms) when no active processing is needed
- Use sleep_us() or sleep_ms() to reduce CPU usage during idle periods
- However, ensure USB and keyboard timing requirements are still met

**Implementation Priority:** LOW - Current approach ensures low-latency input processing.

### B. GPIO Pin State Optimization

**Location:** `src/platform/amiga/joystick_port1.c`

**Issue:** `_aj1_gpio_set()` toggles GPIO direction on every call.

**Recommendation:**
- Only change GPIO direction when switching between input/output modes
- Cache current direction state to avoid unnecessary GPIO configuration calls

**Implementation Priority:** LOW - GPIO operations are fast, optimization impact is minimal.

### C. Memory Allocation in Display Code

**Location:** `src/display/disp_ssd.c`

**Issue:** Display transactions use dynamic memory allocation (malloc/free).

**Recommendation:**
- Consider using a fixed-size transaction buffer pool
- Pre-allocate buffers to avoid malloc/free overhead
- Current implementation already uses a queue, which is good

**Implementation Priority:** LOW - Current implementation is already well-optimized with DMA.

---

## Recommended Implementation Order

1. **HIGH PRIORITY:** Throttle or conditionally disable keyboard display updates (#1)
   - Biggest performance impact
   - Easy to implement
   - No functional changes to input processing

2. **MEDIUM PRIORITY:** Optimize Bluetooth processing (#2)
   - Skip processing when no devices connected
   - Simple early-return checks
   - Good performance improvement

3. **LOW PRIORITY:** Mouse-to-joystick conversion optimization (#3)
   - Make it optional/conditional
   - Useful but less critical

4. **LOW PRIORITY:** Other optimizations (#4, #5)
   - Nice to have but minimal impact

---

## Testing Recommendations

After implementing optimizations:

1. **Measure Keyboard Latency:**
   - Ensure display update throttling doesn't affect keyboard response time
   - Keyboard input processing should remain unaffected

2. **Test Bluetooth Functionality:**
   - Verify Bluetooth devices still connect and function correctly
   - Ensure early-return optimizations don't break device detection

3. **Monitor CPU Usage:**
   - Compare CPU usage before and after optimizations
   - Verify main loop doesn't become too slow with delays

4. **Display Update Frequency:**
   - Verify display still updates appropriately (not too slow)
   - Ensure user feedback is still responsive

---

## Notes

- **Debug vs Release Builds:** Consider making some optimizations conditional based on `DEBUG_MESSAGES` flag
- **Display Updates:** The display is primarily for debugging. If display updates are causing performance issues, consider making them optional in release builds
- **Backward Compatibility:** Ensure optimizations don't break existing functionality
- **Code Readability:** Maintain code clarity while optimizing - avoid premature optimizations that harm maintainability

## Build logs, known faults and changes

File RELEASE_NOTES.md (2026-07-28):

# Release notes

Firmware version source of truth: `SOFTWARE_VERSION_*` in [`src/config.h`](./src/config.h).

## v4.2.0

* Host Mode Port 2 Atari two-button stick → USB HID gamepad (dedicated HID interface; dirs on Axis 0/1 + hat; fire = B0 / button 2 = B1) — validated on Mac and MiSTer

## v4.1.4

* Host Mode Port 2: do not map directions to buttons 12–15 (bit 12 is Mode; was colliding with MiSTer menu/autofire shortcuts)

## v4.1.3

* Host Mode Port 2: directions as digital **Axis 0/1** + hat switch; fire = B0, button 2 = B1

## v4.1.2

* Host Mode: expose Port 2 gamepad on a **second HID interface** (kbd/mouse stay on IF0) so macOS/Chrome Gamepad API can see it

## v4.1.1

* Host Mode: Port 2 Atari-style two-button joystick → USB HID gamepad (dirs + fire + button 2)

## v4.1.0

* Minor bump for release candidate: OLED Settings screen carousel (Clear BT pair, Pair ON/OFF, Host/Device Mode), Device/Host Mode naming, USB role persistence hardened

## v4.0.13

* OLED **Settings** screen carousel page: Clear BT pair (with confirm) and Host/Device Mode toggle; remove Left+Right / Middle+Right hold chords
* PC KBD / Host Mode carousel is Splash ↔ Settings only (Devices / Map Devices hidden)
* Splash titles: **Device Mode** (Amiga adapter) / **Host Mode** (Amiga kbd → PC); Settings defaults to **Back**
* Document screen-carousel UX in `doc/archive/oled-ui-style-guide.md`

## v4.0.12

* OLED: swap Middle/Right GPIOs so Up/Down/# modules map Up=Left, Down=Right, #=Middle (functions unchanged)

## v4.0.11

* Mouse: revert emit-on-pending (v4.0.10); back to period-gated quadrature emit with separate HID consume — preferred after A/B on Ami/Atr Ms

## v4.0.10

* Mouse: restore emit-on-pending (as well as on Amiga/Atari period) so HID bursts can drain faster — A/B for Amiga travel vs Atari edge rate

## v4.0.9

* Atari mouse: raise pulse queue max from 96 → 255 (match jjmz sat-255) so fast flicks drop less travel

## v4.0.8

* Mouse quadrature: fix direction-cancel on partial opposite HID — keep remaining pulses in the original direction (jjmz adapter semantics). Stops fast flicks from tracking then reversing, especially visible in slower Atari emit mode.

## v4.0.7

* Atari mouse: separate HID consume from quadrature emit; drop leftover recirculation (was forcing ~50 µs edges and a long coasting tail → lag/overrun); modest pending clamp (±255) and shorter Atari pulse queue (96)

## v4.0.6

* Atari/Amiga mouse: Core 0 pending X/Y widened to int16 (±1023) so fast HID bursts are not discarded at ±127; excess beyond Core 1’s pulse queue is kept in the backlog

## v4.0.5

* Atari mouse mode: Core 1 quadrature tick uses `ATARI_UPDATE_PERIOD_US` (~450 µs) instead of Amiga ~170 µs — should fix fast-flick “held back” cursor

## v4.0.4

* Splash heading **Controller Mode**; Port 1 above Port 2; labels `1:Ami Ms` / `2:Joy`
* Mouse mode names **Ami Ms** / **Atr Ms**

## v4.0.3

* Port 1 OLED cycle: **Ami Ms → Joy → CD32 → Llama → Atr Ms** (Amiga / Atari mouse in the mode list)
* Port 2 OLED cycle: **Joy ↔ CD32** (label was STD)

## v4.0.2

* Splash home screen shows both ports (`2: CD32` / `1: Mouse`) in large type
* OLED **Right** toggles Port 2 STD ↔ CD32; **Middle + Left** toggles Bluetooth pairing
* Version string moved to splash bottom-right (PAIR hint removed)

## v4.0.1

* Llamatron twin-stick works with Port 2 CD32 enabled (still exclusive with Port 1 CD32)
* In Llamatron + Port 2 CD32, Port 2 gets the full seven-button CD32 map

## v4.0.0

* Public release packaging for [ultrausbt-amiga](https://github.com/trickydee/ultrausbt-amiga)
* EPL-2.0 `LICENSE` + `NOTICE`; ultrausbt copyright; Cursor/LLM credit in Acknowledgements
* Quieter UART by default (boot + device connect kept; controller dump spam gated)
* Docs: public index, `doc/archive/` for historical notes, rewritten README

## v3.2.1

* Caps Lock pulse held ~120 ms so macOS accepts the toggle
* `KEYBOARD_IN_DEBUG` default off

## v3.2.0

* USB device mode: Amiga keyboard + Port 1 mouse → PC as HID
* OLED Middle + Right (2 s) toggles host ↔ device; persisted + reboot → **superseded in v4.0.13** by Settings carousel

## v3.1.0

* Alternate reset: Ctrl + Left Amiga + Backspace
* Core 1 mouse consume safe across Bluetooth flash lockout (Stadia)

## v2.2.x

* Dual Port 1 + Port 2 CD32; Map Devices UI; pairing UX

Earlier history: see git log.

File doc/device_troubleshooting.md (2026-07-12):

# Device Troubleshooting Guide

This document covers troubleshooting fixes for various device compatibility issues encountered during development.

## Table of Contents

1. [DS5 DualSense Pairing Fix for Pico 2 W](#ds5-dualsense-pairing-fix-for-pico-2-w)
2. [Stadia Controller Bluetooth Pairing Issues](#stadia-controller-bluetooth-pairing-issues)
3. [Joystick Port 1 LEFT/RIGHT Movement Fix](#joystick-port-1-leftright-movement-fix)
4. [Keyboard HID debug and custom key remaps](#keyboard-hid-debug-and-custom-key-remaps)
5. [Keyboard reset combos (classic and alternate)](#keyboard-reset-combos-classic-and-alternate)

---

## DS5 DualSense Pairing Fix for Pico 2 W

### Problem Summary

The DualSense 5 (DS5) controller was failing to pair on Pico 2 W (RP2350) but worked correctly on Pico W (RP2040). The failure occurred during Bluetooth authentication, specifically during the SSP (Secure Simple Pairing) process.

### Symptoms
- DS5 discovered and connection initiated
- `HCI_EVENT_LINK_KEY_REQUEST` received
- `L2CAP Connection failed: 0x66` error
- `HCI_EVENT_AUTHENTICATION_COMPLETE_EVENT: status=6` (failure)
- Never received `SSP User Confirmation Request`
- Authentication always failed, causing disconnection

### Working vs Failing Behavior

**Pico W (Working):**
- Received `SSP User Confirmation Request with numeric value '798941'`
- Auto-accepted confirmation
- `HCI_EVENT_AUTHENTICATION_COMPLETE_EVENT: status=0` (success)
- L2CAP channels opened successfully
- Device connected and ready

**Pico 2 W (Failing):**
- Never received SSP confirmation request
- Authentication always failed with status=6
- Connection repeatedly attempted and failed

### Root Cause

The issue was **missing flash-safe execution coordination** between Core 0 (Bluetooth) and Core 1 (mouse processing).

#### Why Flash Coordination Matters

1. **DS5 uses SSP (Secure Simple Pairing)** which requires writing link keys to flash memory during pairing
2. **Bluetooth TLV storage** uses flash to persist pairing keys across power cycles
3. **Core 1 (mouse processing)** runs independently and can access flash simultaneously
4. **Without coordination**, Core 1 can freeze or interfere when Core 0 tries to write to flash during pairing
5. This interference causes the SSP authentication process to fail

#### Why It Worked on Pico W But Not Pico 2 W

The issue likely existed on both platforms, but Pico 2 W (RP2350) may have:
- Different flash access timing
- More strict flash access requirements
- Different CYW43 driver behavior
- Timing differences that made the conflict more likely

### Solution

Added `flash_safe_execute_core_init()` to Core 1's entry function to coordinate flash access between cores.

#### Implementation

**File**: `src/platform/amiga/quad_mouse.c`

1. **Added include** (line 23):
   ```c
   #include "pico/flash.h"  // For flash_safe_execute_core_init() - required for Bluetooth flash coordination
   ```

2. **Added flash-safe initialization** at the start of `amiga_quad_mouse_motion()`:
   ```c
   void amiga_quad_mouse_motion()
   {
       // CRITICAL: Initialize flash-safe execution FIRST
       // This allows Core 0 to coordinate with Core 1 when Bluetooth writes to flash (TLV storage)
       // Without this, Core 1 can freeze when Bluetooth tries to access flash during pairing
       // This is required for proper flash coordination, especially for devices requiring SSP (Secure Simple Pairing)
       // Reference: Atari keyboard interface implementation
       flash_safe_execute_core_init();
       
       // ... rest of mouse processing code
   }
   ```

### What This Does

- **Initializes flash-safe execution** on Core 1
- **Allows Core 0 to coordinate** with Core 1 when writing to flash
- **Prevents Core 1 from freezing** during flash writes
- **Enables proper SSP pairing** for devices like DS5 that require flash writes during authentication

### Reference Implementation

This fix was based on the Atari keyboard adapter implementation:
- **Location**: `/Users/rich/Documents/Code/Pico/Atari-Keyboard/ultramegausb-atari-st-rpikbd/src/main.cpp`
- **Line 179**: `flash_safe_execute_core_init();` in `core1_entry()`
- **Comment**: "CRITICAL: Initialize flash-safe execution FIRST. This allows Core 0 to coordinate with Core 1 when Bluetooth writes to flash (TLV storage). Without this, Core 1 can freeze when Bluetooth tries to access flash."

### Testing

After implementing this fix:
- DS5 successfully pairs on Pico 2 W
- SSP authentication completes successfully
- Link keys are properly stored in flash
- Device remains connected and functional

### Important Notes for Future Adapter Builds

#### When to Include This Fix

**Always include `flash_safe_execute_core_init()` if:**
- Using Core 1 for any processing (mouse, keyboard, etc.)
- Bluetooth is enabled and uses TLV storage for pairing persistence
- Supporting devices that use SSP (Secure Simple Pairing)
- Building for Pico 2 W (RP2350) or Pico W (RP2040)

#### Where to Add It

- **Must be called in Core 1's entry function** (the function launched with `multicore_launch_core1()`)
- **Must be called FIRST**, before any other Core 1 initialization
- **Only needs to be called once** at Core 1 startup

#### Related Code

The fix works in conjunction with:
- **Core 1 pause/resume functions** (`amiga_quad_mouse_pause_core1()` / `amiga_quad_mouse_resume_core1()`) - these pause Core 1 during Bluetooth enumeration
- **Bluetooth TLV storage** - uses flash to store pairing keys
- **BTstack configuration** - configured for flash-based TLV storage

### Additional Context

#### Devices Affected

This fix is particularly important for:
- **DualSense 5 (DS5)** - Uses SSP with numeric confirmation
- **Other PlayStation controllers** - May use similar pairing mechanisms
- **Any device requiring SSP** - Secure Simple Pairing requires flash writes

#### Devices Not Affected (by the DS5 SSP flash-init issue alone)

- **Simple keyboards/mice** - Often work without extra SSP coordination (less strict timing)
- **Stadia** - Still needs Core 1 / flash cooperation; see the Stadia section below (different failure mode than DS5 SSP)

---

## Stadia Controller Bluetooth Pairing Issues

**Canonical write-up:** [`stadia-controller-verification.md`](./stadia-controller-verification.md) § *BLE pairing + mouse motion*.  
**Family handoff:** [`BT_PAIRING_HANDOFF.md`](./BT_PAIRING_HANDOFF.md).

### Problem Summary

Stadia BLE pairing has gone through several failure modes on this dual-core Pico 2 W adapter:

1. **Early:** full hangs during GATT / bond (flash vs Core 1 XIP).
2. **Mid:** pause/refcount mistakes (Core 1 stuck paused after failed reconnect).
3. **July 2026 (v2.2.13–v2.2.17):** Stadia pairs and Port 2 works; **mouse buttons work**; **cursor motion dead**. Core 1 heartbeat still climbing.

### Latest smoking gun (v2.2.16–v2.2.17 DIAG)

```text
motion_feeds↑  consumed=0  quad_gpio=0  flag=1  hb↑  paused=0  port1=MOUSE
```

Core 0 was posting motion; Core 1 never consumed it or drove quadrature GPIOs.

### Root Cause (confirmed)

Motion consume + quad GPIO updates in `amiga_quad_mouse_motion()` were gated on `absolute_time_diff_us(...) >= update_period_us`. After Stadia bond / `flash_safe_execute` lockout, that **time gate stopped opening** while the Core 1 loop kept running. Stadia is a strong trigger because its bond/re-encrypt path does more TLV flash work than a typical mouse pair.

**Not** the cause of the `consumed=0` failure:

- Rev 6 GPIO pin remap (orthogonal; Rev 5 builds failed the same way).
- USB Stadia report-format parsing (BLE path is Bluepad32).
- Memory barriers alone (hygiene; DIAG showed the timed block never ran).

Earlier pause/resume / `flash_safe_execute_core_init()` work remains necessary for hang avoidance, but was **not sufficient** for this motion-dead mode.

### Fix (v2.2.18)

**File:** `src/platform/amiga/quad_mouse.c`

- Period from a **loop counter**, not `get_absolute_time()`.
- Consume `motion_flag` as soon as it is set; keep period ticks for the quadrature state machine.
- `__dmb()` on the Core0↔Core1 motion handoff.
- Prefer `busy_wait_us` over `sleep_us` on Core 1 after BT flash activity.

Healthy DIAG: `consumed` tracks `motion_feeds`, `quad_gpio` rises, `period` climbs, `flag=0` at idle.

### Supporting mitigations (still relevant)

These reduce hangs / pause stacking; they do not replace the v2.2.18 consume-path fix:

| Mitigation | Role |
|---|---|
| `flash_safe_execute_core_init()` on Core 1 entry | Required for TLV/bond flash |
| Refcounted BT pause + force-release / watchdog | Avoid stuck `paused` after failed reconnect |
| Optional skip of discovery pause for some gamepads | A/B; not the `consumed=0` fix |
| Heartbeat stall → SEV / relaunch | Recovers brief Core 1 park during bond |
| Defer heavy OLED work during enumerate | Reduces interference; not root cause |

### Devices / notes

- **Stadia** (`0x18D1` / `0x9400`) — strongest trigger seen for motion-dead after pair.
- **Xbox Wireless** — same general BT/flash class; retest after Core 1 changes.
- Brief `[BT] Core 1 heartbeat stalled … relaunching` during Stadia setup can still appear; mouse should recover after v2.2.18.

---

## Joystick Port 1 LEFT/RIGHT Movement Fix

### Problem Summary

Joystick Port 1 LEFT and RIGHT directions were not working when in joystick mode. UP, DOWN, and FIRE worked correctly, but LEFT/RIGHT had no effect. Additionally, pressing Button 2 (Circle) and Button 3 (Square) on gamepads was triggering LEFT/RIGHT movements instead of button presses.

### Symptoms

1. **LEFT/RIGHT not working**: Joystick stick LEFT/RIGHT had no effect on Amiga
2. **Button confusion**: Circle button (Button 2) triggered LEFT movement
3. **Button confusion**: Square button (Button 3) triggered RIGHT movement
4. **Intermittent behavior**: Sometimes LEFT/RIGHT would work briefly, then stop

### Root Cause

Multiple issues were causing the problem:

#### Issue 1: GPIO Direction Cache Problem

The GPIO direction cache was preventing correct direction setting:
- `amiga_gpio_set_active_low()` only set GPIO direction if cache indicated it needed changing
- Mouse code on Core 1 could change GPIO direction
- Cache would be out of sync with actual hardware state
- Joystick code would skip setting direction, leaving GPIO in wrong state

#### Issue 2: Cross-Core Race Condition

Mouse quadrature code (Core 1) was overwriting joystick GPIOs (Core 0):
- Core 0 sets LEFT/RIGHT GPIO to OUTPUT and LOW
- Core 1 checks joystick mode (may read stale value due to cache)
- Core 1 updates GPIO, overwriting Core 0's setting
- Result: LEFT/RIGHT direction lost

#### Issue 3: Button GPIO Conflicts

Button 2 and Button 3 shared GPIOs with LEFT/RIGHT directions:
- `QM1_AMIGA_B2 = GPIO 12` (same as LEFT direction `QM1_AMIGA_VQ`)
- `QM1_AMIGA_B3 = GPIO 13` (same as RIGHT direction `QM1_AMIGA_HQ`)
- Pressing Button 2 set GPIO 12 LOW = LEFT direction active
- Pressing Button 3 set GPIO 13 LOW = RIGHT direction active

### Solution

Implemented a multi-part fix addressing all three issues.

#### Fix 1: Always Set GPIO Direction

**File**: `src/platform/common/gpio_util.c`

```c
void amiga_gpio_set_active_low(uint32_t gpio, bool active)
{
    if (active) {
        // Always set direction to OUTPUT FIRST, then set level
        // This ensures the GPIO is in the correct state even if mouse code changed it
        gpio_set_dir(gpio, GPIO_OUT);
        __sync_synchronize();  // Memory barrier for cross-core visibility
        gpio_put(gpio, 0);
        gpio_dir_cache |= (1U << gpio);
    } else {
        // Always set direction to INPUT FIRST
        gpio_set_dir(gpio, GPIO_IN);
        __sync_synchronize();  // Memory barrier for cross-core visibility
        gpio_dir_cache &= ~(1U << gpio);
    }
}
```

**Key Change**: Always set GPIO direction regardless of cache state.

#### Fix 2: Memory Barriers for Cross-Core Synchronization

**File**: `src/platform/amiga/joystick_port1.c`

```c
if (dir_left != prev_dir_left) {
    // Use memory barrier before setting GPIO to ensure Core 1 sees joystick mode change
    __sync_synchronize();
    amiga_gpio_set_active_low(QM1_AMIGA_VQ, dir_left);  // VQ pin = LEFT (GPIO 12)
    __sync_synchronize();
    prev_dir_left = dir_left;
}
```

**File**: `src/platform/amiga/quad_mouse.c`

```c
// Use memory barrier to ensure we see the latest joystick mode state
__sync_synchronize();
bool joy_mode = amiga_joystick_port1_is_joystick_mode();
__sync_synchronize();
if (!joy_mode) {
    // Only update GPIOs if not in joystick mode
    // ...
}
```

**Key Change**: Added memory barriers to ensure Core 1 sees joystick mode changes before GPIO updates.

#### Fix 3: Disable Button 2/3 in Joystick Mode

**File**: `src/platform/amiga/joystick_port1.c`

```c
void amiga_joystick_port1_set_button(enum amiga_joystick_port1_buttons button, bool pressed)
{
    switch (button) {
        case AJ1_FIRE:
            amiga_gpio_set_active_low(QM1_AMIGA_B1, pressed);
            break;
        case AJ1_BUTTON2:
            // Button 2 uses GPIO 12, which is the same as LEFT direction (QM1_AMIGA_VQ)
            // In joystick mode, we can't use Button 2 because it conflicts with LEFT direction
            // Only set Button 2 if NOT in joystick mode (when port 1 is in mouse mode)
            if (!port1_joystick_mode) {
                amiga_gpio_set_active_low(QM1_AMIGA_B2, pressed);
            }
            // Otherwise, ignore Button 2 to prevent conflict with LEFT direction
            break;
        case AJ1_BUTTON3:
            // Button 3 uses GPIO 13, which is the same as RIGHT direction (QM1_AMIGA_HQ)
            // In joystick mode, we can't use Button 3 because it conflicts with RIGHT direction
            // Only set Button 3 if NOT in joystick mode (when port 1 is in mouse mode)
            if (!port1_joystick_mode) {
                amiga_gpio_set_active_low(QM1_AMIGA_B3, pressed);
            }
            // Otherwise, ignore Button 3 to prevent conflict with RIGHT direction
            break;
    }
}
```

**Key Change**: Disable Button 2/3 when joystick mode is active to prevent GPIO conflicts.

### GPIO Pin Mapping (Revision 5)

For reference, the GPIO pin assignments are:
- **UP**: GPIO 10 (`QM1_AMIGA_V`)
- **DOWN**: GPIO 11 (`QM1_AMIGA_H`)
- **LEFT**: GPIO 12 (`QM1_AMIGA_VQ`) - **CONFLICTS with Button 2**
- **RIGHT**: GPIO 13 (`QM1_AMIGA_HQ`) - **CONFLICTS with Button 3**
- **FIRE**: GPIO 14 (`QM1_AMIGA_B1`)
- **Button 2**: GPIO 12 - **SAME as LEFT** (disabled in joystick mode)
- **Button 3**: GPIO 13 - **SAME as RIGHT** (disabled in joystick mode)

### Testing

After implementing these fixes:
- LEFT/RIGHT joystick movement works correctly
- Button 2/3 no longer trigger LEFT/RIGHT movements
- No more intermittent behavior
- All directions (UP, DOWN, LEFT, RIGHT) work consistently

### Important Notes

#### Hardware Limitation

Button 2 and Button 3 are currently disabled in joystick mode due to GPIO conflicts. The config comments note: "will be remapped in hardware" - this is a known limitation that requires hardware changes to fully resolve.

#### Memory Barrier Importance

The `__sync_synchronize()` calls are critical for cross-core synchronization:
- Without them, Core 1 may not see joystick mode changes
- This causes mouse code to overwrite joystick GPIOs
- Results in LEFT/RIGHT not working

#### GPIO Direction Setting

Always setting GPIO direction (regardless of cache) ensures:
- GPIO is in correct state even if mouse code changed it
- No dependency on cache state
- Reliable operation across core boundaries

### Future Improvements

1. **Hardware Remapping**: Remap Button 2/3 to different GPIOs to eliminate conflicts
2. **GPIO Arbitration**: Implement proper GPIO ownership tracking between cores
3. **Cache Invalidation**: Clear GPIO cache when switching between mouse/joystick modes

---

## Button 2/3 Voltage Levels - Amiga Model Compatibility

### Problem Summary

Buttons 2 and 3 on both joystick ports show higher voltage levels (400-500mV) when pressed compared to other buttons (50-80mV). This causes buttons 2 and 3 to not work on some Amiga models, while working correctly on others.

### Symptoms

1. **Voltage Measurements**:
   - Normal buttons (UP/DOWN/LEFT/RIGHT/FIRE): 5V → 50-80mV when pressed
   - Buttons 2 and 3: 5V → 400-500mV when pressed
   
2. **Amiga Model Differences**:
   - **A2000**: Buttons 2 and 3 work correctly with 500mV
   - **Other Amiga models** (A500, A600, A1200, etc.): Buttons 2 and 3 don't work with 500mV

3. **Consistent Across Hardware**:
   - Same voltage levels on different Pico boards (RP2040, RP2350)
   - Voltage levels tested on both GPIO 27 (current) and GPIO 7 (temporarily used during debugging)
   - LED test shows GPIOs are working correctly

### Root Cause

This is **NOT a firmware or Pico issue** - it's an **Amiga model compatibility difference**:

1. **Different Pull-up Resistor Values**: Different Amiga models use different pull-up resistor values on joystick port pins
2. **Different Input Buffer Thresholds**: Different Amiga models have different voltage thresholds for recognizing LOW signals
3. **Different Input Impedance**: Different loading characteristics on different Amiga models

The firmware is working correctly - it's driving the GPIOs LOW properly. The voltage difference is due to:
- **Amiga's internal pull-up resistors** pulling the line higher
- **Level shifter characteristics** (if using level shifters)
- **Amiga input buffer characteristics** varying by model

### Why A2000 Works But Others Don't

The A2000 likely has:
- **Stronger pull-up resistors** that are easier to overcome
- **More tolerant input buffers** that accept higher voltages as LOW
- **Different input impedance** that allows the Pico to pull the line lower

Other Amiga models (A500, A600, A1200) likely have:
- **Stricter voltage thresholds** requiring <100mV for LOW
- **Different pull-up values** that create the 400-500mV level
- **More sensitive input buffers** that don't recognize 500mV as LOW

### Solution

This is a **hardware compatibility limitation**, not a firmware bug. The firmware is working correctly.

#### Options for Affected Amiga Models

**Important Note**: The issue is NOT about pull-down resistors. The Amiga's pull-ups are pulling HIGH, and we need the level shifter to SINK more current when driving LOW.

1. **Hardware Solution**: Use a level shifter with higher current sinking capability
   - The TXB0108 can sink ~24mA per channel
   - Some Amiga models may have stronger pull-ups that require more current to overcome
   - Consider using a level shifter with higher current rating (e.g., SN74LVC8T245 can sink 32mA)

2. **Hardware Solution**: Use a different level shifter design (e.g., BSS138 MOSFETs instead of TXB0108)
   - The original amigahid-pico design uses BSS138 MOSFETs with 10kΩ pull-ups on both sides
   - This design has proven reliable and works with all Amiga models
   - BSS138 MOSFETs can sink more current than TXB0108

3. **Hardware Solution**: Add buffer/driver ICs to increase drive strength on buttons 2 and 3
   - Use a dedicated buffer IC (e.g., 74LVC1G07) that can sink more current
   - Place buffer between level shifter and Amiga for buttons 2/3 only
   - This increases current sinking capability without affecting other signals

4. **Hardware Solution**: Use stronger pull-up resistors on the 3.3V side (if using TXB0108)
   - The TXB0108 requires pull-ups on BOTH sides for proper operation
   - Stronger pull-ups on the 3.3V side can help the level shifter detect direction better
   - But this doesn't directly solve the current sinking issue

5. **Accept Limitation**: Buttons 2 and 3 may not work on all Amiga models due to voltage threshold differences
   - This is a known hardware compatibility limitation
   - The firmware is working correctly
   - Some Amiga models simply have stricter voltage thresholds

#### Why Pull-Down Resistors Won't Help

**Pull-down resistors would make things WORSE**, not better:
- When signal should be HIGH (inactive): Amiga's pull-up pulls to 5V, but pull-down would fight it, creating a voltage divider
- When signal should be LOW (active): Pico drives LOW, but pull-down would add unnecessary current draw
- The real issue is that the level shifter can't SINK enough current to overcome the Amiga's pull-up when driving LOW

#### Ground Connection Issues (CRITICAL!)

**If you have grounds connected in SERIES (daisy-chained) across multiple level shifters, this is likely contributing to the problem!**

**Why Series Grounds Cause Issues:**

1. **Voltage Drop Across Ground Resistance**:
   - Each connection in a series ground path adds resistance (wire resistance, connector resistance, etc.)
   - When the level shifter tries to sink current to drive LOW, current flows: `Amiga → Level Shifter → Ground Path → Pico GND`
   - If the ground path has resistance (R), the voltage drop is: `V_drop = I_sink × R`
   - This voltage drop prevents the signal from going fully LOW
   - **Example**: If ground path has 1Ω resistance and level shifter sinks 20mA, voltage drop = 20mV
   - With multiple level shifters in series, resistance adds up, voltage drop increases

2. **Current Return Path Problems**:
   - When multiple signals try to sink current simultaneously, they all share the same series ground path
   - This increases the current through the ground path, increasing voltage drop
   - **Buttons 2/3 might be affected more** if they're at the end of the series chain

3. **Ground Loop and Noise**:
   - Series grounds can create ground loops
   - Different ground potentials at different points in the chain
   - Can cause noise and signal integrity issues

**Solution: Star Grounding**

**All grounds should connect to a COMMON POINT (star grounding), not in series:**

```
❌ BAD (Series/Daisy-Chain):
Pico GND → Level Shifter 1 GND → Level Shifter 2 GND → Level Shifter 3 GND → Amiga GND

✅ GOOD (Star Ground):
                    ┌─ Level Shifter 1 GND
                    ├─ Level Shifter 2 GND
Pico GND ──── Common Point ── Level Shifter 3 GND
                    └─ Amiga GND
```

**How to Fix:**

1. **Identify a Common Ground Point**:
   - Use a ground plane on your PCB, or
   - Use a terminal block/ground bus bar, or
   - Use a star point (single connection point where all grounds meet)

2. **Connect All Grounds to the Common Point**:
   - Pico GND → Common Point (use multiple Pico GND pins if available!)
   - Level Shifter 1 GND (3.3V side) → Common Point
   - Level Shifter 1 GND (5V side) → Common Point
   - Level Shifter 2 GND (3.3V side) → Common Point
   - Level Shifter 2 GND (5V side) → Common Point
   - Amiga GND → Common Point
   - **Each connection should be a separate wire/trace to the common point**

3. **Use Thicker Wires/Traces**:
   - Lower resistance = lower voltage drop
   - For high-current signals (like buttons 2/3), use thicker ground connections

4. **Multiple Ground Points on Pico**:
   - **YES, connecting multiple Pico GND pins to the common point WILL help!**
   - Pico has multiple GND pins - use them all!
   - This reduces resistance and provides multiple current return paths
   - Each additional GND connection reduces the overall ground path resistance

**Expected Improvement:**

- **Reduced ground resistance**: Star grounding eliminates series resistance
- **Lower voltage drop**: No voltage drop across ground path when sinking current
- **Better signal integrity**: All signals see the same ground potential
- **Buttons 2/3 should work better**: Lower ground resistance = better current sinking = lower voltage when driving LOW

**Testing:**

After switching to star grounding, measure:
- Ground path resistance (should be <0.1Ω ideally)
- Voltage at buttons 2/3 when pressed (should be closer to 50-80mV, not 400-500mV)
- Voltage drop across ground connections (should be <10mV)

#### What Actually Happens

1. **Inactive (HIGH)**: 
   - Amiga's pull-up (~10kΩ) pulls line to 5V
   - Pico sets GPIO to INPUT (high-impedance)
   - Level shifter translates 5V HIGH to 3.3V HIGH
   - ✅ Works correctly

2. **Active (LOW)**:
   - Pico drives GPIO LOW (0V) as OUTPUT
   - Level shifter should translate 3.3V LOW to 0V on 5V side
   - **Problem**: Amiga's pull-up (~10kΩ) is trying to pull to 5V
   - Level shifter must SINK current to overcome the pull-up
   - If level shifter can't sink enough current, voltage stays at 400-500mV instead of <100mV
   - ❌ Some Amiga models don't recognize 500mV as LOW

#### Firmware Status

The firmware is **working correctly**:
- GPIOs are being driven LOW properly
- LED test confirms GPIOs are working
- A2000 works perfectly with 500mV
- The issue is Amiga model-specific voltage threshold differences

### Testing Results

- **Pico GPIO Output**: Confirmed working (LED test)
- **Voltage Levels**: Consistent across different Pico boards
- **A2000 Compatibility**: Works with 500mV
- **Other Amiga Models**: May require <100mV (hardware limitation)

### Important Notes

#### This is NOT a Bug

The firmware is functioning correctly. The voltage difference is due to:
- Amiga hardware differences (pull-up values, input thresholds)
- Level shifter characteristics (if used)
- Normal variation between Amiga models

#### Known Working Models

- **A2000**: Works with 500mV (confirmed)
- **Other models**: May require hardware modifications

#### Future Hardware Improvements

For future adapter designs, consider:
- Stronger pull-down resistors on button 2/3 lines
- Different level shifter design for buttons 2/3
- Buffer/driver ICs for increased drive strength
- Separate level shifter channels for buttons 2/3 with different characteristics

---

## Keyboard HID debug and custom key remaps

Use this when a USB/Bluetooth key does not map to the Amiga key you expect (e.g. remapping a Logitech key to numpad `*` / Print Screen).

### Enable UART keystroke logging

In `src/config.h`:

```c
#define KEYBOARD_HID_DEBUG  1
```

Rebuild and flash. Connect a serial monitor to the Pico UART (115200 8N1). Each key **press** logs:

```text
[kbd] HID 0x32 -> Amiga 0x35
```

The second value is the **default** table lookup; remapped keys still send the remap target (see below).

Set back to `0` for normal use (default in release builds).

### Custom remap (one HID code → Amiga numpad *)

```c
#define KEY_REMAP_HID_TO_HELP  0x32   // HID code from debug log; 0 = disable
```

Sends **`AMIGA_KPAST` (`0x5d`)** — Amiga numpad `*` / Print Screen — when that HID code is pressed. Implemented in `amiga_hid_send()` in `keyboard_serial_io.c`. Applies to USB and Bluetooth keyboards.

---

## Keyboard reset combos (classic and alternate)

The adapter emulates the Amiga keyboard hard-reset (Ctrl-Amiga-Amiga). Two combos are recognised on USB **and** Bluetooth keyboards:

| Combo | Notes |
|---|---|
| **Ctrl + Left Amiga + Right Amiga** | Classic Amiga reset. Requires a keyboard with a Right Amiga / Right GUI (Right Windows / Right Command) key. |
| **Ctrl + Left Amiga + Backspace** | Alternate reset for keyboards **without** a Right Amiga key (e.g. Logitech MX Keys Mini). |

Left Amiga = Left GUI (Left Windows / Left Command).

### How the reset is signalled

The reset is asserted the way a real Amiga keyboard MCU does it: by **holding the keyboard CLOCK (`KCLK`) line LOW** (the "hard reset warning"), rather than relying only on the dedicated `/KBRST` line (which is not wired on every board). Both are driven for maximum compatibility. See `amiga_assert_reset()` / `amiga_release_reset()` in `src/platform/amiga/keyboard_serial_io.c`.

Key points implemented for reliability:

- **Minimum hold time** (`RESET_ASSERT_MIN_HOLD_MS`, default 500 ms in `config.h`). Many keyboards **ghost** — they drop a combo key from the HID report the instant a third key is added (the MX Keys Mini drops Backspace). Without a guaranteed hold, the reset pulse would be too short for the Amiga to latch. The assert blocks for this minimum on purpose (we are deliberately resetting the machine).
- **No key bit-banging while `in_reset`.** Pulsing `/clk` to send scancodes during a reset breaks the held handshake, so the transmit loop is skipped while reset is asserted (matches borb/amigahid-pico c638207, "fix held ctrl-amiga-amiga").

### Debugging the combo

Enable the reset state-machine log in `src/config.h`:

```c
#define KEYBOARD_RESET_DEBUG  1
```

Each tracked key change logs the combo state, e.g.:

```text
[reset] key=0x66 down | ctrl=1 lamiga=1 ramiga=0 bksp=1 | combo=1 in_reset=0
[reset] *** ASSERT reset ***
```

Set back to `0` for normal use (default in release builds).

---

## Summary

These fixes address critical device compatibility issues:

1. **DS5 Pairing**: Flash-safe execution coordination for SSP pairing
2. **Stadia / BLE gamepad + mouse**: Core 1 must survive bond/flash lockout; Amiga v2.2.18 stops gating quadrature consume on `absolute_time` (see [`stadia-controller-verification.md`](./stadia-controller-verification.md))
3. **Joystick LEFT/RIGHT**: GPIO direction fixes, memory barriers, and button conflict resolution
4. **Button 2/3 Voltage**: Amiga model compatibility difference (not a firmware bug)

Cross-core flash coordination and Core 1 timing that does not depend on fragile `absolute_time` gates are both required for reliable Pico 2 W + Bluepad32 operation.

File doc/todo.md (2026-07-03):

# TODO - Outstanding Work

> **Active branch:** `feature/cd32` — CD32 gamepad support. Start: [`doc/CD32_BUILD_SPEC.md`](./CD32_BUILD_SPEC.md) + [`doc/future_work.md`](./future_work.md) § P1 CD32.

This document tracks outstanding tasks and improvements for the amigahid-pico project.

## UI alignment (feature/ui-alignment branch)

### Done (v2.1.1)
- [x] Map Devices screen with USB + BT names (`usb_device_map`, `display_show_map_devices`)
- [x] Build-all.sh / dist/ layout aligned with Atari adapter
- [x] README build section; removed `installation.md` and µgui note

### Deferred
- [ ] Atari-style **cycle gamepad bindings** on Map Devices (see Atari `docs/UI_UNIFICATION.md` Phase 2)
- [ ] Cleanup review §5–§7 (debug_cons trim, doc consolidation, rev 2/4 removal) — user deferred

## CD32 controller support (`feature/cd32`)

> **Build spec:** [`doc/CD32_BUILD_SPEC.md`](./CD32_BUILD_SPEC.md)

- [x] Phase 0: Port 2 GPIO ↔ DB-9 CD32 pins (PSCD32 / KTRL reference)
- [x] Phase 1: `cd32_pad.c` + ISRs; `port2_gamepad.c`; BT + PS4/Xbox/Stadia routing
- [x] Phase 2 (partial): OLED `Port2: CD32/STD`; **Shift + Left Amiga + C** toggle (USB + BT); Llamatron mutual exclusion
- [x] Phase 2 (partial): flash persist for Port 1 mode + Port 2 CD32
- [x] Phase 4 (partial): Port 1 CD32 + OLED 4-state cycle; BT pad #2; dual simultaneous CD32 (v2.2.1)
- [x] Phase 4 (partial): ISR starvation fix + `cd32_service()` deferral (v2.2.2)
- [ ] **CD32 shift-register timing** — ghost adjacent buttons (B+A, Y+G); see [`doc/future_work.md`](./future_work.md)
- [ ] **BT gamepad slot routing** — disconnect/reconnect order breaks Port 1/2 mapping; see [`doc/future_work.md`](./future_work.md)
- [ ] **UART log corruption** — garbled serial under load; serialize logging / suppress Bluepad32 mouse vendor-page spam; see [`doc/future_work.md`](./future_work.md)
- [ ] Phase 4 (remaining): USB pad → Port 1 CD32 routing

## Bluetooth pairing (Atari v22.1.0 alignment)

> **Start here:** [`doc/future_work.md`](./future_work.md) § P1 — Bluetooth pairing alignment.  
> **Full technical context:** [`doc/BT_PAIRING_HANDOFF.md`](./BT_PAIRING_HANDOFF.md).

- [ ] Port refcounted Core 1 pause + `__wfe()` from Atari `main.cpp` → `quad_mouse.c`
- [ ] Fix `bluepad32_platform.c` (no `sleep_ms` in callbacks; no double-pause on connect; settle/resume delays)
- [ ] Audit `mouse_config.c` flash sector vs BTstack TLV overlap
- [ ] Hardware matrix: BT KB + mouse + gamepad pair on Pico 2 W

## License Compliance

### High Priority
- [ ] **Add EPL-2.0 license headers to new source files**
  - [ ] `src/display/display.c` - Add EPL-2.0 header
  - [ ] `src/display/display.h` - Add EPL-2.0 header
  - [ ] `src/bluepad32_init.c` - Add EPL-2.0 header
  - [ ] `src/bluepad32_init.h` - Add EPL-2.0 header
  - [ ] `src/bluepad32_platform.c` - Add EPL-2.0 header
  - [ ] `src/bluepad32_platform.h` - Add EPL-2.0 header
  - [ ] `src/btstack_config.h` - Add EPL-2.0 header (or proprietary header)
  - [ ] `src/sdkconfig.h` - Add EPL-2.0 header (or proprietary header)
  
- [ ] **Determine license for SSD1306 library** (copied from Atari project)
  - [ ] Check Atari project license for `ssd1306/` files
  - [ ] Add appropriate license headers to SSD1306 files
  
- [ ] **Create LICENSE file** in project root
  - [ ] Include EPL-2.0 license text
  - [ ] Document which files are under which license
  - [ ] List third-party licenses (Bluepad32, TinyUSB, Pico SDK, etc.)

- [ ] **Update README.md with license information**
  - [ ] Document license obligations
  - [ ] Explain what code must be made available
  - [ ] Link to license analysis document

**Reference**: See `doc/license_analysis.md` for detailed analysis

## Atari Mouse Support Integration

### High Priority
- [ ] **Merge Atari mouse support from `atari-mouse-support` branch**
  - [ ] **Add mouse type enum to `quad_mouse.h`**:
    ```c
    typedef enum {
        MOUSE_TYPE_AMIGA = 0,
        MOUSE_TYPE_ATARI = 1
    } mouse_type_t;
    ```
  
  - [ ] **Add mouse type functions to `quad_mouse.h`**:
    - [ ] `void amiga_quad_mouse_set_type(mouse_type_t type);`
    - [ ] `mouse_type_t amiga_quad_mouse_get_type(void);`
    - [ ] `void amiga_quad_mouse_toggle_type(void);`
  
  - [ ] **Implement GPIO pin swapping in `quad_mouse.c`**:
    - [ ] Add `volatile mouse_type_t g_mouse_type = MOUSE_TYPE_AMIGA;` global variable
    - [ ] Add `get_gpio_v()` function: Returns `QM1_AMIGA_HQ` for Atari, `QM1_AMIGA_V` for Amiga
    - [ ] Add `get_gpio_hq()` function: Returns `QM1_AMIGA_V` for Atari, `QM1_AMIGA_HQ` for Amiga
    - [ ] Update `amiga_quad_mouse_motion()` to use `get_gpio_v()` and `get_gpio_hq()` instead of direct GPIO constants
    - [ ] Add memory barriers (`__sync_synchronize()`) around mouse type reads for cross-core safety
    - [ ] **GPIO Swap Details**:
      - **Amiga Mode (default)**: 
        - V (vertical) → DB-9 Pin 1 (GPIO 10)
        - HQ (horizontal quadrature) → DB-9 Pin 4 (GPIO 13)
      - **Atari Mode**:
        - V and HQ are swapped: V → DB-9 Pin 4, HQ → DB-9 Pin 1
        - This swaps the X and Y axes to match Atari ST/TT mouse pinout
  
  - [ ] **Add mouse type toggle to display**:
    - [ ] In `display_show_devices()`, show mouse type when Port 1 is in mouse mode:
      ```c
      if (!is_joy_mode) {
          mouse_type_t mouse_type = amiga_quad_mouse_get_type();
          sprintf(buf, "Mouse: %s", mouse_type == MOUSE_TYPE_ATARI ? "Atari" : "Amiga");
          ssd1306_draw_string(&disp, 0, 36, 1, buf);
      }
      ```
    - [ ] Add RIGHT button handler on DEVICES screen to toggle mouse type:
      ```c
      if (current_screen == DISPLAY_SCREEN_DEVICES) {
          amiga_quad_mouse_toggle_type();
          display_show_devices();  // Refresh to show new type
      }
      ```
  
  - [ ] **Remove debug code from atari-mouse-support branch**:
    - [ ] Remove `printf("[MOUSE_BTN]...")` debug logging from `amiga_quad_mouse_button()`
    - [ ] Remove any other debug code added for hardware troubleshooting (user confirmed issues were hardware-related)

**Reference**: Changes are in `atari-mouse-support` branch. The GPIO swap swaps DB-9 pins 1 and 4 (V and HQ signals) to support Atari ST/TT mice which have different pinout than Amiga mice.

## Code Quality & Maintenance

### Medium Priority
- [ ] **Remove unused variables** (compiler warnings)
  - [ ] `src/display/display.c` - Remove unused `mode_line`, `mode_buf` variables
  - [ ] `src/display/display.c` - Remove unused `name`, `buf` variables in `display_show_bt_names()`

- [ ] **Code cleanup**
  - [ ] Review and remove any remaining debug code
  - [ ] Standardize code formatting
  - [ ] Add missing function documentation comments

## Testing & Validation

### Medium Priority
- [ ] **Hardware testing**
  - [ ] Test GPIO 26 (fire button) on second Pico W board
  - [ ] Verify all GPIO remappings work correctly (GPIOs 2, 3, 27, 28)
  - [ ] Test Atari mouse mode on actual Atari hardware
  - [ ] Verify all joystick buttons work correctly on both ports

- [ ] **Bluetooth testing**
  - [ ] Test mode display shows "USB+BT" correctly when Bluetooth is enabled
  - [ ] Verify RST button label appears correctly
  - [ ] Test Bluetooth pairing persistence across power cycles
  - [ ] Verify multi-keyboard support works correctly

- [ ] **Display testing**
  - [ ] Verify splash screen shows "ultramegausb.com" correctly
  - [ ] Test all three display screens (SPLASH, DEVICES, BT_NAMES)
  - [ ] Verify button navigation works correctly
  - [ ] Test device counter updates in real-time

## Documentation

### Low Priority
- [ ] **Update main README.md**
  - [ ] Add information about Atari board compatibility
  - [ ] Document GPIO pin mappings for Revision 5
  - [ ] Add build instructions for all board types
  - [ ] Document new features (Llamatron mode, multi-keyboard, etc.)

- [ ] **Create user guide**
  - [ ] Document how to use Llamatron twinstick mode
  - [ ] Explain how to toggle Port 1 between mouse/joystick
  - [ ] Document Atari mouse mode toggle
  - [ ] Explain Bluetooth pairing and management

- [ ] **Hardware documentation**
  - [ ] Document GPIO pin conflicts that were resolved
  - [x] Create hardware remapping guide for Button 2/3
  - [x] Port 2 Button 2: Currently using GPIO 27 (ADC1). Was temporarily moved to GPIO 7 during debugging but reverted back to GPIO 27.
  - [ ] Document electrical protection requirements (5V back-feeding)

## Future Enhancements

### Low Priority
- [ ] **Hardware protection**
  - [ ] Research level shifters for GPIO protection
  - [ ] Document recommended protection circuits
  - [ ] Add warnings about 5V back-feeding risks

- [ ] **Performance optimizations**
  - [ ] Review GPIO update frequency
  - [ ] Optimize display refresh rate
  - [ ] Reduce memory usage if possible

- [ ] **Feature requests**
  - [ ] Consider additional gamepad button mappings
  - [ ] Support for more Bluetooth device types
  - [ ] Additional display screens/information

## Known Issues

### Resolved (Keep for Reference)
- ✅ GPIO 26 fire button issue on first Pico W (hardware damage from 5V back-feeding)
- ✅ Mode display showing "USB" instead of "USB+BT" (fixed in v1.0.11)
- ✅ Circle button triggering UP movement (fixed with D-pad filter)
- ✅ Square button causing Bluetooth disconnect (fixed with GPIO remapping)
- ✅ Joystick Port 1 LEFT/RIGHT not working (fixed with memory barriers)
- ✅ Stadia controller hangs (fixed with Core 1 pause/resume)
- ✅ DS5 pairing on Pico 2 W (fixed with flash-safe execution)

### Open Issues
- [ ] None currently known

## Version History Tracking

- **v1.0.11** - Fixed mode display, removed debug logging, updated branding
- **v1.0.10** - Removed debug logging, updated splash screen
- **v1.0.9** - Enhanced GPIO initialization safety
- **v1.0.8** - GPIO pull-up fixes, extensive debug logging
- **v1.0.7** - GPIO button remapping (GPIOs 2, 3, 27, 28)
- **v1.0.6** - Atari mouse support
- **v1.0.5** - GPIO conflict fixes
- **v1.0.4** - Bluetooth device names display
- **v1.0.3** - Joystick Port 1 fixes
- **v1.0.2** - Stadia controller fixes
- **v1.0.1** - Multi-keyboard support, Bluetooth persistence
- **v1.0.0** - Initial release with Atari board compatibility

---

**Last Updated**: 2024 (after v1.0.11)
**Next Review**: After license compliance work completed

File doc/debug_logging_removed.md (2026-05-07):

# Debug Logging Added for GPIO and Gamepad Troubleshooting

This document describes the debug logging that was added during troubleshooting of GPIO and gamepad issues, particularly for the fire button (GPIO 26) on Pico W and gamepad button mapping issues.

## Overview

Extensive debug logging was added to diagnose:
1. **GPIO 26 (Fire Button) Issues**: Why the fire button wasn't working on Pico W
2. **Gamepad Button Mapping**: Circle button triggering UP movement, Square button causing Bluetooth disconnects
3. **GPIO State Verification**: Ensuring GPIOs are set correctly and detecting hardware issues

## Debug Logging Locations

### 1. GPIO Utility (`src/platform/common/gpio_util.c`)

**Location**: `amiga_gpio_set_active_low()` function

**Purpose**: Track GPIO 26 (Port 2 Fire button) operations in detail

**Logs Added**:
- **Before Set**: Logs GPIO state before changing it (direction, level, target state)
  ```
  [GPIO-UTIL] GPIO 26 (Fire): before set - dir=INPUT level=1, setting to ACTIVE (OUTPUT/LOW)
  ```

- **After Set**: Logs GPIO state after setting (direction, output register value, actual pin state, expected state)
  ```
  [GPIO-UTIL] GPIO 26 (Fire): after set - dir=OUTPUT gpio_get()=1 pin_hw_state=1 (expected: OUTPUT/0)
  ```

- **Warnings**: 
  - If output register is not set correctly (GPIO is OUTPUT but `gpio_get()` returns 1 instead of 0)
  - If output register is 0 but pin is HIGH (external pull-up or hardware issue)

**What It Diagnosed**:
- Identified that `gpio_put(gpio, 0)` was not successfully setting GPIO 26 to LOW
- Revealed the need to explicitly disable pull-ups before setting to OUTPUT
- Helped identify potential hardware damage from 5V back-feeding

### 2. Joystick Port 2 (`src/platform/amiga/joystick_port2.c`)

**Location**: `amiga_joystick_port2_init()` and `amiga_joystick_port2_set_button()`

**Purpose**: Track fire button initialization and state changes

**Logs Added**:

#### Initialization (`amiga_joystick_port2_init()`):
```
[JOY2-INIT] GPIO 26 (Fire): dir=INPUT level=1 (should be INPUT=0, HIGH=1)
```

#### Fire Button State Changes (`amiga_joystick_port2_set_button()`):
- **Function Call**: Logs when function is called with current and previous state
  ```
  [JOY2-FIRE] Called: pressed=1 prev_button1=0 (GPIO 26)
  ```

- **State Change**: Logs when button state actually changes
  ```
  [JOY2-FIRE] State changed! Setting GPIO 26 to ACTIVE (LOW/OUTPUT)
  ```

- **After Set**: Logs GPIO state after setting and compares with expected state
  ```
  [JOY2-FIRE] After set: GPIO 26 dir=OUTPUT level=1 (expected: pressed=1 -> dir=OUTPUT level=0)
  ```

- **State Unchanged**: Logs when button state hasn't changed (optimization skip)
  ```
  [JOY2-FIRE] State unchanged, skipping GPIO update
  ```

#### Reset Function (`amiga_joystick_port2_reset()`):
```
[JOY2-RESET] prev_button1 before reset: 1
[JOY2-RESET] prev_button1 after reset: 0
```

**What It Diagnosed**:
- Confirmed function was being called correctly
- Verified `prev_button1` state tracking was working
- Identified that GPIO was being set but hardware wasn't responding
- Helped confirm hardware damage on first Pico W

### 3. Gamepad Debug (`src/usb_hid.c`)

**Location**: `process_bluepad32_gamepad()` function

**Purpose**: Track gamepad button states, D-pad, and analog stick values

**Logs Added**:
```
[GAMEPAD-DEBUG] buttons=0x0002 (A=0 B=1 X=0 Y=0) dpad=0x00 axis_x=4 axis_y=-8
```

**What It Logs**:
- `buttons`: Raw button bitmask (0x0001=A, 0x0002=B, 0x0004=X, 0x0008=Y)
- Individual button states: A, B, X, Y (0 or 1)
- `dpad`: D-pad state (0x01=UP, 0x02=DOWN, 0x04=RIGHT, 0x08=LEFT)
- `axis_x`, `axis_y`: Analog stick values (-128 to +127)

**When It Logs**:
- Only when button states or D-pad state changes (to reduce log spam)
- Triggered by comparing `last_buttons` and `last_dpad` with current values

**What It Diagnosed**:
- **Circle Button (B) Issue**: Revealed that when Circle was pressed, `dpad=0x01` (UP) was also reported, causing unintended UP movement
  - Root cause: Bluepad32's `uni_hid_parser_hat_to_dpad` maps hat value `0` (neutral) to `DPAD_UP` per HID standard
  - Fix: Filter out `DPAD_UP` if `BUTTON_B` is also pressed

- **Square Button (X) Issue**: Showed button was being pressed correctly, but caused Bluetooth disconnect
  - Root cause: GPIO conflict (GPIO 18 used by both Button 3 and Display Left Button)
  - Fix: Disabled Button 3 functionality until GPIO remapping

## Debug Logging Impact

### Performance Impact
- **GPIO Logging**: Only logs for GPIO 26 (fire button), minimal impact
- **Gamepad Logging**: Only logs on state changes, minimal impact
- **All logging uses `ahprintf()`**: Non-blocking, doesn't affect real-time performance

### Log Volume
- **Normal Operation**: Very few logs (only on button presses/releases)
- **Troubleshooting**: High volume when investigating issues (every button state change)
- **Production**: Should be removed to reduce log noise

## Removal

All debug logging was removed in v1.0.9 after confirming:
1. GPIO 26 issues were hardware-related (damaged Pico W from 5V back-feeding)
2. Gamepad button mapping issues were resolved (Circle button filter, GPIO remapping)
3. GPIO initialization safety was verified (all GPIOs start as INPUT)

## Lessons Learned

1. **GPIO 26 (ADC0) is sensitive**: Requires explicit `gpio_set_function(GPIO_FUNC_SIO)` to prevent ADC interference
2. **Pull-ups must be disabled for OUTPUT**: `gpio_set_pulls(gpio, false, false)` before setting to OUTPUT
3. **Hardware protection is critical**: 5V back-feeding can damage GPIOs if Pico is not powered
4. **Bluepad32 D-pad quirk**: Hat value `0` maps to `DPAD_UP`, requiring filtering when buttons are pressed
5. **GPIO conflicts cause crashes**: Multiple drivers on same GPIO can cause system instability

## Related Documentation

- `device_troubleshooting.md`: Details fixes for DS5 pairing, Stadia controller issues, and joystick port 1 fixes
- `gpio-fixes-todo.md`: Documents GPIO conflict fixes and remapping
- `amiga-code-atari-board-gpio-mappings.md`: Complete GPIO mapping documentation

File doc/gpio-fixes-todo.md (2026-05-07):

# GPIO Fixes and TODO

## Square Button (BUTTON_X) Causing Bluetooth Disconnect - FIXED

### Problem
Pressing the Square button (BUTTON_X) on DS5/Stadia controllers causes the Bluetooth connection to disconnect and the device to crash.

### Root Cause
**GPIO 18 Conflict:**
- `QM2_AMIGA_B3` (Joystick Port 2 Button 3) uses GPIO 18 - configured as OUTPUT
- `GPIO_BUTTON_LEFT` (Display left button) uses GPIO 18 - configured as INPUT with pull-up

When Square button is pressed:
1. Joystick code tries to set GPIO 18 as OUTPUT (active low)
2. Display code has already configured GPIO 18 as INPUT
3. GPIO conflict causes system instability/crash
4. Bluetooth stack crashes and disconnects

### Fix Applied (v1.0.4)
**Files Modified:**
- `src/platform/amiga/joystick_port2.c`: Disabled `AJ2_BUTTON3` handling
- `src/usb_hid.c`: Disabled Button 3 mapping for both USB and Bluetooth gamepads

**Changes:**
1. Commented out `amiga_gpio_set_active_low(QM2_AMIGA_B3, pressed)` in `joystick_port2.c`
2. Commented out `amiga_joystick_port2_set_button(AJ2_BUTTON3, ...)` calls in `usb_hid.c`
3. Added TODO comments documenting the conflict

### Current Button Mapping (Port 2)
- **BUTTON_A (X/Fire)**: ✅ Works - mapped to Port 2 Fire
- **BUTTON_B (Circle)**: ✅ Works - mapped to Port 2 Button 2
- **BUTTON_X (Square)**: ❌ Disabled - GPIO 18 conflict with display button
- **BUTTON_Y (Triangle)**: ❌ Disabled - same conflict

### Hardware Fix Required
To restore Button 3 functionality, **remap `QM2_AMIGA_B3` to a different GPIO** in hardware.

**Current:** `QM2_AMIGA_B3 = GPIO 18` (conflicts with `GPIO_BUTTON_LEFT`)

**Recommended:** Choose a free GPIO that doesn't conflict with:
- Display buttons (GPIO 16, 17, 18)
- Joystick Port 1 (GPIO 7-13)
- Joystick Port 2 (GPIO 18-22, 26-27)
- Keyboard (GPIO 4-6)
- I2C Display (GPIO 8-9)

### Related Issues
- **Circle Button Triggering UP**: Fixed in v1.0.3 - D-pad UP ignored when buttons are pressed (prevents HID standard hat value 0 = UP from interfering)

### Testing Notes
- Square button no longer causes crashes
- Circle button no longer triggers UP movement
- Fire button (A) works correctly
- Button 3 functionality disabled until hardware remap

### Version History
- **v1.0.3**: Added Circle button UP fix and debug logging
- **v1.0.4**: Fixed Square button GPIO conflict (disabled Button 3)

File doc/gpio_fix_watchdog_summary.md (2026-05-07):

# GPIO Fix and Watchdog Implementation Summary

## Overview
This document summarizes the changes made to address intermittent mouse/joystick failures by implementing GPIO state management and a lightweight watchdog system.

## Problem Statement
Intermittent failures were observed where mouse and joystick inputs would stop working. Analysis suggested potential causes:
- Power sequencing issues (Amiga pull-ups pulling lines high before Pico initializes)
- GPIO state corruption during operation
- Race conditions during initialization

## Solution: Two-Part Approach

### 1. GPIO Clearing on Power-Up

**Location**: `src/main.c` (lines 84-94)

**Implementation**:
- Added a 100ms delay after `amiga_init()` to allow power to stabilize
- Added call to `amiga_gpio_reset_all_to_input()` before initializing mouse/joystick ports
- This ensures all Amiga-related GPIOs are set to a known inactive (INPUT) state
- Only active for Revision 5 hardware (`#if HIDPICO_REVISION == 5`)

**Code**:
```c
#if HIDPICO_REVISION == 5
    // Wait for power to stabilize (especially important if Amiga is already powered)
    // This prevents race conditions where Amiga's pull-ups pull lines high before Pico initializes
    sleep_ms(100);
    
    // Clear all GPIO direction cache and reset all Amiga GPIOs to INPUT (inactive/high) state
    // This ensures clean state even if Amiga is already powered and pull-ups are active
    amiga_gpio_reset_all_to_input();
    
    printf("GPIO state cleared and reset to INPUT\n");
#endif
```

### 2. Lightweight Watchdog

**Location**: 
- `src/main.c` (lines 110-141) - Watchdog check in main loop
- `src/platform/common/gpio_util.c` (lines 110-160) - Watchdog implementation
- `src/platform/common/gpio_util.h` (lines 59-64) - Watchdog declaration

**Implementation**:
- Periodic check every 5 seconds (configurable via `WATCHDOG_INTERVAL_MS`)
- Samples 4 representative GPIOs (one direction and one button from each port)
- Compares actual hardware GPIO direction with cached direction state
- If mismatch detected, triggers full GPIO reset to recover
- Minimal performance impact: only checks 4 GPIOs every 5 seconds

**Code**:
```c
// In main loop:
absolute_time_t last_watchdog_check = get_absolute_time();
const uint32_t WATCHDOG_INTERVAL_MS = 5000;  // Check every 5 seconds

// In main loop:
#if HIDPICO_REVISION == 5
    absolute_time_t now = get_absolute_time();
    if (absolute_time_diff_us(last_watchdog_check, now) >= (WATCHDOG_INTERVAL_MS * 1000)) {
        if (amiga_gpio_watchdog_check()) {
            printf("[WATCHDOG] GPIO state recovery performed\n");
        }
        last_watchdog_check = now;
    }
#endif
```

**Watchdog Function**:
```c
bool amiga_gpio_watchdog_check(void)
{
    // Sample GPIOs to check (one from each port)
    const uint32_t sample_gpios[] = {
        QM1_AMIGA_V,   // Port 1 UP direction
        QM1_AMIGA_B1,  // Port 1 Fire button
        QM2_AMIGA_V,   // Port 2 UP direction
        QM2_AMIGA_B1,  // Port 2 Fire button
    };
    
    // Check if any sampled GPIO has mismatched direction
    // If mismatch found, reset all GPIOs to INPUT state
    // Returns true if recovery was performed
}
```

## New Functions Added

### `amiga_gpio_clear_all_cache()`
- Clears all cached GPIO direction states
- Called before full GPIO reset

### `amiga_gpio_reset_all_to_input()`
- Resets all Amiga joystick/mouse GPIOs to INPUT (inactive/high) state
- Initializes all 14 GPIOs (7 per port: H, V, HQ, VQ, B1, B2, B3)
- Clears GPIO direction cache before resetting

### `amiga_gpio_watchdog_check()`
- Lightweight watchdog that samples GPIOs to detect stuck states
- Returns `true` if recovery was performed, `false` otherwise
- Only active for Revision 5 hardware

## Performance Impact

**GPIO Clearing on Power-Up**:
- One-time cost: ~100ms delay + GPIO initialization
- Negligible impact on normal operation

**Watchdog**:
- Checks 4 GPIOs every 5 seconds
- Estimated overhead: <0.01% CPU time
- No impact on normal operation performance

## GPIOs Affected

**Port 1 / Mouse** (7 GPIOs):
- `QM1_AMIGA_H` - Horizontal direction
- `QM1_AMIGA_V` - Vertical direction
- `QM1_AMIGA_HQ` - Horizontal quadrature
- `QM1_AMIGA_VQ` - Vertical quadrature
- `QM1_AMIGA_B1` - Fire button
- `QM1_AMIGA_B2` - Button 2
- `QM1_AMIGA_B3` - Button 3

**Port 2** (7 GPIOs):
- `QM2_AMIGA_H` - Horizontal direction
- `QM2_AMIGA_V` - Vertical direction
- `QM2_AMIGA_HQ` - Horizontal quadrature
- `QM2_AMIGA_VQ` - Vertical quadrature
- `QM2_AMIGA_B1` - Fire button
- `QM2_AMIGA_B2` - Button 2
- `QM2_AMIGA_B3` - Button 3

## Testing Recommendations

1. **Power Sequencing Test**: Power on Amiga first, then Pico, verify mouse/joystick work
2. **Watchdog Test**: Monitor serial output for `[WATCHDOG]` messages during extended operation
3. **Stress Test**: Run for extended periods to verify no intermittent failures
4. **Recovery Test**: If watchdog triggers, verify mouse/joystick continue working after recovery

## Files Modified

1. `src/main.c` - Added GPIO clearing and watchdog check
2. `src/platform/common/gpio_util.c` - Added reset and watchdog functions
3. `src/platform/common/gpio_util.h` - Added function declarations

## Build Information

- **Target Hardware**: Revision 5 (Pico W / Pico 2 W)
- **Conditional Compilation**: All changes are wrapped in `#if HIDPICO_REVISION == 5`
- **Backward Compatibility**: No changes to other hardware revisions

## Date
Implementation completed: [Current Date]

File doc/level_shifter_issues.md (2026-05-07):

# Level Shifter Issues and Solutions

## Problem Description

After adding 8-way level shifters (5V ↔ 3.3V) to protect joystick GPIOs, the following issues were observed:

1. **Delayed input detection** - Movement inputs are delayed
2. **Fire button dependency** - Movement is only detected when combined with fire button press
3. **Inconsistent behavior** - Signals don't work reliably

## Root Cause Analysis

### Current GPIO Configuration

The current code uses this approach for inactive signals:
```c
// Inactive: set to HIGH (1) by setting as input (pulled high)
gpio_set_dir(gpio, GPIO_IN);
gpio_set_pulls(gpio, true, false);  // Enable pull-up, disable pull-down
```

**Problem**: When using level shifters, the Pico's internal pull-ups (3.3V) can conflict with:
- The level shifter's direction detection
- The Amiga's pull-ups (5V) on the other side
- The level shifter's internal pull-up/pull-down configuration

### Why Fire Button Makes It Work

The fire button dependency suggests:
1. **Direction detection issue**: Bidirectional level shifters need to detect signal direction. When fire is pressed (OUTPUT LOW), it might "wake up" or configure the shifter, allowing other signals to pass through.
2. **Pull-up conflict**: The Pico's 3.3V pull-up might not be strong enough or might conflict with the level shifter's 5V side pull-ups.
3. **Enable pin**: Some level shifters have enable pins that might need a reference signal.

## Solutions

### Solution 1: INPUT Mode with NO Pull-Up (Current Approach)

When using bidirectional level shifters, set GPIO to **INPUT with NO pull-up** and let the level shifter translate the Amiga's 5V pull-up.

**Implementation**:
```c
// Inactive: Set as INPUT with NO pull-up
gpio_set_dir(gpio, GPIO_IN);
gpio_set_pulls(gpio, false, false);  // No pull-up - level shifter handles translation
```

**How it works**:
- Pico side: INPUT (high-impedance, no pull-up)
- Amiga side: 5V pull-up pulls the 5V side HIGH
- Level shifter: Detects 5V side is driving HIGH, translates to 3.3V HIGH on Pico side
- Amiga sees: HIGH (5V) = inactive ✓

**Why this should work**:
- The level shifter detects that the 5V side (Amiga) is driving HIGH via pull-up
- The level shifter translates this to 3.3V HIGH on the Pico side
- No conflict between Pico's 3.3V pull-up and level shifter direction detection
- When Pico drives LOW (OUTPUT), level shifter detects 3.3V side driving, translates to 0V on 5V side

**Note**: This requires the level shifter to properly detect direction. If this doesn't work, the level shifter may need external pull-ups or a different configuration.

### Solution 2: Add External Pull-Ups on 5V Side (REQUIRED for TXB0108)

**The TXB0108 REQUIRES pull-up resistors on BOTH sides for proper bidirectional operation.**

Add external pull-up resistors (10kΩ to 50kΩ) on the 5V side (B side) of the TXB0108 level shifter.

**Circuit**:
```
Amiga (5V) ←--[10kΩ pull-up to 5V]--← TXB0108 B side ←-- TXB0108 A side ←-- Pico GPIO (INPUT, no pull-up)
```

**Why this is critical for TXB0108**:
- TXB0108 uses automatic direction detection based on which side is driving
- Without pull-ups on the 5V side, the level shifter cannot properly detect when the Amiga's pull-up is "driving" HIGH
- The weak internal pull-ups in TXB0108 are not sufficient for reliable operation
- External 10kΩ pull-ups on the 5V side ensure proper HIGH state detection

**Implementation**:
- Add pull-up resistors from each TXB0108 B-side pin (5V side) to 5V
- **Resistor value options**:
  - **22kΩ to 47kΩ (recommended)**: Reduces current draw, still provides sufficient pull-up strength
  - **10kΩ**: Works but draws more current (effective ~5kΩ with Amiga's internal pull-up)
- Connect between level shifter B-side and 5V power supply
- These work in parallel with the Amiga's internal pull-ups (~10kΩ)

**Current Draw Consideration**:
- With 10kΩ external + 10kΩ internal = ~5kΩ effective resistance
- Current: 5V / 5kΩ = 1mA per signal (typically safe for Amiga)
- With 22kΩ external + 10kΩ internal = ~6.9kΩ effective resistance  
- Current: 5V / 6.9kΩ = ~0.7mA per signal (safer, still sufficient)
- **Recommendation**: Use 22kΩ to 47kΩ to reduce current draw while still providing adequate pull-up strength

### Solution 3: Configure Level Shifter Direction

If using bidirectional level shifters (like TXB0108, SN74LVC8T245), ensure:
- Direction pins are configured correctly
- Enable pins (if present) are tied appropriately
- VCC_A (3.3V) and VCC_B (5V) are properly connected

### Solution 4: Use Unidirectional Level Shifters

For joystick ports, signals are **always driven FROM Pico TO Amiga** (never the reverse). Consider using unidirectional level shifters configured for 3.3V → 5V direction only.

**Advantages**:
- No direction detection needed
- Lower propagation delay
- More reliable

## Recommended Implementation

### Modified GPIO Configuration for Level Shifters

Create a new function or modify `amiga_gpio_set_active_low()` to support level shifter mode:

```c
void amiga_gpio_set_active_low_with_level_shifter(uint32_t gpio, bool active)
{
    if (gpio >= MAX_GPIO) {
        return;
    }
    
    if (active) {
        // Active: Drive LOW (0V) as OUTPUT
        gpio_set_pulls(gpio, false, false);  // Disable pulls
        gpio_set_dir(gpio, GPIO_OUT);
        gpio_put(gpio, 0);
        __sync_synchronize();
    } else {
        // Inactive: High-impedance INPUT with NO pull-up
        // Let level shifter and Amiga pull-ups handle the HIGH state
        gpio_set_dir(gpio, GPIO_IN);
        gpio_set_pulls(gpio, false, false);  // NO pull-up - critical for level shifters
        __sync_synchronize();
    }
}
```

### Configuration Option

Add a compile-time or runtime option to enable level shifter mode:

```c
// In config.h
#define ENABLE_LEVEL_SHIFTER 1  // Set to 1 if using level shifters

// In gpio_util.c
void amiga_gpio_set_active_low(uint32_t gpio, bool active)
{
    if (gpio >= MAX_GPIO) {
        return;
    }
    
    if (active) {
        gpio_set_pulls(gpio, false, false);
        gpio_set_dir(gpio, GPIO_OUT);
        gpio_put(gpio, 0);
        __sync_synchronize();
    } else {
        gpio_set_dir(gpio, GPIO_IN);
#if ENABLE_LEVEL_SHIFTER
        // Level shifter mode: No pull-up, rely on external/Amiga pull-ups
        gpio_set_pulls(gpio, false, false);
#else
        // Direct connection: Use Pico's internal pull-up
        gpio_set_pulls(gpio, true, false);
#endif
        __sync_synchronize();
    }
}
```

## Testing Recommendations

1. **Test with pull-ups disabled**: Modify code to disable Pico pull-ups and test
2. **Check level shifter datasheet**: Verify direction/enable pin requirements
3. **Measure signals**: Use oscilloscope to check:
   - 3.3V side signals (Pico GPIO)
   - 5V side signals (Amiga side)
   - Propagation delay
4. **Test individual signals**: Test each direction/button independently to isolate issues

## Level Shifter Selection Notes

### Recommended Level Shifters for This Application

1. **TXB0108** (8-bit bidirectional):
   - Automatic direction detection
   - **REQUIRES pull-up resistors on BOTH sides (A and B) for proper operation**
   - OE (Output Enable) pin - typically tied to VCCA (3.3V) to enable
   - **Critical**: Without pull-ups on the 5V side (B side), direction detection may fail
   - Pull-up values: 10kΩ to 50kΩ recommended
   - The TXB0108 uses weak internal pull-ups, but external pull-ups improve reliability

2. **SN74LVC8T245** (8-bit bidirectional):
   - Direction pin (DIR) must be set
   - Enable pin (OE) must be controlled
   - Faster than TXB0108

3. **Unidirectional (3.3V → 5V only)**:
   - Simpler, more reliable for this use case
   - Lower cost
   - No direction detection needed

## Additional Considerations

### Propagation Delay

Level shifters add propagation delay (typically 5-20ns). This should be negligible for joystick signals, but if you're seeing delays, check:
- Level shifter speed rating
- Capacitive loading on signals
- Power supply stability

### Power Sequencing

Ensure proper power sequencing:
- 3.3V and 5V should be stable before signals are applied
- Level shifter should be powered before Pico starts driving signals

### Ground Connection

**Critical**: Ensure a common ground between:
- Pico GND
- Level shifter GND (3.3V side)
- Level shifter GND (5V side)  
- Amiga GND

All grounds must be connected for level shifters to work correctly.

## Additional Troubleshooting

### If Only Fire Button Works (TXB0108 Specific)

If only the fire button works but directions don't, this is **almost certainly due to missing pull-up resistors on the 5V side** of the TXB0108:

1. **TXB0108 requires external pull-ups**: The TXB0108 datasheet explicitly requires 10kΩ to 50kΩ pull-up resistors on BOTH sides for proper operation.
2. **Fire button works because**: It might have different timing or be driven more consistently, allowing the weak internal pull-ups to function temporarily.
3. **Directions fail because**: Without proper pull-ups on the 5V side, the level shifter cannot detect when the Amiga's pull-up is driving HIGH, causing direction detection to fail.
4. **Solution**: **Add 10kΩ pull-up resistors from each TXB0108 B-side pin (5V side) to 5V power supply.**

### Potential Solutions to Try

1. **Add external pull-ups on 5V side**: If the level shifter doesn't have internal pull-ups, add 10kΩ resistors from each 5V signal to 5V
2. **Check level shifter enable pins**: Some level shifters have enable pins that must be tied correctly
3. **Verify level shifter type**: Ensure you're using a bidirectional level shifter (not unidirectional)
4. **Check signal timing**: Add small delays between direction changes to allow level shifter to settle
5. **Try unidirectional level shifters**: Since signals only go FROM Pico TO Amiga, unidirectional shifters might work better

### Questions to Answer

1. **What level shifter chip are you using?** (TXB0108, SN74LVC8T245, etc.)
2. **Are enable/direction pins configured correctly?**
3. **Do you have pull-up resistors on the 5V side?**
4. **Are all grounds connected?**
5. **What happens if you test with a multimeter/scope?**

## Next Steps

### IMMEDIATE ACTION REQUIRED (TXB0108)

**You MUST add external pull-up resistors on the 5V side of the TXB0108 for proper operation.**

1. **Add 10kΩ pull-up resistors**: Connect a 10kΩ resistor from each TXB0108 B-side pin (5V side) to 5V power supply.
   - One resistor per signal line (UP, DOWN, LEFT, RIGHT, FIRE, etc.)
   - Connect between the TXB0108 B-side pin and 5V
   - These work in parallel with the Amiga's internal pull-ups (~10kΩ)

2. **Current software configuration**: INPUT mode with NO pull-up on Pico side (already correct)
   - This lets the level shifter translate the Amiga's 5V pull-up
   - With external pull-ups on 5V side, the TXB0108 will properly detect direction

3. **Verify hardware**: After adding pull-ups, verify:
   - All grounds are connected (Pico, level shifter 3.3V GND, level shifter 5V GND, Amiga)
   - OE pin is tied to 3.3V (VCCA) to enable the level shifter
   - Power supplies are stable (3.3V and 5V)

4. **Test incrementally**: After adding pull-ups, test one signal at a time to verify operation

5. **Measure signals**: Use scope/multimeter to verify:
   - 3.3V side signals (Pico GPIO) are correct
   - 5V side signals (Amiga side) are correct
   - Level shifter is translating properly in both directions

### Why This Is Required

The TXB0108 datasheet (Section 8.2.1) explicitly states:
> "For proper operation, pull-up resistors must be connected to all I/O pins on both sides of the device."

Without these pull-ups, the automatic direction detection feature of the TXB0108 will not work reliably, which explains why only the fire button works (it might work intermittently due to timing).

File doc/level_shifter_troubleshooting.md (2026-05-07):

# Level Shifter Troubleshooting Guide

## Quick Checklist

### 1. Resistor Placement
- ✅ **5V side (TXB0108 B-side)**: Resistors must be on the **5V side** (Amiga side), NOT the 3.3V side
- ✅ **Connection**: One end to TXB0108 B-side pin, other end to **5V power supply**
- ✅ **Value**: 10kΩ to 22kΩ (10kΩ is fine, 22kΩ reduces current draw)

### 2. Which Pins Need Resistors?

**Joystick Port 1 (Revision 5)**:
- GPIO 10 (UP) → TXB0108 B-side → **10kΩ to 5V**
- GPIO 11 (DOWN) → TXB0108 B-side → **10kΩ to 5V**
- GPIO 12 (LEFT) → TXB0108 B-side → **10kΩ to 5V**
- GPIO 13 (RIGHT) → TXB0108 B-side → **10kΩ to 5V**
- GPIO 14 (FIRE) → TXB0108 B-side → **10kΩ to 5V** (if not working)

**Joystick Port 2 (Revision 5)**:
- GPIO 20 (UP) → TXB0108 B-side → **10kΩ to 5V**
- GPIO 21 (DOWN) → TXB0108 B-side → **10kΩ to 5V**
- GPIO 22 (LEFT) → TXB0108 B-side → **10kΩ to 5V**
- GPIO 23 (RIGHT) → TXB0108 B-side → **10kΩ to 5V**
- GPIO 26 (FIRE) → TXB0108 B-side → **10kΩ to 5V** (if not working)

### 3. Common Issues

#### Issue: Resistors on Wrong Side
**Symptom**: Still doesn't work after adding resistors
**Solution**: Verify resistors are on **5V side (B-side)**, not 3.3V side (A-side)

#### Issue: Resistors Not Connected to 5V
**Symptom**: Still doesn't work
**Solution**: Verify one end of resistor goes to **5V power supply**, not 3.3V

#### Issue: Wrong Resistor Value
**Symptom**: Works but draws too much current
**Solution**: Use 22kΩ instead of 10kΩ to reduce current draw

#### Issue: TXB0108 OE Pin Not Enabled
**Symptom**: Nothing works
**Solution**: Verify OE (Output Enable) pin is tied to **3.3V** (VCCA)

#### Issue: Ground Connections
**Symptom**: Unreliable operation
**Solution**: Verify all grounds are connected:
- Pico GND
- TXB0108 GND (3.3V side)
- TXB0108 GND (5V side)
- Amiga GND

### 4. Testing Procedure

1. **Test Fire Button First**: If fire button works, the level shifter is working for that signal
2. **Add Resistors One at a Time**: Start with one direction (e.g., UP), test, then add others
3. **Verify Connections**: Use multimeter to verify:
   - Resistor connects TXB0108 B-side pin to 5V
   - TXB0108 A-side pin connects to Pico GPIO
   - TXB0108 B-side pin connects to Amiga

### 5. Verification Steps

1. **Power Off**: Disconnect power
2. **Check Resistor Placement**: 
   - Resistor should connect TXB0108 **B-side pin** (5V side) to **5V power**
   - NOT on A-side (3.3V side)
3. **Check Connections**:
   - One end of resistor → TXB0108 B-side pin
   - Other end of resistor → 5V power supply
4. **Power On**: Reconnect power and test

### 6. Expected Behavior

**With Pull-ups Correctly Installed**:
- ✅ All directions work independently
- ✅ Fire button works
- ✅ No delay when pressing directions
- ✅ Directions work without pressing fire button

**Without Pull-ups (or Wrong Side)**:
- ❌ Only fire button works (or nothing works)
- ❌ Directions only work when fire button is pressed
- ❌ Delayed input detection
- ❌ Inconsistent behavior

### 7. TXB0108 Pinout Reference

```
TXB0108 (8-bit bidirectional level shifter)

A-side (3.3V)          B-side (5V)
--------              --------
A1  →  Pico GPIO      B1  →  Amiga Signal
A2  →  Pico GPIO      B2  →  Amiga Signal
A3  →  Pico GPIO      B3  →  Amiga Signal
A4  →  Pico GPIO      B4  →  Amiga Signal
A5  →  Pico GPIO      B5  →  Amiga Signal
A6  →  Pico GPIO      B6  →  Amiga Signal
A7  →  Pico GPIO      B7  →  Amiga Signal
A8  →  Pico GPIO      B8  →  Amiga Signal

VCCA (3.3V)           VCCB (5V)
GNDA (3.3V GND)       GNDB (5V GND)
OE (Output Enable) → 3.3V (tied to VCCA)
```

**Pull-up resistors go on B-side (5V side)**: Connect between each B1-B8 pin and VCCB (5V).

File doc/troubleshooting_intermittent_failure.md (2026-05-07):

# Troubleshooting: Intermittent Mouse/Joystick Failure

## Symptom
Both mouse and joystick stopped working on the Amiga, but started working again after unplugging and replugging the Pico adapter.

## Potential Causes and Solutions

### 1. Power Supply Issues (MOST LIKELY)

**Problem**: The Pico is currently powered by USB, not from the Amiga's 5V controller port.

**Why this matters:**
- **Ground potential differences**: If the Pico (USB-powered) and Amiga (separate power supply) have different ground potentials, signals may not work correctly
- **Power sequencing**: If the Amiga powers on before the Pico, or vice versa, GPIO states might be incorrect
- **USB power instability**: USB power can be unstable, especially if:
  - USB port is low-power (some USB 2.0 ports)
  - USB cable is long or poor quality
  - USB hub is used
  - Computer goes to sleep/suspends

**Solutions:**
1. **Power from Amiga controller port** (RECOMMENDED):
   - Connect the Pico's VSYS pin to the Amiga's +5V from the controller port
   - Connect GND from Pico to Amiga GND
   - This ensures both devices share the same power and ground
   - **Note**: Ensure proper voltage regulation (Amiga 5V → Pico VSYS, which accepts 1.8V-5.5V)

2. **Use a powered USB hub**:
   - If you must use USB power, use a powered USB hub to ensure stable 5V

3. **Check USB cable quality**:
   - Use a high-quality USB cable with proper power delivery
   - Avoid long or thin cables

### 2. GPIO State Corruption

**Problem**: GPIO pins might get stuck in an incorrect state due to:
- Software bug causing incorrect GPIO configuration
- Power glitch corrupting GPIO state
- Hot-plugging causing initialization issues

**Symptoms:**
- GPIOs stuck as OUTPUT when they should be INPUT (or vice versa)
- GPIO direction cache getting out of sync with actual hardware state

**Solutions:**
1. **Add GPIO reset function**:
   ```c
   void amiga_gpio_reset_all(void) {
       // Reset all Amiga GPIOs to known state
       amiga_joystick_port1_reset();
       amiga_joystick_port2_reset();
       // Re-initialize mouse GPIOs
       amiga_quad_mouse_init();
   }
   ```

2. **Clear GPIO direction cache on reset**:
   - The `gpio_dir_cache` in `gpio_util.c` could get out of sync
   - Add a function to clear the cache and re-initialize

3. **Add watchdog/reset capability**:
   - Monitor GPIO state periodically
   - Reset if stuck in incorrect state

### 3. Hot-Plugging Issues

**Problem**: Connecting/disconnecting the Pico while the Amiga is powered can cause:
- GPIO pins to be driven by the Amiga's pull-ups before Pico initializes
- Initialization race conditions
- GPIO state conflicts

**Solutions:**
1. **Power sequencing**:
   - Always power on the Amiga first, then connect the Pico
   - Or: Connect Pico first, then power on Amiga
   - Avoid hot-plugging during operation

2. **Add initialization delay**:
   - Add a small delay after power-on before initializing GPIOs
   - This allows power to stabilize

### 4. Voltage Level Issues

**Problem**: While the design should work (3.3V Pico driving 5V Amiga signals), edge cases might occur:
- If Pico GPIO is accidentally driven HIGH (3.3V), Amiga might read it as HIGH (works, but not ideal)
- If there's a voltage spike or noise, it could cause issues

**Solutions:**
1. **Add pull-up resistors on hardware** (if not already present):
   - External 10kΩ pull-ups on Amiga side ensure clean HIGH state
   - Amiga should have internal pull-ups, but external ones add redundancy

2. **Add input protection**:
   - Series resistors (100-220Ω) on signal lines can protect against voltage spikes
   - Schottky diodes for overvoltage protection (if needed)

### 5. Initialization Order Issues

**Problem**: The initialization order in `main.c` might cause conflicts:
- Mouse and joystick port 1 share the same GPIOs
- If both try to initialize the same pins, conflicts can occur

**Current initialization order:**
```c
amiga_quad_mouse_init();      // Initializes Port 1 GPIOs
amiga_joystick_port1_init();  // Re-initializes same GPIOs
amiga_joystick_port2_init();  // Initializes Port 2 GPIOs
```

**Solutions:**
1. **Ensure proper initialization order**:
   - Both mouse and joystick port 1 initialize the same pins
   - This should be fine, but ensure they both set pins to INPUT initially

2. **Add conflict detection**:
   - Check if GPIOs are already initialized before re-initializing
   - Log warnings if conflicts detected

### 6. USB Host Stack Issues

**Problem**: If the USB host stack (TinyUSB) has issues, it might affect the main loop:
- `tuh_task()` blocking or hanging
- USB enumeration issues causing delays
- This could make the adapter appear "dead" even though GPIOs are working

**Solutions:**
1. **Add timeout handling**:
   - Ensure `tuh_task()` doesn't block indefinitely
   - Add watchdog to detect if main loop stops

2. **Monitor USB state**:
   - Log USB events to help diagnose issues

## Recommended Immediate Actions

### 1. Power from Amiga (BEST SOLUTION)
**Hardware modification:**
- Connect Amiga +5V (from controller port) to Pico VSYS pin
- Connect Amiga GND to Pico GND
- Keep USB connected for data only (or use separate USB data connection)

**Benefits:**
- ✅ Shared power and ground eliminates potential differences
- ✅ More stable power supply
- ✅ Proper power sequencing
- ✅ No USB power issues

### 2. Add GPIO Reset/Clear Function

**After Power-Up (Recommended)**:
Add a function to explicitly clear/reset all GPIOs before initialization. This ensures a clean state even if the Amiga is already powered:

```c
void amiga_gpio_clear_all_before_init(void) {
    // Clear GPIO direction cache
    for (int i = 0; i < 32; i++) {
        amiga_gpio_clear_cache(i);
    }
    
    // Explicitly set all Amiga GPIOs to INPUT (inactive/high) before initialization
    // This ensures clean state even if Amiga is already powered
    amiga_gpio_init_active_low(QM1_AMIGA_H, false);
    amiga_gpio_init_active_low(QM1_AMIGA_V, false);
    amiga_gpio_init_active_low(QM1_AMIGA_HQ, false);
    amiga_gpio_init_active_low(QM1_AMIGA_VQ, false);
    amiga_gpio_init_active_low(QM1_AMIGA_B1, false);
    amiga_gpio_init_active_low(QM1_AMIGA_B2, false);
    amiga_gpio_init_active_low(QM1_AMIGA_B3, false);
    
    amiga_gpio_init_active_low(QM2_AMIGA_H, false);
    amiga_gpio_init_active_low(QM2_AMIGA_V, false);
    amiga_gpio_init_active_low(QM2_AMIGA_HQ, false);
    amiga_gpio_init_active_low(QM2_AMIGA_VQ, false);
    amiga_gpio_init_active_low(QM2_AMIGA_B1, false);
    amiga_gpio_init_active_low(QM2_AMIGA_B2, false);
    amiga_gpio_init_active_low(QM2_AMIGA_B3, false);
}
```

Call this in `main()` before initializing mouse/joystick ports, with a small delay:

```c
// Wait for power to stabilize (especially if Amiga is already powered)
sleep_ms(100);

// Clear all GPIOs to known state before initialization
amiga_gpio_clear_all_before_init();

// Now initialize normally
amiga_quad_mouse_init();
amiga_joystick_port1_init();
amiga_joystick_port2_init();
```

**During Use (Recovery)**:
Add a watchdog function to detect and recover from stuck GPIO states:

```c
void amiga_gpio_recover_if_stuck(void) {
    // Check if GPIOs are stuck in wrong state
    // If detected, reset them
    // This would be called periodically from main loop
}
```

### 3. Add Diagnostic Logging
Add serial output to help diagnose issues:
- Log GPIO state on initialization
- Log if GPIO state changes unexpectedly
- Log power-on sequence

### 4. Add Watchdog
Monitor that the main loop is running and GPIOs are responding:
- If no input for extended period, reset GPIOs
- Detect stuck GPIO states

## Testing Recommendations

1. **Power source test**:
   - Try powering from Amiga controller port instead of USB
   - See if issue persists

2. **Power sequencing test**:
   - Try different power-on sequences:
     - Amiga first, then Pico
     - Pico first, then Amiga
     - Both simultaneously
   - Note which sequence works best

3. **USB cable test**:
   - Try different USB cables
   - Try different USB ports
   - Try powered USB hub

4. **Monitor serial output**:
   - Connect serial console to see if Pico is still running
   - Check for error messages
   - Verify initialization messages

## Long-term Solutions

1. **Hardware improvements**:
   - Add proper power management (power from Amiga)
   - Add input protection (series resistors, protection diodes)
   - Add status LED to indicate Pico is running

2. **Software improvements**:
   - Add GPIO state monitoring
   - Add automatic recovery from stuck states
   - Add watchdog timer
   - Improve error handling and logging

3. **Documentation**:
   - Document recommended power setup
   - Document known issues and workarounds
   - Add troubleshooting guide

## Most Likely Causes (with Quality AC-USB Supply)

Since you're using a good quality AC-USB supply, USB power instability is less likely. The most likely causes are:

### 1. Ground Potential Differences (MOST LIKELY)

**Problem**: Even with good USB power, if the Pico (USB-powered) and Amiga (separate PSU) have different ground potentials, signals may not work correctly.

**Why this happens**:
- USB power supply and Amiga PSU may have slight ground potential differences
- This can cause signals to be misread or not work reliably
- Intermittent because it depends on power supply state, load, etc.

**Solution**: Power the Pico from the Amiga's controller port +5V instead of USB. This ensures:
- Shared power and ground (eliminates potential differences)
- More stable operation
- Proper power sequencing

### 2. GPIO Initialization Race Condition

**Problem**: If the Amiga is already powered when the Pico boots:
- Amiga's pull-up resistors pull lines HIGH immediately
- Pico initializes GPIOs, but there's a race condition
- Mouse and joystick port 1 both initialize the same GPIOs (potential conflict)

**Solution**: Add explicit GPIO reset/clear before initialization:
- Clear GPIO direction cache
- Add small delay to let power stabilize
- Ensure all GPIOs are explicitly set to INPUT before use

### 3. Hot-Plugging Issues

**Problem**: Connecting the Pico while the Amiga is already powered can cause:
- GPIOs to be in unknown state during initialization
- Initialization order issues

**Solution**: 
- Always power on in consistent order (Amiga first, then Pico, or vice versa)
- Add delay after power-on before GPIO initialization

## Additional Notes

- The 3.3V vs 5V voltage difference should not be an issue (as documented in `electrical_operation.md`)
- The design is electrically safe for the Amiga
- The issue is likely power/initialization related, not voltage level related

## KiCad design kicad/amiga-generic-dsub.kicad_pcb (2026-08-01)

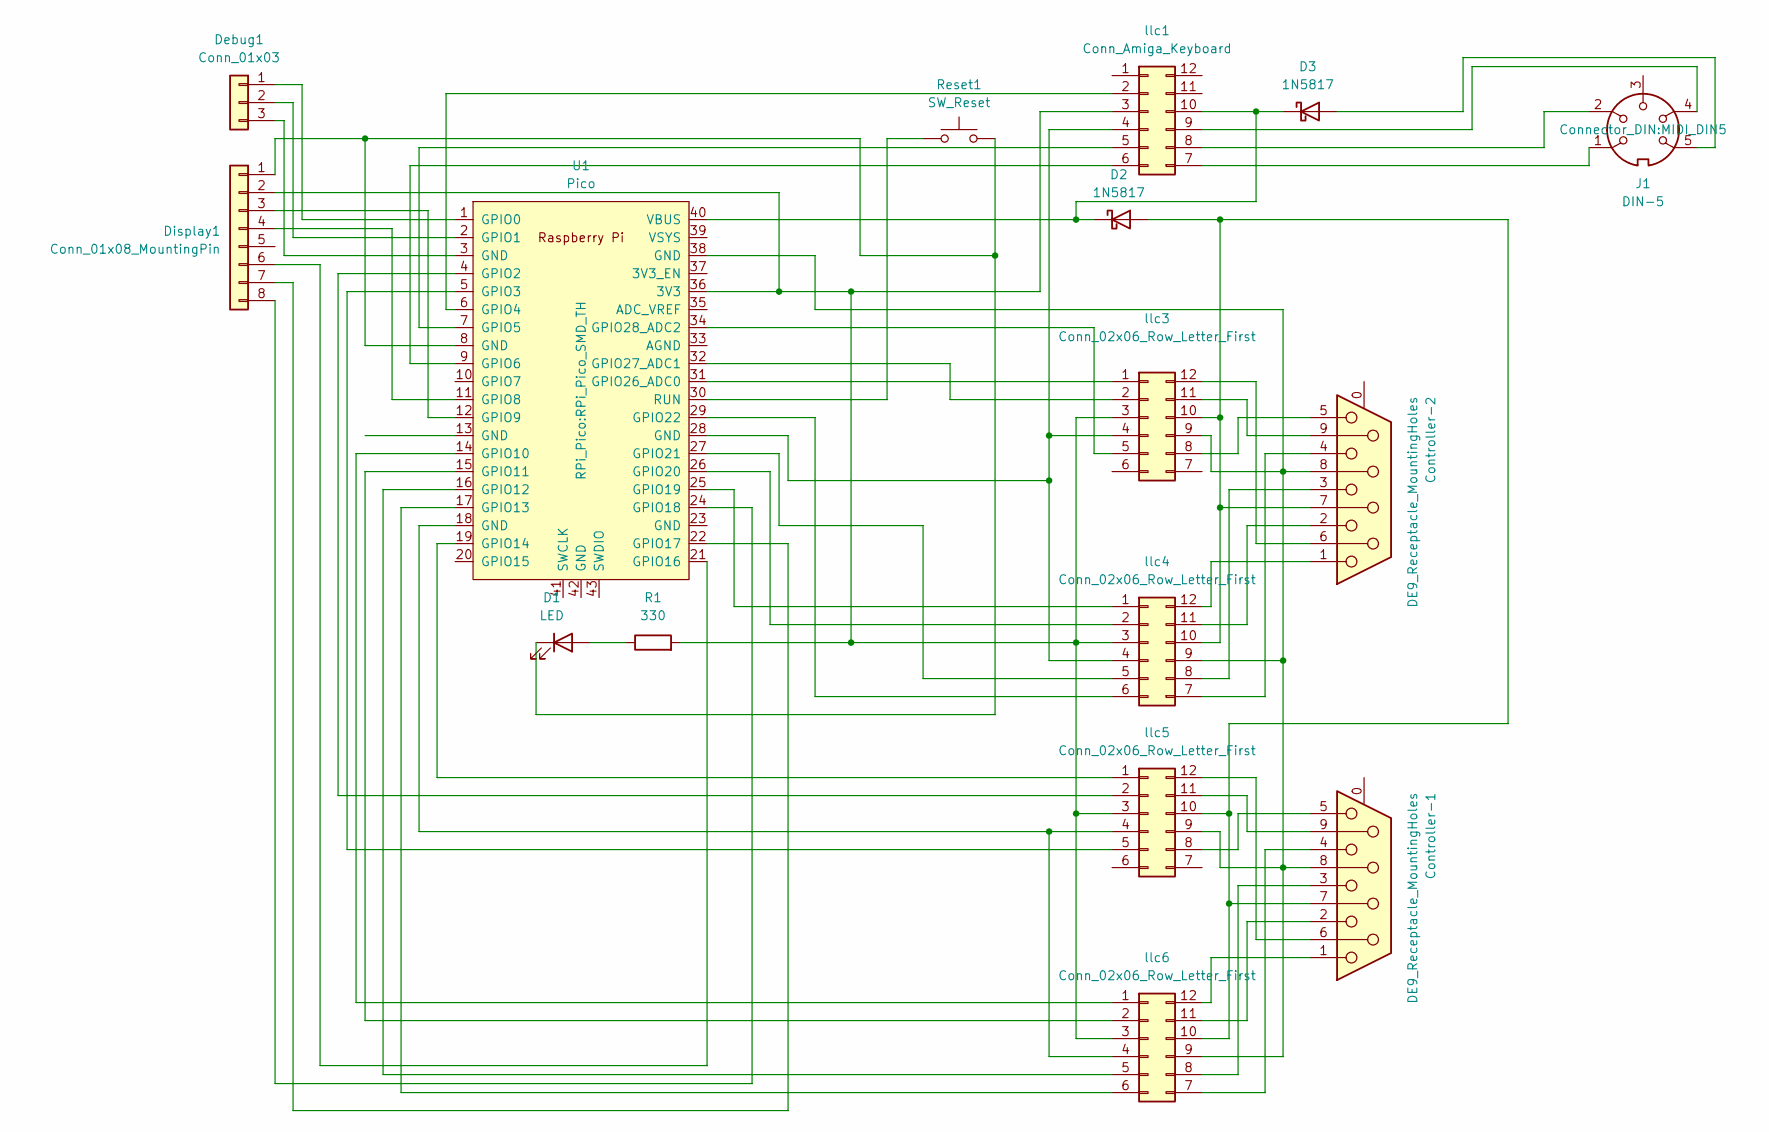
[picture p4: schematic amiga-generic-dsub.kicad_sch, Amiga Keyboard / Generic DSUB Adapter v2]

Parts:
Controller-1, Controller-2: DE9_Receptacle_MountingHoles; DSUB-9_Pins_Horizontal_P2.77x2.84mm_EdgePinOffset7.70mm_Hou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
D1: LED; LED_D3.0mm
D2, D3: 1N5817; D_DO-41_SOD81_P10.16mm_Horizontal
Debug1: Conn_01x03; PinSocket_1x03_P2.54mm_Vertical
Display1: Conn_01x08_MountingPin; PinSocket_1x08_P2.54mm_Vertical
J1: DIN-5; MIDI_DIN5
R1: 330; R_Axial_DIN0204_L3.6mm_D1.6mm_P7.62mm_Horizontal
Reset1: SW_Reset; SW_PUSH_6mm
U1: Pico; RPi_Pico_SMD_TH
llc1: Conn_Amiga_Keyboard; DIP-12_W10.16mm
llc3, llc4, llc5, llc6: Conn_02x06_Row_Letter_First; DIP-12_W10.16mm

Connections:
unnamed: D1.2 (A), R1.1
unnamed: D1.1 (K), Display1.1, Reset1.2, U1.8 (GND)
unnamed: Controller-1.7, Controller-2.7, D2.2 (A), llc3.10 (Pin_b3), llc4.10 (Pin_b3), llc5.10 (Pin_b3), llc6.10 (Pin_b3)
unnamed: D2.1 (K), D3.1 (K), U1.40 (VBUS), llc1.10 (Pin_b3)
unnamed: D3.2 (A), J1.5
unnamed: Debug1.1, U1.1 (GPIO0)
unnamed: Debug1.2, U1.2 (GPIO1)
unnamed: Debug1.3, U1.3 (GND)
unnamed: Display1.2, R1.2, U1.36 (3V3), llc1.3 (Pin_a3), llc3.3 (Pin_a3), llc4.3 (Pin_a3), llc5.3 (Pin_a3), llc6.3 (Pin_a3)
unnamed: Display1.3, U1.12 (GPIO9)
unnamed: Display1.4, U1.11 (GPIO8)
unnamed: Display1.6, U1.21 (GPIO16)
unnamed: Display1.7, U1.22 (GPIO17)
unnamed: Display1.8, U1.24 (GPIO18)
unnamed: U1.4 (GPIO2), llc5.2 (Pin_a2)
unnamed: U1.5 (GPIO3), llc5.5 (Pin_a5)
unnamed: U1.6 (GPIO4), llc1.2 (Pin_a2)
unnamed: U1.7 (GPIO5), llc1.5 (Pin_a5)
unnamed: U1.9 (GPIO6), llc1.6 (Pin_a6)
unnamed: U1.14 (GPIO10), llc6.1 (Pin_a1)
unnamed: U1.15 (GPIO11), llc6.2 (Pin_a2)
unnamed: U1.16 (GPIO12), llc6.5 (Pin_a5)
unnamed: U1.17 (GPIO13), llc6.6 (Pin_a6)
unnamed: U1.19 (GPIO14), llc5.1 (Pin_a1)
unnamed: U1.25 (GPIO19), llc4.1 (Pin_a1)
unnamed: U1.26 (GPIO20), llc4.2 (Pin_a2)
unnamed: U1.27 (GPIO21), llc4.5 (Pin_a5)
unnamed: U1.29 (GPIO22), llc4.6 (Pin_a6)
unnamed: U1.31 (GPIO26_ADC0), llc3.1 (Pin_a1)
unnamed: U1.32 (GPIO27_ADC1), llc3.2 (Pin_a2)
unnamed: U1.34 (GPIO28_ADC2), llc3.5 (Pin_a5)
unnamed: Reset1.1, U1.30 (RUN)
unnamed: U1.28 (GND), llc1.4 (Pin_a4), llc3.4 (Pin_a4), llc4.4 (Pin_a4)
unnamed: J1.4, llc1.9 (Pin_b4)
unnamed: J1.2, llc1.8 (Pin_b5)
unnamed: J1.1, llc1.7 (Pin_b6)
unnamed: Controller-2.6, llc3.12 (Pin_b1)
unnamed: Controller-2.9, llc3.11 (Pin_b2)
unnamed: Controller-1.8, Controller-2.8, U1.38 (GND), llc3.9 (Pin_b4), llc4.9 (Pin_b4), llc5.9 (Pin_b4), llc6.9 (Pin_b4)
unnamed: Controller-2.5, llc3.8 (Pin_b5)
unnamed: Controller-2.1, llc4.12 (Pin_b1)
unnamed: Controller-2.2, llc4.11 (Pin_b2)
unnamed: Controller-2.3, llc4.8 (Pin_b5)
unnamed: Controller-2.4, llc4.7 (Pin_b6)
unnamed: U1.18 (GND), llc5.4 (Pin_a4), llc6.4 (Pin_a4)
unnamed: Controller-1.6, llc5.12 (Pin_b1)
unnamed: Controller-1.9, llc5.11 (Pin_b2)
unnamed: Controller-1.5, llc5.8 (Pin_b5)
unnamed: Controller-1.1, llc6.12 (Pin_b1)
unnamed: Controller-1.2, llc6.11 (Pin_b2)
unnamed: Controller-1.3, llc6.8 (Pin_b5)
unnamed: Controller-1.4, llc6.7 (Pin_b6)

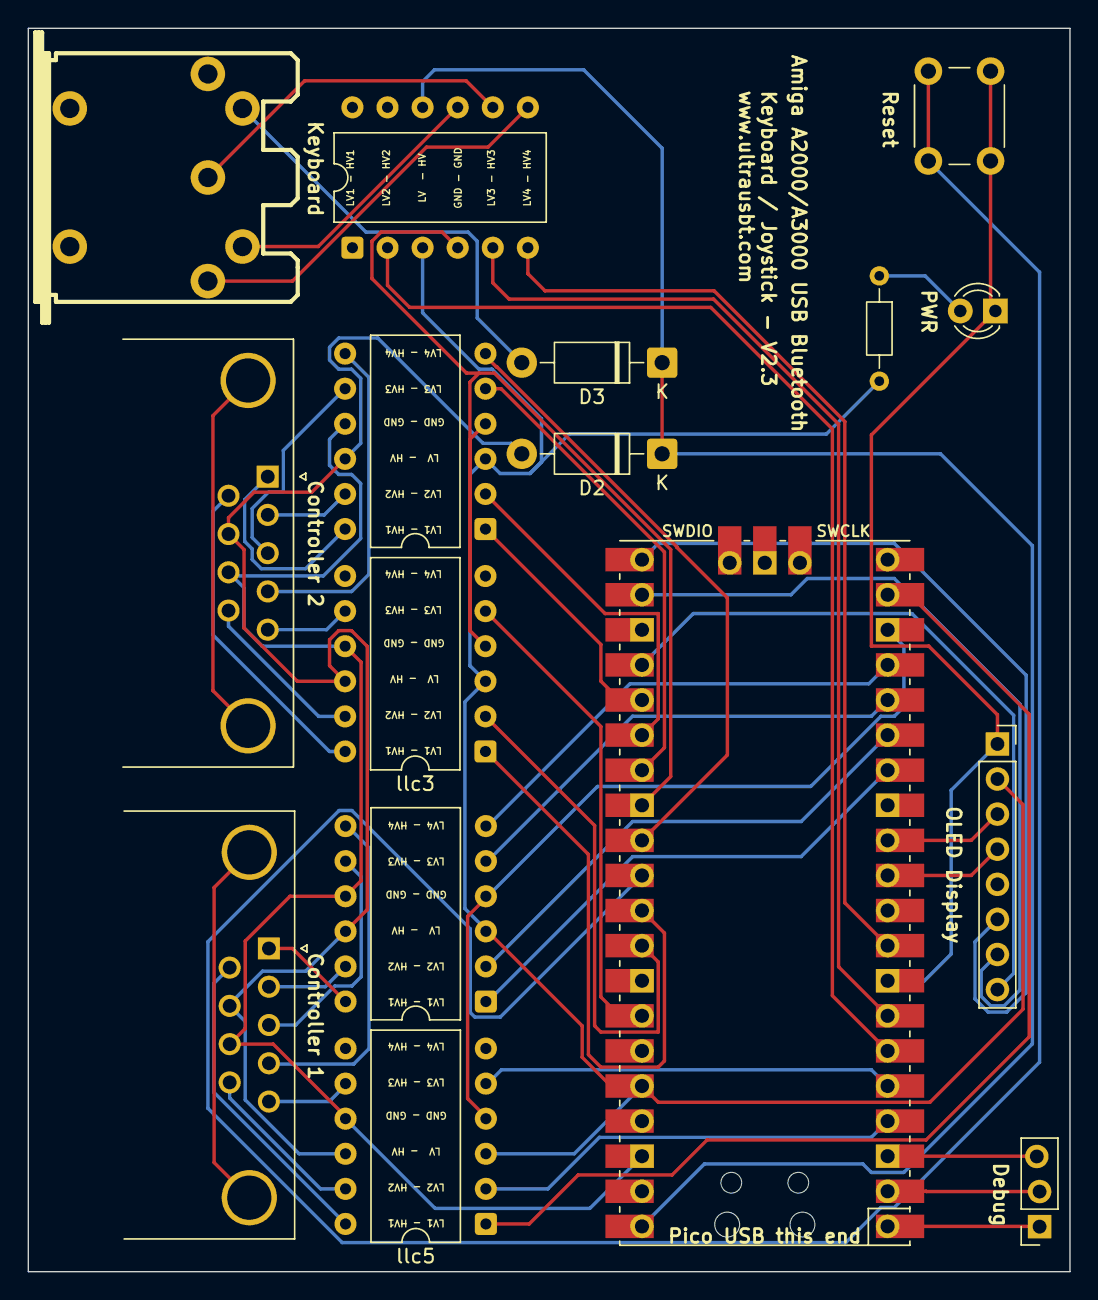
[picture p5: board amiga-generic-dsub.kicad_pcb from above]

Board: 2 copper layers, 75.4 x 90.0 mm, 16 parts (0 on the bottom side), 52 nets.

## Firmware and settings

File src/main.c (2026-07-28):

/**
 * this file is part of amigahid-pico, (c) 2021 just nine <nine@aphlor.org>
 * https://github.com/borb/amigahid-pico
 *
 * Modifications Copyright (c) 2026 ultrausbt
 * https://github.com/trickydee/ultrausbt-amiga
 *
 * released under the terms of the Eclipse Public License 2.0 (EPL-2.0).
 * please find the complete license text at https://spdx.org/licenses/EPL-2.0
 *
 * main entry point for amigahid-pico.
 */

// these reside within the tinyusb sdk and are not part of this project source
#include "bsp/board.h"
#include "tusb.h"
#include "pico/stdlib.h"
#include "pico/time.h"  // For watchdog timing
#include <stdio.h>

#include "config.h"
#include "tusb_config.h"

#include "usb_mode.h"
#if ENABLE_USB_DEVICE_MODE
#include "usb_hid_device.h"
#include "platform/amiga/keyboard_host_in.h"
#include "platform/amiga/mouse_host_in.h"
#include "platform/amiga/joystick_port2_host_in.h"
#endif

#include "display/display.h"
#include "platform/amiga/keyboard_serial_io.h"
#include "platform/amiga/quad_mouse.h"
#include "platform/amiga/joystick_port1.h"
#include "platform/amiga/joystick_port2.h"
#if HIDPICO_REV_ATARI_BOARD
#include "platform/amiga/cd32_pad.h"
#include "platform/amiga/port_mode.h"
#include "platform/amiga/mouse_config.h"
#endif
#include "platform/common/gpio_util.h"
#include "util/debug_cons.h"
#include "util/output.h"

#if ENABLE_BLUEPAD32
#include "bluepad32_init.h"
#include "bluepad32_platform.h"
#endif

// defined within usb_hid.c
extern void hid_app_task(void);
extern void switch_check_delayed_init(void);
#if ENABLE_BLUEPAD32
extern void process_bluepad32_devices(void);
#endif

// Software version is defined in config.h (single source for main, display, serial)

// main entry point
int main(void)
{
    // tinyusb board init; led, uart, button, usb
    board_init();

#if HIDPICO_REV_ATARI_BOARD
    // CRITICAL: Initialize all Amiga GPIOs to INPUT (safe state) BEFORE connecting to Amiga
    // This prevents 5V back-feeding damage when Amiga is powered but Pico is not
    // We do this immediately after board_init() to ensure clean GPIO state before:
    // - CYW43 initialization (if board_init() didn't already do it)
    // - I2C display initialization
    // - USB initialization
    // - Bluetooth initialization
    
    // Wait for power to stabilize (especially important if Amiga is already powered)
    sleep_ms(100);
    
    // Clear all GPIO direction cache and reset all Amiga GPIOs to INPUT (inactive/high) state
    // This ensures clean state even if Amiga is already powered and pull-ups are active
    // All GPIOs are set to INPUT with pull-up enabled - this is the SAFE state
    // GPIOs will only be set to OUTPUT when actively driving signals LOW
    // NOTE: This initializes all Amiga joystick/mouse GPIOs:
    //   Port 1: GPIOs 10-14 (directions + fire), GPIOs 2-3 (buttons 2-3)
    //   Port 2: GPIOs 19-22 (directions); fire/B2/B3 per HIDPICO_REVISION (Rev 5: 26-28, Rev 6: 7/0/1)
    // It does NOT affect CYW43 SPI pins or other system GPIOs
    amiga_gpio_reset_all_to_input();
#endif

    // Initialize UART for debug output (needed for version print)
    stdio_init_all();
    
    // Print version number at startup to verify build and serial output
    printf("\n");
    printf("========================================\n");
    printf("ultrausbt-amiga v%d.%d.%d (PCB rev %d)\n",
               SOFTWARE_VERSION_MAJOR, SOFTWARE_VERSION_MINOR,
               SOFTWARE_VERSION_PATCH, HIDPICO_REVISION);
    printf("========================================\n");
    printf("Port 1 toggle:    Shift + Left Amiga + J\n");
    printf("Llamatron mode:   Shift + Left Amiga + L\n");
    printf("Port 2 CD32 mode: Shift + Left Amiga + C\n");
    printf("Reset (classic):  Ctrl + Left Amiga + Right Amiga\n");
    printf("Reset (alt):      Ctrl + Left Amiga + Backspace\n");
    printf("========================================\n\n");

    dbgcons_init();
    
#if HIDPICO_REV_ATARI_BOARD
    // Print GPIO reset confirmation (dbgcons_init no longer clears the screen)
    printf("[GPIO] State cleared and reset to INPUT (before other init)\n");
    
    // Initialize the display (same order as Atari code: after dbgcons_init)
    // Splash screen is shown by default
    display_init();
#endif

    // Decide our USB role: HOST (normal, USB/BT -> Amiga) or DEVICE (reverse, read
    // a real Amiga keyboard/mouse and present as a USB HID keyboard+mouse to a PC).
    // Selected at boot from flash; toggled at runtime via OLED Settings (screen carousel).
    usb_mode_init();
    printf("USB mode: %s\n", usb_mode_is_device()
           ? "DEVICE (Amiga keyboard/mouse -> PC)"
           : "HOST (USB/BT -> Amiga)");
    printf("Switch USB mode: OLED Settings page (USB: Amiga / PC Kbd)\n");
    printf("========================================\n\n");

    // Bring up the TinyUSB stack in the selected role.
    usb_mode_start_usb();

#if ENABLE_USB_DEVICE_MODE
    if (usb_mode_is_device()) {
        // USB device mode: read the Amiga keyboard, Port 1 mouse, and Port 2 stick.
        // Do NOT init the Amiga output emulation (keyboard TX / quadrature / joy out / CD32 / BT).
        keyboard_host_in_init();
        mouse_host_in_init();
        joystick_port2_host_in_init();
#if HIDPICO_REV_ATARI_BOARD
        display_show_splash();
#endif
    } else
#endif
    {
        // we're single arch right now, but in future this should hand off to whatever the
        // configured arch is
        amiga_init();

        // start amiga mouse emulation
        amiga_quad_mouse_init();

#if HIDPICO_REV_ATARI_BOARD
        // Refresh splash screen after mouse type is loaded from flash
        // This ensures the correct title (AMIGA/ATARI) is displayed
        display_show_splash();
#endif

        // initialize joystick port 1 (shares GPIO pins with mouse)
        amiga_joystick_port1_init();

        // initialize joystick port 2 (dedicated GPIO pins for Revision 5/6)
        amiga_joystick_port2_init();
#if HIDPICO_REV_ATARI_BOARD
        cd32_port1_init();
        cd32_port2_init();
        port_mode_init();
        printf("[PORT] Boot Port 1 mode: %s (joy_flag=%d cd32=%d)\n",
               port_mode_port1_label(),
               amiga_joystick_port1_is_joystick_mode() ? 1 : 0,
               cd32_port1_is_enabled() ? 1 : 0);
        display_show_splash();
#endif

#if ENABLE_BLUEPAD32
        // initialize bluepad32 for Bluetooth keyboard support (Pico 2 W only)
        bluepad32_init();

#if HIDPICO_REV_ATARI_BOARD
        // Refresh splash screen after Bluetooth is initialized
        // This ensures the correct mode (USB+BT) is displayed
        display_show_splash();
#endif
#endif
    }

#if HIDPICO_REV_ATARI_BOARD
    // Watchdog: Check GPIO state periodically (every 5 seconds)
    // This is lightweight - only checks a sample of GPIOs to detect stuck states
    absolute_time_t last_watchdog_check = get_absolute_time();
    const uint32_t WATCHDOG_INTERVAL_MS = 5000;  // Check every 5 seconds
#endif

    while (1) {
#if ENABLE_USB_DEVICE_MODE
        if (usb_mode_is_device()) {
            // USB device mode: service the device stack and forward Amiga input.
            tud_task();
            usb_hid_device_task();
            keyboard_host_in_task();
            mouse_host_in_task();
            joystick_port2_host_in_task();
#if HIDPICO_REV_ATARI_BOARD
            display_handle_buttons();  // Settings carousel can toggle back to Device Mode
            display_tick();
#endif
            continue;
        }
#endif

        // run host mode jobs (hotplug events, packet io callbacks)
        tuh_task();
        switch_check_delayed_init();

        // amiga keyboard service routine
        amiga_service();

#if HIDPICO_REV_ATARI_BOARD
        cd32_service();
#endif

#if ENABLE_BLUEPAD32
        if (bluepad32_is_enabled()) {
            bluepad32_poll();
            bluepad32_pairing_tick();
            core1_bt_pause_watchdog_tick();
            core1_heartbeat_watchdog_tick();
            port_config_flush_pending();

            process_bluepad32_devices();
        }
#endif

#if HIDPICO_REV_ATARI_BOARD
        // Lightweight watchdog: Check GPIO state periodically (not every loop iteration)
        // This minimizes performance impact while still detecting stuck GPIO states
        absolute_time_t now = get_absolute_time();
        if (absolute_time_diff_us(last_watchdog_check, now) >= (WATCHDOG_INTERVAL_MS * 1000)) {
            if (amiga_gpio_watchdog_check()) {
                printf("[WATCHDOG] GPIO state recovery performed\n");
            }
            last_watchdog_check = now;
        }
        
        // Handle display button presses
        display_handle_buttons();
        display_tick();
#endif
    }

    return 0;
}

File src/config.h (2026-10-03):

/**
 * this file is part of amigahid-pico, (c) 2021 just nine <nine@aphlor.org>
 * https://github.com/borb/amigahid-pico
 *
 * Modifications Copyright (c) 2026 ultrausbt
 * https://github.com/trickydee/ultrausbt-amiga
 *
 * released under the terms of the Eclipse Public License 2.0 (EPL-2.0).
 * please find the complete license text at https://spdx.org/licenses/EPL-2.0
 *
 * hid-pico configuration
 *
 * PLEASE NOTE ALL PIN DESIGNATIONS ARE GPIO PIN NUMBERS - NOT PHYSICAL PIN NUMBERS
 */

#ifndef _CONFIG_H
#define _CONFIG_H

// Software version - single source of truth for main.c, OLED display, and serial output.
// v3.0.0: Rev 5/6 GPIO maps + Core 1 loop-counter mouse consume (Stadia-safe).
// v3.2.0: USB device mode — read a real Amiga keyboard/mouse and present as a USB HID to a PC.
// v4.0.0: Public release packaging — ultrausbt branding, LICENSE/NOTICE, quiet UART, docs.
// v4.0.1: Llamatron twin-stick allowed with Port 2 CD32 (still exclusive with Port 1 CD32).
// v4.0.2: Splash shows both port modes; Right=Port2, Middle+Left=BT pairing.
// v4.0.3: Port1 cycle includes Ami/Atari mouse; Port2 Joy↔CD32.
// v4.0.4: Splash "Controller Mode" heading; Ami Ms / Atr Ms labels; Port1 above Port2.
// v4.0.5: Atari mouse quadrature uses ATARI_UPDATE_PERIOD_US (~450us) on Core 1.
// v4.0.12: OLED Up/Down/# → Left/Right/Middle (swap Middle/Right GPIOs).
// v4.0.13: Settings carousel page — Clear BT pair + USB mode (no hold chords).
// v4.1.0: Release-candidate minor bump — Settings carousel + Host/Device UX.
// v4.1.1: Host Mode Port 2 Atari 2-btn stick → USB HID gamepad.
// v4.1.2: Host Mode gamepad on its own HID interface (macOS/Chrome detection).
// v4.1.3: Host Mode Port 2 dirs → Axis 0/1 + hat.
// v4.1.4: Stop mirroring dirs onto buttons 12–15 (bit 12 = Mode → MiSTer OSD/autofire).
// v4.2.0: Host Mode Port 2 Atari stick → USB gamepad (validated on Mac + MiSTer).
#ifndef SOFTWARE_VERSION_MAJOR
#  define SOFTWARE_VERSION_MAJOR 4
#endif
#ifndef SOFTWARE_VERSION_MINOR
#  define SOFTWARE_VERSION_MINOR 2
#endif
#ifndef SOFTWARE_VERSION_PATCH
#  define SOFTWARE_VERSION_PATCH 0
#endif

// USB device mode ("PC keyboard" mode): read a real Amiga keyboard (and mouse) on the
// keyboard connector / Port 1 and present the adapter to a PC as a USB HID keyboard+mouse.
// This is the reverse of normal operation. The two roles share one USB PHY, so only one is
// active at a time; the mode is chosen at boot from flash and toggled at runtime via the OLED.
#ifndef ENABLE_USB_DEVICE_MODE
#  define ENABLE_USB_DEVICE_MODE 1
#endif

// USB HID device identity presented to the host PC (Raspberry Pi VID + project PID).
#ifndef USB_DEVICE_VID
#  define USB_DEVICE_VID 0x2E8A
#endif
#ifndef USB_DEVICE_PID
#  define USB_DEVICE_PID 0xAB1A         /* "ABIA" ~ amiga */
#endif

// Log Amiga keyboard receive (frames, keycodes, 1 Hz KCLK heartbeat, resync) on UART.
// Default off for quiet builds; set to 1 when diagnosing device-mode keyboard issues.
// See doc/archive/amiga-usb-device-mode.md ("Diagnosing with KEYBOARD_IN_DEBUG").
#ifndef KEYBOARD_IN_DEBUG
#  define KEYBOARD_IN_DEBUG 0
#endif

// Verbose controller / HID report dumps (hex dumps, periodic stick samples).
// Mount/unmount and Bluepad32 connect messages stay on regardless. Also enable
// with CMake: add_compile_definitions(DEBUG_MESSAGES=1) for ahprintf + DIAG.
#ifndef CONTROLLER_DEBUG
#  define CONTROLLER_DEBUG 0
#endif

// Bluetooth gamepad pairing — Core 1 pause timing (Atari v22.1.0 / ultrausbt family)
#ifndef BT_GAMEPAD_DISCOVERY_SETTLE_MS
#  define BT_GAMEPAD_DISCOVERY_SETTLE_MS 30
#endif
#ifndef BT_GAMEPAD_CORE1_RESUME_DELAY_MS
#  define BT_GAMEPAD_CORE1_RESUME_DELAY_MS 100
#endif
// Force-release BT Core 1 pause if enumeration aborts without disconnect callback
#ifndef BT_CORE1_PAUSE_WATCHDOG_MS
#  define BT_CORE1_PAUSE_WATCHDOG_MS 45000
#endif
// Pause Core 1 during BLE gamepad discovery (Atari v22.1.0 default).
#ifndef BT_PAUSE_CORE1_ON_GAMEPAD_DISCOVERY
#  define BT_PAUSE_CORE1_ON_GAMEPAD_DISCOVERY 1
#endif
// If Core 1 heartbeat does not advance for this long (and not intentionally
// paused), attempt SEV wake then relaunch the quadrature loop.
#ifndef CORE1_HEARTBEAT_STALL_MS
#  define CORE1_HEARTBEAT_STALL_MS 500
#endif

// Remap one HID scancode to Amiga numpad * (AMIGA_KPAST / 0x5d — PrtScn on Amiga layout).
// Set HID code to 0 to disable. Logitech MX "| / ~ #" key → HID 0x32 (UART verified).
#ifndef KEY_REMAP_HID_TO_HELP
#  define KEY_REMAP_HID_TO_HELP  0x32
#endif

// Log HID scancodes on UART when keys are pressed (set 1 to discover remaps).
// Output: `[kbd] HID 0xNN -> Amiga 0xNN` per key down. See doc/archive/device_troubleshooting.md.
#ifndef KEYBOARD_HID_DEBUG
#  define KEYBOARD_HID_DEBUG  0
#endif

// Log the hard-reset key combo state machine on UART (Ctrl+LAmiga+RAmiga/Backspace).
// Prints ctrl/lamiga/ramiga/backspace/combo/in_reset whenever a tracked key changes.
#ifndef KEYBOARD_RESET_DEBUG
#  define KEYBOARD_RESET_DEBUG  0
#endif
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

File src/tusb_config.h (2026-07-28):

/**
 * this file is part of amigahid-pico, (c) 2021 just nine <nine@aphlor.org>
 * https://github.com/borb/amigahid-pico
 *
 * Modifications Copyright (c) 2026 ultrausbt
 * https://github.com/trickydee/ultrausbt-amiga
 *
 * released under the terms of the Eclipse Public License 2.0 (EPL-2.0).
 * please find the complete license text at https://spdx.org/licenses/EPL-2.0
 *
 * usb stack configuration; this file is included from the project source
 * by the tinyusb sdk so must be available within the include path
 */

#ifndef _TUSB_CONFIG_H
#define _TUSB_CONFIG_H

// rhport setting
#ifndef BOARD_TUH_RHPORT
#   define BOARD_TUH_RHPORT 0
#endif

// maximum speed permitted (which on a pico is usb 1.1)
#ifndef BOARD_TUH_MAX_SPEED
#   define BOARD_TUH_MAX_SPEED OPT_MODE_DEFAULT_SPEED
#endif

// should be defined by the pico board.h
#ifndef CFG_TUSB_MCU
#   error CFG_TUSB_MCU is missing; please check your configuration (ported to another board?)
#endif

#ifndef CFG_TUSB_OS
#   define CFG_TUSB_OS OPT_OS_NONE
#endif

// enable the host stack (if not explicitly enabled)
#ifndef CFG_TUH_ENABLED
#   define CFG_TUH_ENABLED 1
#endif

// enable the device stack so the adapter can act as a USB HID keyboard/mouse to a
// PC (reverse mode: read a real Amiga keyboard and forward keystrokes). Both stacks
// are compiled in; only one is tusb_init()'d at a time (single USB PHY). See usb_mode.c.
#ifndef CFG_TUD_ENABLED
#   define CFG_TUD_ENABLED 1
#endif

#if CFG_TUD_ENABLED
#   define CFG_TUD_HID            2  // IF0 kbd+mouse, IF1 gamepad (separate for macOS Gamepad API)
#   define CFG_TUD_ENDPOINT0_SIZE 64
#   define CFG_TUD_HID_EP_BUFSIZE 32  /* kbd/mouse + gamepad report (+ report ID) */
#endif

// max speed from board
#define CFG_TUH_MAX_SPEED BOARD_TUH_MAX_SPEED

#ifndef CFG_TUSB_MEM_SECTION
#   define CFG_TUSB_MEM_SECTION
#endif

#ifndef CFG_TUSB_MEM_ALIGN
#   define CFG_TUSB_MEM_ALIGN __attribute__ ((aligned(4)))
#endif

// usb descriptor buffer size
#define CFG_TUH_ENUMERATION_BUFSIZE 256

// supported devices & interfaces; tusb examples use a convention of multi-purpose
// constants where >0 may also mean multiple endpoints on a single device
#define CFG_TUH_HUB 4 // permit usb hubs (pico has a single port)
#define CFG_TUH_CDC 0 // no serial
#define CFG_TUH_HID 4 // keyboard/mouse/joystick; 4 endpoints maximum per device
#define CFG_TUH_MSC 0 // no mass storage
#define CFG_TUH_VENDOR 0 // not sure what this is but no anyway
#define CFG_TUH_XINPUT 2 // Xbox 360 / Xbox One / OG Xbox (XInput vendor driver)

// max device support (excluding hub)
#define CFG_TUH_DEVICE_MAX 16

// hid event buffer sizes
#define CFG_TUH_HID_EPIN_BUFSIZE 64
#define CFG_TUH_HID_EPOUT_BUFSIZE 64

// XInput (Xbox) buffer sizes
#define CFG_TUH_XINPUT_EPIN_BUFSIZE 64
#define CFG_TUH_XINPUT_EPOUT_BUFSIZE 64

#endif // _TUSB_CONFIG_H

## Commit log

2026-01-12 Update Pico SDK to 2.2.0 and improve build system
    - Update pico-sdk submodule to version 2.2.0 (fixes CMake 4.x compatibility)
    - Fix linker error: add extern to disp_write function pointer declaration
    - Configure build to output UF2 file to build/ instead of build/src/
    - Add build.sh script for automated building with submodule initialization
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2026-01-15 Add 200MHz overclock support and migrate to tusb_init()
    - Add 200MHz overclock for all Pico boards (pico, pico_w, pico2_w)
    - Configure manual PLL settings for Pico 2 W (RP2350) at 200MHz
    - Migrate from deprecated tuh_init() to tusb_init() with proper structure
    - Add performance optimization documentation
    - Add TinyUSB migration guide documentation
    All boards now run at 200MHz for improved performance. USB devices
    are working correctly with the new TinyUSB API.
    [main.c]
2026-01-15 Improve mouse slow movement sensitivity
    - Remove motion_divider logic that was skipping odd values
    - Process all motion immediately instead of accumulating
    - Check for new motion frequently (100us) for smooth processing
    - Fixes jerky/blocky behavior with slow mouse movements
    - Fast movements continue to work well
    [quad_mouse.c]
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2026-01-18 Fix: Add missing gyro/accel fields to bt_gamepad_t struct
    - Added gyro[3] and accel[3] fields to match uni_gamepad_t exactly
    - Fixes memory corruption causing gamepad lockup after pairing
    - Structure size now matches Bluepad32's uni_gamepad_t (48 bytes)
2026-01-19 Swap LEFT and DOWN GPIO mappings for joystick port 2
    - Swapped GPIO mappings to match documented pinout
    - DOWN: GPIO 22 -> GPIO 26 (QM2_AMIGA_VQ -> QM2_AMIGA_H)
    - LEFT: GPIO 26 -> GPIO 22 (QM2_AMIGA_H -> QM2_AMIGA_VQ)
    - Updated comments to reflect correct pinout
    - Build verified for both Pico (RP2040) and Pico 2 W (RP2350)
    [bluepad32_init.c, btstack_config.h, config.h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]
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2026-01-19 Optimize main loop and GPIO operations, fix analog stick calibration
    Main loop optimizations:
    - Add batched process_bluepad32_devices() function
    - Early returns when no Bluetooth devices connected
    - Reduces function call overhead in main loop
    GPIO optimizations:
    - Create shared gpio_util.c/h with direction state caching
    - Optimize joystick port 2 to only update changed pins (~75% reduction)
    - Add GPIO direction cache to avoid redundant gpio_set_dir() calls
    Analog stick calibration improvements:
    - Reduce deadzone from 120 to 60 (~12% of range) for better responsiveness
    - Add dominant axis detection to prevent false diagonals
    - If one axis is 2x stronger, ignore weaker axis to prevent drift-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
    [gpio_util.c, joystick_port2.c, main.c]
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2026-01-19 Improve mouse processing with speed-proportional timing
    Implement time-based quadrature generation based on Atari code:
    - Add speed-proportional timing: faster movement = shorter period = more responsive
    - Use time-based updates instead of fixed delays for better CPU efficiency
    - Add motion accumulation to handle rapid updates smoothly
    - Reduce MIN_PERIOD_US to 200us and MAX_SPEED to 30000 for better fast movement
    - Remove period recalculation during motion to prevent instability and skip-back
    - Keep period constant for given motion input for smooth, predictable movement
    This provides better responsiveness for fast movements while maintaining
    smoothness for slow movements, matching proven A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
    [quad_mouse.c]
2026-01-19 Add dual gamepad support and fix joystick port 1
    - Increase MAX_BT_GAMEPADS from 1 to 2 to support two gamepads
    - First gamepad (index 0) -> Joystick Port 2 (always active)
    - Second gamepad (index 1) -> Joystick Port 1 (only when in joystick mode)
    - Fix joystick port 1 direction mapping (swap LEFT/DOWN pins)
    - Use separate pins for each direction on port 1 (H/HQ/V/VQ)
    - Add GPIO state caching optimization to port 1 (matches port 2)
    - Add Shift + Left Amiga + J toggle for port 1 mode (mouse/joystick)
    - Disable mouse output when port 1 is in joystick mode
    - Add software version number display at startup
    - Update version banner to show toggle key combination
    [joystick_port1.c, keyboard_serial_io.c, main.c]
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2026-01-27 Fix DS5 pairing on Pico 2 W by adding flash-safe execution coordination
    - Add flash_safe_execute_core_init() to Core 1 entry function
    - Prevents flash access conflicts between Core 0 (Bluetooth) and Core 1 (mouse)
    - Required for SSP (Secure Simple Pairing) devices like DS5
    - Based on Atari keyboard adapter implementation
    - Fixes authentication failures during Bluetooth pairing on Pico 2 W
    [quad_mouse.c]
2026-01-27 Add GPIO clearing at startup and watchdog functionality
    - Add GPIO reset to INPUT state at startup (100ms delay + reset)
    - Add lightweight watchdog that checks GPIO state every 5 seconds
    - Watchdog detects stuck GPIOs and recovers by resetting to INPUT
    - Move GPIO reset message to after dbgcons_init() so it's visible
    - Add documentation for GPIO fix and watchdog functionality
    - Add OLED display library analysis document
    [gpio_util.c, main.c]
2026-01-27 Fix joystick port 1 left/right directions in joystick mode
    - Prevent mouse quadrature code from overriding joystick GPIO signals
    - Add joystick mode check in Core 1 mouse quadrature loop
    - Make port1_joystick_mode volatile with memory barriers for cross-core access
    - Remove build number from version, increment patch to 1.0.2
    - Remove old copyright headers from new files (display, bluepad32)
    - Remove unused old display files (ugui_config.h, README.md)
    [bluepad32_init.c, config.h, display.c]
2026-01-28 Fix joystick port 1 LEFT/RIGHT movement and button conflicts
    - Fix GPIO direction setting: Always set GPIO direction regardless of cache state
    This ensures GPIOs are correctly configured even if mouse code changed them
    - Add memory barriers for cross-core synchronization between joystick and mouse code
    - Disable Button 2/3 in joystick mode to prevent conflicts with LEFT/RIGHT directions
    (Button 2 uses GPIO 12 = LEFT, Button 3 uses GPIO 13 = RIGHT)
    - Add memory barriers in mouse quadrature code when checking joystick mode
    - Ensure mouse code skips updating LEFT/RIGHT GPIOs when joystick mode is active
    Fixes issue where LEFT/RIGHT joystick movement was not working due to:
    1. Mouse code ov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
    [config.h, display.c, gpio_util.c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]
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2026-01-29 Fix GPIO button mappings to resolve conflicts (v1.0.5)
    - Remapped all joystick buttons to eliminate GPIO conflicts:
    * Port 1 Button 2: GPIO 12 → GPIO 2
    * Port 1 Button 3: GPIO 13 → GPIO 3
    * Port 2 Button 2: GPIO 19 → GPIO 27
    * Port 2 Button 3: GPIO 18 → GPIO 28
    - Removed software workarounds that disabled buttons:
    * Port 1 buttons now work in both mouse and joystick modes
    * Port 2 Button 3 re-enabled (was disabled due to GPIO 18 conflict)
    - Updated documentation:
    * doc/amiga-code-atari-board-gpio-mappings.md: Complete GPIO mapping analysis
    * doc/gpio-fixes-todo.md: Square button fix documentation
    - Bumped version to v1.0.5
    All GPIO conflicts resolved. Hardware rem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
    [config.h, display.c, joystick_port1.c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]
2026-01-30 Remove debug logging and update splash screen (v1.0.11)
    - Remove all debug logging (GPIO-UTIL, JOY2-FIRE, JOY2-INIT, JOY2-RESET, GAMEPAD-DEBUG)
    - Document debug logging in doc/debug_logging_removed.md
    - Update splash screen branding: 'amigahid-pico' -> 'ultramegausb.com'
    - Fix mode indicator: Show 'USB+BT' when both USB and BT devices are connected
    - Ensure RST label is displayed when Bluetooth is enabled
    - Auto-refresh splash screen when BT device counts change
    - Bump version to v1.0.11
    [display.c, gpio_util.c, joystick_port2.c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]
2026-01-30 Fix mode display: Show USB+BT when Bluetooth is enabled
    - Simplify mode logic to check if Bluetooth is enabled (not device count)
    - Mode now correctly shows 'USB+BT' when Bluetooth is initialized
    - Removed unnecessary device count check for mode display
    [display.c]
2026-02-01 Fix button 2/3 handling and watchdog coverage
    - Added buttons 2 and 3 to watchdog sample (GPIOs 2, 3, 27, 28)
    - Fixed misleading comment in joystick_port2.c (GPIO 27 is Button 2, not UP)
    - Added Port 2 buttons 2 and 3 support in Llamatron mode
    - Removed Port 2 gamepad -> Port 1 mouse button mapping (Port 2 only controls Port 2)
    - Fixed mouse/gamepad button handling to only update on state changes (reduces log spam)
    - Added debug logging for mouse button GPIO state changes
    - Version bumped to v1.0.22
    - Created button_2_3_gpio_analysis.md documentation
    [config.h, display.c, gpio_util.c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]
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2026-02-02 Remap Port 2 Button 2 to GPIO 7 and add debug logging (v1.0.25)
    - Remap QM2_AMIGA_B2 from GPIO 27 (ADC1) to GPIO 7 (non-ADC)
    - Fixes high LOW voltage (397mV) issue on GPIO 27
    - GPIO 7 is non-ADC, should provide proper LOW voltage
    - Add debug logging for button 2/3 troubleshooting
    - Port 1 buttons 2/3: Added printf logging
    - Port 2 buttons 2/3: Enhanced logging with GPIO numbers
    - USB/Bluetooth gamepad: Added button press logging
    - GPIO utility improvements
    - Extend ADC disable to GPIOs 27 and 28 (in addition to GPIO 26)
    - Exclude buttons 2/3 from watchdog sampling to prevent interference
    - Update comments to reflect GPIO 7 for Port 2 Button 2
    - Mouse button handling: Alway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
    [config.h, display.c, gpio_util.c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]
2026-02-02 Remove D-pad UP filter - GPIO conflict was the root cause
    - Removed D-pad UP filter that was masking a GPIO conflict issue
    - Simplified CONVERT_GAMEPAD_TO_DIRECTIONS macro
    - GPIO conflicts have been resolved, filter no longer needed
    - Bump version to 1.0.31
    - UP+FIRE now works correctly on both joystick ports
    [display.c, main.c]
2026-02-02 Add Llamatron mode toggle on devices screen
    - Added usb_hid_get_llamatron_mode() and usb_hid_toggle_llamatron_mode() functions
    - LEFT button on devices screen now cycles through: MOUSE -> JOY -> LTRON -> MOUSE
    - Display shows "Port1: LTRON" when Llamatron mode is active
    - Fixed toggle cycle to properly return to MOUSE mode from LTRON
    - Bump version to 1.0.32
    [display.c, main.c]
2026-02-03 Add Atari mouse mode toggle and fix Bluetooth screen
    - Added mouse type enum (MOUSE_TYPE_AMIGA, MOUSE_TYPE_ATARI) to quad_mouse.h
    - Implemented mouse type toggle functions with GPIO pin swapping for Atari mode
    - Atari mode swaps GPIO pins 1 and 4 (V and HQ) on DB-9 connector
    - Added mouse type display on devices screen when Port 1 is in mouse mode
    - Added RIGHT button handler to toggle mouse type on devices screen
    - Added "Bluetooth Devices" title to Bluetooth screen (page 3)
    - Swapped J1 and J2 display on Bluetooth screen (J1 now shows index 1, J2 shows index 0)
    - Adjusted vertical positions on Bluetooth screen to accommodate title
    - Bump version to 1.0.33
    [display.c, main.c, quad_mouse.c]
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2026-02-04 Restore improved mouse processing and add mouse type flash persistence
    - Restore 16-bit accumulator mouse processing code from broken-flash branch
    - Uses phase extraction from upper 8 bits for smoother transitions
    - Proper direction change handling to prevent bounce-back
    - Mode-specific update periods (170μs Amiga, 450μs Atari)
    - Speed-proportional delta calculation with MOUSE_SDIV/SMUL/MINF/MAXF
    - Natural uint16_t wraparound without clamping (fixes boundary issues)
    - Continues processing while xcnt/ycnt > 0 even if delta is 0
    - Add mouse type flash persistence (Amiga/Atari toggle)
    - Created mouse_config.h and mouse_config.c
    - Loads mouse type from flash on startup
    - Sav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
    [display.c, main.c, quad_mouse.c]
2026-02-05 Update splash screen to show mouse type and refresh after flash load
    - Splash screen now displays 'ATARI' or 'AMIGA' based on current mouse type
    - Refresh splash screen after mouse type is loaded from flash on startup
    - This ensures correct title is shown immediately on boot
    - Bump version to 1.0.36
    [display.c, main.c]
2026-02-05 Update splash screen to show Port 1 mode and change LEFT button function
    - Splash screen title now shows current Port 1 mode:
    - AMIGA/ATARI when in mouse mode (based on mouse type)
    - JOYSTICK when in joystick mode
    - LLAMA when in llamatron mode (shortened from LLAMATRON)
    - Adjusted positioning: JOYSTICK moved left (x=5), LLAMA centered (x=25)
    - Changed LEFT button on splash screen to cycle Port 1 modes:
    - MOUSE -> JOY -> LLAMA -> MOUSE
    - Replaces Bluetooth toggle functionality
    - Splash screen refreshes after mode changes to show updated title
    [display.c]
2026-02-05 Fix splash screen to show correct USB+BT mode on startup
    - Refresh splash screen after Bluetooth initialization
    - This ensures 'USB+BT' is displayed correctly on first boot
    - Previously showed 'USB' until screens were cycled
    [main.c]
2026-02-09 Swap Port 2 Button 2 back to GPIO 27 and bump version to 1.0.37
    - Revert QM2_AMIGA_B2 from GPIO 7 back to GPIO 27 (ADC1)
    - Bump version from 1.0.36 to 1.0.37
    [config.h, display.c, main.c]
2026-02-10 Add PS4 DualShock 4 USB controller support (v1.0.40)
    - Integrated PS4 DualShock 4 controller from Atari IKBD codebase
    - Reduced deadzone from 50 to 20 for better analog stick sensitivity
    - Fixed stick calculation type (int8_t -> int16_t) to prevent overflow
    - Added extensive debug output for GPIO state changes and direction calculations
    - Fixed unused variable warnings (removed last_report from handle_event_mouse)
    - Fixed strncpy warnings by using snprintf with %.*s format
    - Version bumped to 1.0.40
    Note: Debug messages are still included for troubleshooting and will be removed in a future commit.
    [display.c, joystick_port2.c, main.c]
2026-02-11 Add Google Stadia controller support (v1.0.42)
    - Stadia controller (VID 0x18D1, PID 0x9400) mapped to Joystick Port 2
    - Dual report format: stadia-vigem (report ID 0x03) and 9-byte with optional ID
    - D-pad >= 8 treated as neutral so left stick is used when d-pad released
    - Left stick Y axis corrected (up/down) for Stadia convention
    - Deadzone 16 to match Atari HidInput.cpp (0x10) for same stick feel
    - doc/stadia-controller-verification.md: verification vs Atari build
    - Version bump to 1.0.42
    [display.c, main.c]
2026-02-11 Add Nintendo Switch Pro Controller support
    - Switch Pro, Joy-Con L/R/Pair, PowerA controllers (VID 0x057E, 0x20D6)
    - Full mode (49-byte) after 1s init; simple 7-byte mode before/fallback
    - USB handshake + subcommands for Pro (IMU, vibration, mode 0x30)
    - switch_check_delayed_init() called from main loop
    - Mapped to Amiga Joystick Port 2 (d-pad/left stick, A/B/X/ZR = fire/buttons)
    - OLED splash on mount
    [main.c]
2026-02-13 README: document supported USB controllers; misc fixes and v1.0.49
    - README: add Supported USB controllers section (PS3, PS4, Switch, Stadia, Xbox, generic HID, BT)
    - Mouse config: store in last flash sector (0x1FF000) to avoid overwriting firmware (fix hang when saving Atari mouse type)
    - Version bump to 1.0.49
    - Xbox: XInput host + HID fallback; joystick port 2 mapping
    - Second fire button: mapped to B2 GPIO on port 2 (all controllers) and port 1 (second BT gamepad); Llamatron unchanged
    - pico_flash_region.ld, tusb_config XInput, joystick/display/main/controller source updates
    [display.c, joystick_port2.c, main.c]
2026-02-13 PS5 DualSense USB support: joypad-os report layout, v1.0.51
    - Add ps5_controller.c/h (DualSense USB report ID 0x01, 64 bytes)
    - Parse USB report with sticks-first layout (x1,y1 at 0,1; buttons at 7,8)
    matching joypad-os sony_ds5_report_t; fixes constant up/down stick
    - Fire: Cross, R2 analog (throttle>200), R2 digital (buttons[1] bit)
    - Wire PS5 into usb_hid.c and CMakeLists.txt; display 'PS5 DualSense' on detect
    - Bump version to 1.0.51
    [display.c, main.c]
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2026-07-02 Add Port 1 CD32, OLED four-state cycle, and flash persistence (v2.2.0).
    Port 1 can run the CD32 shift protocol with BT gamepad #2, OLED left button cycles MOUSE/JOY/LLAMA/CD32, and Port 1 plus Port 2 CD32 settings persist across reboots.
    [cd32_pad.c, config.h, display.c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]
2026-07-03 Add dual CD32 support (v2.2.2) with known instability.
    Independent per-port shift registers, ISR starvation fix, and GPIO
    watchdog exclusion while CD32 is active. Document open issues: shift-
    register timing ghosts (B+A, Y+G) and BT slot routing on pad disconnect.
    [cd32_pad.c, config.h, gpio_util.c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]
2026-07-03 Restore v2.1.2 CD32 IRQ timing in dual-port driver (v2.2.5).
    Reverts experimental clock-edge and deferred JOYMODE handling that caused
    scrambled button mapping; per-port state machine again matches the known-good
    Port 2 implementation. Document UART log corruption in future work.
    [cd32_pad.c, config.h]
2026-07-03 Fix CD32 shift timing and add Logitech PrtScn key remap (v2.2.10).
    Advance CD32 button bits on CLOCK fall so DATA is stable before the Amiga samples on rise, reducing ghost presses in shift mode. Map HID 0x32 to Amiga numpad * for WHDLoad quit; disable UART keystroke debug by default and document how to enable it.
    [cd32_pad.c, config.h, keyboard_serial_io.c]
2026-07-06 Port Atari v22.1.0 BLE gamepad pairing hardening (v2.2.11).
    Refcounted Core 1 pause with __wfe(), busy_wait-only BT callbacks, and
    flash sector layout below BTstack TLV so Stadia/Xbox pairing no longer
    wedges quadrature mouse during bonding.
    [config.h, main.c, quad_mouse.c]
2026-07-12 Add HIDPICO_REVISION 6 GPIO map to avoid ADC pins (v2.2.12).
    Move Port 2 fire/B2/B3 from GPIO 26/27/28 to 7/0/1 for direct 5V on RP2350 without level shifters; default ENABLE_LEVEL_SHIFTER to 0 on Rev 6 and introduce HIDPICO_REV_ATARI_BOARD for shared Rev 5/6 code paths.
    [cd32_pad.c, config.h, display.c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]
2026-07-12 Fix config.h include order for HIDPICO_REV_ATARI_BOARD macro (v2.2.16).
    usb_hid.c and main.c used HIDPICO_REV_ATARI_BOARD before including
    config.h (where it's defined), silently disabling CD32 toggle, USB
    device counts, and CD32 GPIO init on this branch. Move the include
    earlier in both files, isolated from any Core 1 / BT pairing logic,
    to keep this branch a clean GPIO-only diff against main for Stadia
    lockup bisection.
    [main.c]
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2026-07-12 Fix Core 1 BT pause stacking after failed Stadia reconnect (v2.2.13).
    Stadia can rediscover after a mid-pair disconnect without calling
    on_device_disconnected, stacking pause depth and leaving Core 1 paused
    after a single resume-by-1. Pause only when depth is 0, force-release to
    0 on ready/disconnect, wake with SEV, and clear any orphaned pause on
    mouse reports.
    [config.h, quad_mouse.c]
2026-07-12 Recover wedged Core 1 after Stadia bonding (v2.2.15).
    Discovery pause is off and depth can still be 0 while mouse motion is
    dead — Core 1 appears stuck after BT flash. Replace Core 1 sleep_us/WFE
    with busy-waits, print heartbeat DIAG every 2s, and SEV-wake / relaunch
    amiga_quad_mouse_motion if the heartbeat stalls.
    [config.h, main.c, quad_mouse.c]
2026-07-12 DIAG: Port1 joy mode and mouse motion feed counters (v2.2.16).
    Core 1 heartbeat proved the motion loop is alive during Stadia lockups.
    Next: distinguish JOY-mode quadrature suppress vs missing delta feeds.
    [config.h, main.c, quad_mouse.c]
2026-07-12 Fix cross-core GPIO cache race; skip watchdog GPIO reset (v2.2.17).
    Stadia on Core 0 and mouse quadrature on Core 1 both RMW gpio_dir_cache.
    A torn update can make the watchdog reset Port 1 pins while motion is
    still being fed — matching alive Core1 + rising motion_feeds + dead
    cursor. Use atomic cache ops and disable auto GPIO recovery for this
    bisect; DIAG now reports consumed/quad_gpio counts.
    [config.h, gpio_util.c, quad_mouse.c]
2026-07-12 Add alternate keyboard reset combo + docs; bump to v3.1.0
    - Alternate hard-reset combo Ctrl+Left Amiga+Backspace for keyboards
    without a Right Amiga/GUI key (e.g. Logitech MX Keys Mini); classic
    Ctrl+Left Amiga+Right Amiga still works.
    - Reset asserted by holding keyboard CLK low with a 500ms minimum hold
    (RESET_ASSERT_MIN_HOLD_MS) so it fires despite keyboard combo ghosting;
    no scancodes bit-banged while held in reset.
    - Boot banner no longer clears the screen and lists all keyboard
    shortcuts (both reset combos included).
    - Gate DIAG/debug output behind DEBUG_MESSAGES / KEYBOARD_RESET_DEBUG.
    - Core 1 quadrature mouse loop no longer gates on absolute_time so mouse
    motion survives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
    [config.h, gpio_util.c, keyboard_serial_io.c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]
2026-07-12 Adopt gpio-avoid-adc Rev 6 pin map (Port 2 on 16-18, UI on ADC)
    Reconfigure HIDPICO_REVISION=6 to the feature/gpio-avoid-adc layout:
    - Port 2 fire/B2/B3 (and CD32 CLOCK/JOYMODE/DATA) move to 5V-tolerant
    header GPIO 16/17/18 (was 7/0/1).
    - OLED UI buttons move to ADC pins 26/27/28 (3.3V tactile switches only).
    - GPIO 0/1 reserved for debug UART (DEBUG_UART_TX/RX).
    Rev 5 default build is unchanged. Updated gpio_rev6_adc_avoidance.md,
    CD32_BUILD_SPEC.md, amiga-code-atari-board-gpio-mappings.md, and the
    CMakeLists revision comment to match. Verified both Rev 5 and Rev 6
    compile clean for pico2_w.
    [config.h]
2026-07-12 Add USB device mode: use an Amiga keyboard/mouse on a PC (v3.2.0)
    Reverses the adapter so a real Amiga keyboard (and Port 1 mouse) is read and
    presented to a host PC as a composite USB HID keyboard+mouse. Mode is persisted
    in flash and toggled at runtime by holding the OLED Middle+Right buttons for 2s
    (reboots into the selected role since the RP2350 has a single USB PHY).
    Key fixes found during hardware bring-up:
    - Keyboard resync recovery: the keyboard drops into a resync loop (one bit every
    ~143ms, seen as a steady ~7 KCLK edges/s) if its per-frame handshake is missed.
    The handshake is now issued immediately in the KCLK ISR on frame completion, and
    the task path ACKs stalled partial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
    [config.h, display.c, keyboard_host_in.c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]
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2026-07-22 Prepare v4.0.0 public release packaging.
    Rewrite the README for ultrausbt-amiga, archive historical docs behind a public index, bump to v4.0.0, and replace old board photos with the A2000 USB/BT adapter image.
    [config.h]
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2026-07-25 Use Atari quadrature update period on Core 1 (v4.0.5).
    Wire ATARI_UPDATE_PERIOD_US (~450us) into the Core 1 loop so Atari mouse mode no longer ticks at Amiga ~170us, which could drop edges on fast flicks.
    [config.h, quad_mouse.c]
2026-07-25 Improve Atari/Amiga quadrature mouse feel (v4.0.11).
    Widen pending motion, fix direction-cancel so fast flicks do not reverse,
    and keep period-gated edge emit after A/B testing.
    [config.h, quad_mouse.c]
2026-07-26 Remap OLED Up/Down/# to Left/Right/Middle (v4.0.12).
    Swap Middle and Right GPIOs so Down cycles Port 2 and # cycles screens;
    document the physical key map in the README.
    [config.h]
2026-07-27 Add OLED Settings carousel and harden USB mode persistence (v4.0.13).
    Move clear-pair, pairing toggle, and Host/Device switch onto a Settings
    page; fix Back navigation overflow and ensure USB role saves flush before reboot.
    [config.h, display.c, main.c]
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
